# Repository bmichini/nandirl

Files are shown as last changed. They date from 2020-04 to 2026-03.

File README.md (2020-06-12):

# nandirl
Project documentation can be found at [bmichini.github.io/nandirl](https://bmichini.github.io/nandirl/) 

## License
The hardware design files and software tools found in this repository are open source and released under the [Creative Commons Attribution-ShareAlike 4.0 International License](http://creativecommons.org/licenses/by-sa/4.0/) (CC BY-SA 4.0)

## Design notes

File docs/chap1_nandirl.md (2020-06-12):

## Chapter 1: 1-bit Register
One of the most basic things a computer needs to do is remember things, and it does this by storing "bits" i.e. 0's and 1's. One of the core components of a computer processor that performs this remembering function is called a "register". A 1-bit register has the ability to store 1-bit of information, i.e. it remembers whether it is currently a 0 or currently a 1. There are a few key details of a 1-bit register:

* **Input:** The register takes a digital input, which in the case of the nandirl computer is a 3.3V signal that is either low (0V-0.8V, representing a 0) or high (2.0V-3.3V, representing a 1).
* **Load:** The register does not always "listen" to its input. The Load signal (again, a digital 3.3V signal) tells the register whether to accept the input (Load=1) or ignore the input (Load=0) and retain its current value. The reason is that there will always be some signal on the input, but the computer may not always want a register to store that signal at the current instruction cycle.
* **Output:** The output signal (digital 3.3V signal) represents the current stored state of the register. It always outputs either low (0V) or high (3.3V) corresponding to its current stored value.
* **Clock:** Components in the computer that retain their internal state over time (like registers, which retain their "0" or "1" state) are termed "sequential logic" devices because they require a clock signal to synchronize discrete instants when something should happen. In the case of the register, there needs to be a distinct instant in time when the register updates it's new output (based on the Input and Load signals). The Clock input is the thing that signals this instant in time. Specifically, the clock signal is constantly pulsing from high to low to high to low (like a square wave), and the register uses the instant that the clock signal goes from high to low (the "falling edge") as its cue to update it's output signal based on the Input and Load signals. At all other times the output will not change, for reasons that will become clear later.

The nand2tetris course materials say very little about the actual hardware implementation of a register. The concept of a "Data Flip-flop" (or DFF) is given as a primitive building block without really saying how it works. Luckily, a DFF-based circuit that has a data input and updates its output on a clock signal edge can be implemented from NAND gates (with the help of the internet, of course). I based my DFF NAND implementation on [this helpful site](https://www.electronics-tutorials.ws/sequential/seq_4.html). The image below shows the implementation, a Data Flip-Flop followed by a Set-Reset Flip-Flop. The DFF is essentially the input stage, it is listening to the Data input when the clock is high. The instant the clock goes low the DFF stops listening to its input and a few nanoseconds later (the propagation delay from the Not gate on the clock input) the SRFF starts listening to its inputs, setting the overall output of the register. Hence the output updates itself precisely on the falling edge (the transition from high to low) of the clock signal.

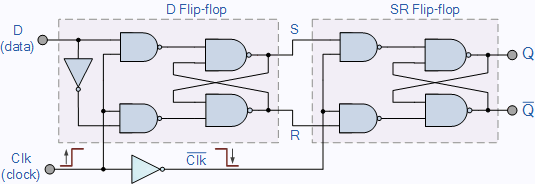
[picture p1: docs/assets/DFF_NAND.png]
DFF SR Latch circuit


Source: [https://www.electronics-tutorials.ws/sequential/seq_4.html](https://www.electronics-tutorials.ws/sequential/seq_4.html)

This doesn't take into account the Load input, which is achieved via the use of another basic circuit, the "Mux". The Mux has three inputs and one output:
A: A digital 3.3V signal that represents 1-bit input A
B: A digital 3.3V signal that represents 1-bit input B
Sel: A digital 3.3V signal that indicates whether the output should be A (Sel=0) or B (Sel=1)
Output: Digital 3.3V signal that is set to either A or B, depending on Sel

The Mux can also be implemented using three NAND gates, as shown in the circuit below. In the circuit, S is short for Sel, and S' means "not S", i.e. if S=0 then S'=1 and vice versa. To generate "not S", a 4th NAND gate is required to act as a "Not" gate, or a gate that simply inverts its own input. A Not gate can be made from a NAND gate by simply connecting the same input signal to both inputs of the NAND gate.

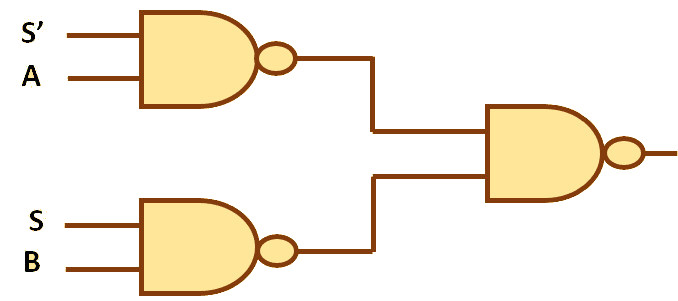
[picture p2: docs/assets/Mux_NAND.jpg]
Mux NAND gate implementation


Putting the DFF-SR and Mux circuits together, we get the fully-functional 1-bit register. Below is the full *schematic* for the circuit. A circuit schematic effectively captures the design of the circuit using boxes and symbols to represent devices, and wires to represent the connections between device pins:

[Schematic]
You'll notice that the NAND gates come in groups of four, and that's because the integrated circuit I've chosen to base the whole computer on incorporates 4 NAND gates into one chip. The [SN74ALVC00](https://www.digikey.com/product-detail/en/texas-instruments/SN74ALVC00DR/296-5101-1-ND/373963) is a 3.3V device made by Texas Instruments. I chose it because it has 4 gates in one package (to keep overall circuit board size down), it can drive up to 50mA of output current, and it has a very low maximum propagation delay of 3 nanoseconds. Propagation delay is the amount of time it takes for the device to generate the correct output after its two inputs are set. Once the full computer is built out signals are going to have to make their way through a lot of these gates in series, so the lower the propagation delay the faster signals will move through the computer and, ultimately, the faster the computer will be.

In summary, a 1-bit register circuit takes 12 total NAND gates to implement (8 for the DFF-SR circuit, and 4 for the Mux), and can be encapsulated into this functional block:
[Heir circuit]

Here's a video showing a breadboard prototype of the circuit using larger DIP versions of the quad NAND chips. The Red LED is connected to the output, Green is Load, Yellow is Input, and Blue is Clock. You'll notice that the output doesn't change until the clock goes from On to Off (the falling edge). When this happens, the Output will either match the current Input (if Load is On), or it will keep its previous value (if Load is Off). FYI The little red switches that I'm using to set Input and Load are called "DIP switches". Having designed and prototyped a 1-bit register, the next chapter will put 16 of these together to form a 16-bit register, and go through the process of designing a printed circuit board (PCB) that can be custom manufactured!

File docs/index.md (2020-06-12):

# nandirl
**nandirl** is a real-life open hardware implementation of the [nand2tetris](https://www.nand2tetris.org/) "Hack" computer architecture using custom printed circuit boards and discrete NAND gates. To my knowledge, this is the first NAND-based hardware implementation of the Hack computer. The hardware design is modular, so that individual boards roughly correspond to the project assignments presented in the nand2tetris course. I used the free and open source [KiCad](https://kicad-pcb.org/) design suite for schematic capture and PCB design. Blog-style chapters explaining the nandirl design are accompanied by tutorials intended to cover the basics of DIY hardware design.

>**Before you dig in, a quick request:**
> I built this project during the global COVID-19 pandemic and the ensuing months-long stay-at-home order. I am very fortunate to be in a position where I can work remotely during the day and also have the means to work on this project at night. I am grateful for that opportunity, but also realize that it is a privilege that many in my community do not have. Underserved communities have been disproportionately affected by the COVID outbreak for many reasons, including the financial necessity to continue working high-exposure jobs throughout the pandemic and the many institutional disadvantages that lead to worse health outcomes. In recognition of this, for every $1 that I spent on hardware and components for this project, I donated $1 spread across the charities in my area (listed below) that have been assisting the underserved through the COVID crisis. If you find this project interesting and you have the financial means to contribute, I'd encourage you to donate to these organizations or similar charities in your area. Thanks for your consideration!

## Table of Contents
For those curious about how the hardware was designed and built, the chapters below are my best attempt at documenting the project. Each chapter has a nandirl design component, followed by a generic hardware design component. The latter may be useful for hobbyists interested in the overall process of going from a circuit idea to a working PCB. For the HW design components, the free/open source KiCad suite is used.

**Disclaimer:** I am definitely not an expert when it comes to hardware design. It is not my day job. My credentials are based solely on informal DIY experience and bumbling trial-and-error. Consider yourself warned!

| Chapter | nandirl | HW design |
| --- | --- | --- |
| 0 | Intro: The nand2tetris "Hack" Architecture | Intro: DIY Hardware Design Overview |
| 1 | 1-bit Register | Schematic Capture and Custom Components |
| 2 | 16-bit Register | Nets and Heirarchical Schematics |
| 3 | Program Counter | Component Selection (Digikey+Datasheets) |
| 4 | Read-only Memory (ROM) | PCB Layout and Routing |
| 5 | Random Access Memory (RAM) | Design Checks and Fabrication Outputs |
| 6 | Arithmetic Logic Unit (ALU) | PCB Fabrication, BOMs, and Stencils |
| 7 | Clock Generator | PCB Assembly, Hotplate, and Solder Bridges |
| 8 | Motherboard | Board Bring-up Checklist |
| 9 | Debugger | Rework (Nothing Works the First Time) |
| 10 | Running Programs | Useful Equipment, Tools, and Toys |

## License
The hardware design files and software tools found in this repository are open source and released under the [Creative Commons Attribution-ShareAlike 4.0 International License](http://creativecommons.org/licenses/by-sa/4.0/) (CC BY-SA 4.0)

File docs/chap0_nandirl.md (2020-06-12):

## Chapter 0: nand2tetris and the "Hack" computer architecture
Recently I've been obsessed with the Apollo spaceflight program, and of particular fascination to me is the Apollo Guidance Computer (AGC). There's a whole lot to say on the topic, but for the purposes of this introduction: I was reading one day that the logic circuits of the AGC are constructed entirely from NOR (Not OR) gates. What's a NOR gate? How could you make a computer out of them? What are logic circuits? That's when it hit me -- even though I've been programming them for over 20 years, *I have no idea how computers actually work in hardware*. I decided that I could no longer continue living in ignorance of a technology that so profoundly shapes our everyday lives. So I have endeavored to learn how computers work by constructing one from primitive logic gates, but instead of the NOR gates used on the AGC my computer will be made from NAND (Not AND) gates.

Starting out I obviously had no idea what goes into the design of such a computer, but luckily there are some wonderful and generous people out there who have gone out of their way to provide a comprehensive and free online course on the topic. The design I'll be using for my computer is based on the [nand2tetris](https://www.nand2tetris.org/) project that guides students through the architecture of a simple computer based on NAND gates, which the authors have named the "Hack" computer. If you're wondering what a NAND gate is, [this is a good place to start](https://logic.ly/lessons/nand-gate/). The lectures subsequently take students through the software implementation of Tetris for the Hack computer design. The course is awesome and I highly recommend it to anyone who wants to learn how computers work from the ground up. Given that the syllabus is focused on computer hardware and software *design*, there is no actual hardware and instead the computer is constructed using software that simulates hardware. The instructors don't focus on how you would build this computer *in real life*, and I haven't been able to find anyone on the internet who has actually done it. Hence I've named my project **nandirl**.

The remainder of this chapter is a high-level overview of the computer architecture that may be helpful in understanding how all of the components will ultimately fit together. Check out the [nand2tetris](https://www.nand2tetris.org/) course for a better explanation (it assumes no previous technical training or computer knowledge). 

If we zoom out all the way, our computer consists of these three main components:
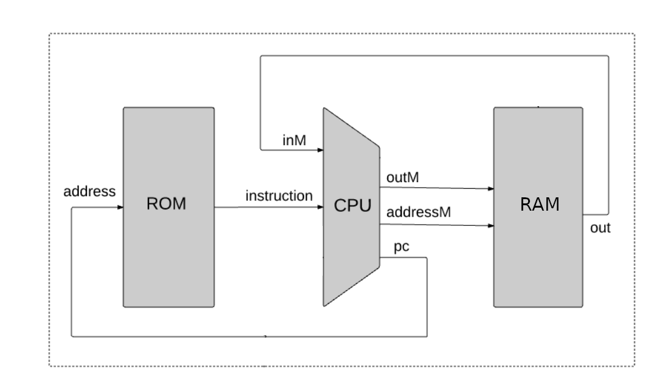
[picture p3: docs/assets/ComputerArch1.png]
Basic Computer Architecture
 
Source: [https://www.nand2tetris.org/course](https://www.nand2tetris.org/course) 
### ROM
ROM stands for "Read Only Memory". The ROM chip has a simple job in life -- given an *address*, the ROM provides an *instruction*. An address is simply a number, as is an instruction. Abstractly, imagine the ROM chip as a filing cabinet with many folders inside of it. The ROM chip gets an address, looks for the folder with the matching label, and hands back the contents of that folder (the instruction).

>More concretely, computers store numbers in *binary*. What's binary? The decimal number 5 in binary is **101**, because:
>
>**1**x2<sup>2</sup> + **0**x2<sup>1</sup> + **1**x2<sup>0</sup> =  **1**x4 + **0**x2 + **1**x1 = 5. 
>
>Since we've used three powers of 2, this is a *3-bit *binary number. The more powers of two we use the more numbers we can represent with our computer. The Hack computer, and thus the nandirl computer, is a *16-bit architecture*. Thus the smallest (unsigned) number we can represent is **0000 0000 0000 0000**:
>
 >**0**x2<sup>15</sup> +**0**x2<sup>14</sup> + **0**x2<sup>13</sup> + **0**x2<sup>12</sup>+ **0**x2<sup>11</sup> +**0**x2<sup>10</sup> + **0**x2<sup>9</sup> + **0**x2<sup>8</sup>+ **0**x2<sup>7</sup> +**0**x2<sup>6</sup> + **0**x2<sup>5</sup> + **0**x2<sup>4</sup>+ **0**x2<sup>3</sup> +**0**x2<sup>2</sup> + **0**x2<sup>1</sup> + **0**x2<sup>0</sup> = 0
>
>and largest (unsigned) number our computer can represent is **1111 1111 1111 1111**:
>
 >**1**x2<sup>15</sup> +**1**x2<sup>14</sup> + **1**x2<sup>13</sup> + **1**x2<sup>12</sup>+ **1**x2<sup>11</sup> +**1**x2<sup>10</sup> + **1**x2<sup>9</sup> + **1**x2<sup>8</sup>+ **1**x2<sup>7</sup> +**1**x2<sup>6</sup> + **1**x2<sup>5</sup> + **1**x2<sup>4</sup>+ **1**x2<sup>3</sup> +**1**x2<sup>2</sup> + **1**x2<sup>1</sup> + **1**x2<sup>0</sup> = 65535
>
>As it turns out, we can also represent every number in between with the right combination of 16 **1**'s and **0**'s, i.e. by adding the right combination of powers of 2 between 2<sup>0</sup> and 2<sup>15</sup>! 

Back to the ROM chip. The *address* passed into the ROM chip takes the form of 16 digital electrical signals, each at either a low voltage (representing a 0) or a high voltage (representing a 1). That corresponds to a 16-bit binary number, thus our ROM chip can store 65536 unique instructions! The *instruction* output, similarly, takes the form of 16 digital electrical signals. Each of those 16 individual instruction signals are going to tell the CPU what to do.

So to recap, ROM gets a 16-bit address. It finds that address in its filing cabinet and outputs the contents, which happens to be another set of 16 bits. Get a new address, look in a new memory location, send out a new instruction. In real life the 16 bits are represented as either high or low voltage (electrical potential) transmitted via 16 tiny metal wires going into the chip and 16 going out. It's called *read-only* memory because the contents of the memory does not change throughout the course of the computer's execution (it can only be *read*, not *written*). The 16-bits of instruction will go on to tell the CPU what to do, hence the ROM chip contains the *program* that the computer will execute. As a final note, ROM chips retain their memory even when the computer is powered off, so that the ROM will reliably provide the same addressed instruction data each and every time the computer is turned on.

### RAM
RAM stands for "Random Access Memory". It is very similar to ROM, in that it stores 16-bit numbers in filing cabinets that are indexed by 16-bit addresses. Get a 16-bit address, output the 16-bit number stored at that address. The thing that makes RAM different from ROM is that you can *write* a value to an address as well as *read* a value from an address. The chip uses to the same set of incoming address bits whether it's reading or writing. In order to know what value to write to memory, the RAM chip has 16-bits of data *input*. Hence there are two lines going into the RAM chip (*address* and *data input*) and one coming out (*data output*). 

In the computer architecture, the input *to* the RAM chip comes from the output of the CPU (hence it's labeled "outM" or "out to Memory" in the diagram). The output *from* the RAM chip goes...back into the CPU! This may seem odd, but the CPU is effectively using the RAM as short-term memory. The RAM doesn't store a program like ROM does -- in fact, all of the data stored in RAM resets to some unpredictable state every time the computer turns off. The RAM does, however, provide 65536 readable and writeable memory locations for the CPU to store and fetch 16-bit numbers during program execution. This comes in handy when the CPU does calculations and needs to store the result for use later on.

### CPU
So far the ROM and RAM chips appear only to store data. The CPU is where that data is manipulated. Here's a diagram showing the internals of the Hack CPU:
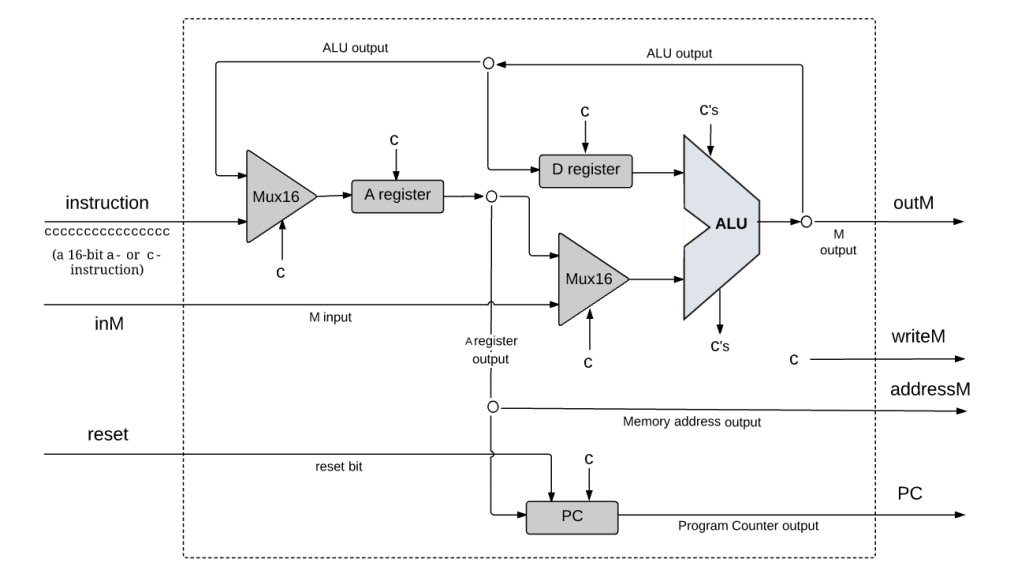
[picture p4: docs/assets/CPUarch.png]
Hack CPU Architecture

Source: [https://www.nand2tetris.org/course](https://www.nand2tetris.org/course) 
#### ALU
A good place to start breaking down the CPU architecture is the ALU, or Arithmetic Logic Unit. The ALU takes two 16-bit inputs, and provides one 16-bit output. As we'll see in more detail in a subsequent chapter, the ALU performs an operation on the two inputs and sends the result to its output. The ALU is designed to perform many different operations, and it knows which one to perform based on the instruction inputs (labeled "c's" going into the top of the ALU). These instructions are a subset of the 16 instruction bits that the ROM passes into the CPU. 

One such operation is simply to add the two inputs together (*x+y*). So if the first input *x* is 2 (**0000 0000 0000 0010**) and the second input *y* is 3 ((**0000 0000 0000 0011**), the output will be 5 (**0000 0000 0000 0101**). These 16 output bits are sent out to the RAM input (labeled "outM" or "out to memory"), but are also fed back into the other components of the CPU.

You may also notice that there are a few "c" bits coming out of the ALU as well as going in. These indicate whether the 16-bit number in the output is zero, or if it is negative. These checks on the output are going to ultimately determine what instuction (i.e. what address being sent to ROM) is picked out for execution in the next cycle.
#### Register
There are two registers (**A** and **D**) in the CPU. You can think of a register like RAM -- it holds a 16-bit number that can be read or written to. Except unlike our RAM which has 65536 addressable read/write values, a register has only *one*. This may seem like a serious limitation, but registers are very useful as a location to quickly store or read a single 16-bit number. Register has a 16-bit input, a 16-bit output, and a 1-bit *load* input. When *load*=1 (high voltage) the input will be saved and the output will take that value. When *load*=0 (low voltage), the input will be ignored and the output will keep its previous value. Just like the ALU, the *load* signal is set at each cycle by the incoming instruction bits.

In the CPU architecture, the **D** register simply holds data that will be used as the first input to the ALU. Notice that the output of the ALU winds back around into the input of the **D** register. If the corresponding instruction bit is set (the "c" bit that controls whether the register will load from the input), the ALU ouput will be saved back into the **D** register.

The **A** register can be used in the same was as **D** i.e. as the *second* input to the ALU, and the output from the ALU can be stored back into **A**. However, the **A** register also has a very specific and special function. Its output value sets the *address* that will be used for RAM. It also serves as the input to the PC register, which will be explained next.

#### PC (Program Counter)
At its core the Program Counter is simply a register just like **A** and **D**, in that it has an input that is optionally saved to its output at each step. The output of the **PC** is fed to the address input of the ROM chip. Hence, the program instruction that is going to be served up to the CPU in the next cycle is determined by the current output of the **PC** (that why it's called the *Program Counter*). If its *load* bit is set, it will save its input to its output (and recall that its input is the output of the **A** register). In that case the **PC** will take on this entirely new value and the next instruction will be from that new address. The program is said to have *jumped* to this new address. Otherwise, the **PC** has a neat feature that will automatically add 1 to its current value, effectively executing the *next* instruction in the ROM program memory.

This ability for the CPU to either *jump* to a new instruction or simply execute the *next* instruction is a fundamental feature of the CPU. This gives our program the ability to execute *conditional* statements i.e. jump to some new line of the program when some condition is true, or otherwise just keep on going to the next line of the program. If you're familiar with programming, this feature is the basis for building blocks such as *if*/*then*/*else*, *for*, *while*, etc. Recall that the **PC** will cause the program to jump if its *load* bit is set. It turns out that the CPU will set the *load* bit based on both the current instruction bits *and* the "zero" and "negative" checks that the ALU performs. Hence we'll have the ability in our program to do an ALU calculation and decide to jump or not based on the ALU result.

You may also notice a *reset* signal feeding into the **PC**. This is a 1-bit instruction that, when set to 1, will reset the current value of the **PC** to zero i.e. back to the beginning of our program.

#### Mux
The final component in the architecture is the **Mux**, which is short for "multiplexor". A Mux takes two inputs (*A* and *B*), and uses its incoming instruction bit (called the *select* input) to decide how to set its output. If *sel*=0, the output is set to *A*. If *sel*=1, the output is set to *B*. This will give our computer the ability to select whether the **A** register is loaded with the ALU output or the entire current instruction value (loading the entire 16-bits of instruction into **A** gives us the ability to store a number from our program straight into **A**). It also gives our computer the ability to select whether the second input to the ALU is the **A** register, or the current RAM value. As you probably guessed, the select bits for the two Muxes are set by the current CPU instruction coming from ROM.

***

Believe it or not, those are the only building blocks needed to create a simple computer from the ground up. We'll write programs for our computer, store them as addressed instructions in ROM, and let the computer execute them one-by-one. In my mind, at least, I think about this process like building a wind-up a toy, winding it up, putting it down, and letting it march its way through the world. In subsequent chapters I'll be building out each one of the major components in this architecture in real hardware.

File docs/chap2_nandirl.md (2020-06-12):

## Chapter 2: 16-bit Register
The nand2tetris computer is a 16-bit architecture. That means that data is passed around, stored, and manipulated in groups of 16-bits. The first full component of the computer I decided to take on is the 16-bit Register. It is, quite simply, a board that contains 16 1-bit registers where each register has its own Input and Output signals, but the Load and Clock signals are shared between all of them.

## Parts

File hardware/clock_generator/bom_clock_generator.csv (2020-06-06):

Reference | Quantity | Value | Footprint | Datasheet | Digikey PN
C1 | 1 | 22pF | Capacitor_THT:C_Disc_D5.0mm_W2.5mm_P5.00mm | ~
C3 C4 | 2 | 100uF | Capacitor_THT:CP_Radial_D8.0mm_P2.50mm | ~ | P15797CT-ND
C5 C6 | 2 | 100nF | Capacitor_THT:C_Disc_D5.0mm_W2.5mm_P5.00mm | ~ | BC5229CT-ND
C7 C2 | 2 | 0.1uF | Capacitor_SMD:C_1206_3216Metric | ~ | 399-C1206C104K5RAC7800CT-ND
J1 | 1 | DB9_Male | Connector_Dsub:DSUB-9_Male_Horizontal_P2.77x2.84mm_EdgePinOffset7.70mm_Housed_MountingHolesOffset9.12mm | ~ | AE10968-ND
R1 | 1 | 2.7K | Resistor_THT:R_Axial_DIN0207_L6.3mm_D2.5mm_P10.16mm_Horizontal | ~
R2 | 1 | 27K | Resistor_THT:R_Axial_DIN0207_L6.3mm_D2.5mm_P10.16mm_Horizontal | ~
R3 R5 | 2 | 33 | Resistor_SMD:R_1206_3216Metric | ~ | P33ECT-ND
R4 | 1 | 5k | Resistor_SMD:R_1206_3216Metric | ~ | P5.1KECT-ND
RV1 | 1 | 1M | Potentiometer_THT:Potentiometer_Bourns_PTV09A-1_Single_Vertical | ~ | PTV09A-4225F-B104-ND
TP1 TP4 TP3 TP2 | 4 | TestPoint | TestPoint:TestPoint_Bridge_Pitch2.54mm_Drill1.0mm | ~
U3 U1 U2 U4 | 4 | SN74HCS00PWR | Package_SO:TSSOP-14_4.4x5mm_P0.65mm |  | 296-SN74HCS00PWRCT-ND
U5 U6 | 2 | PI6C49CB04AQ | Package_SO:SOIC-8_3.9x4.9mm_P1.27mm |  | 31-PI6C49CB04AQ2WEXCT-ND

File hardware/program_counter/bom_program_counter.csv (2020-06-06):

Reference | Quantity | Value | Footprint | Datasheet | Digikey PN
C1 | 1 | 100uF | Capacitor_THT:CP_Radial_D8.0mm_P2.50mm | ~ | P15797CT-ND
C2 | 1 | 100nF | Capacitor_THT:C_Disc_D5.0mm_W2.5mm_P5.00mm | ~ | BC5229CT-ND
D15 D14 D13 D12 D11 D10 D9 D8 D7 D6 D5 D4 D3 D1 D2 D16 | 16 | LED | LED_THT:LED_D5.0mm | ~
J1 | 1 | DB37_Male | Connector_Dsub:DSUB-37_Male_Horizontal_P2.77x2.84mm_EdgePinOffset7.70mm_Housed_MountingHolesOffset9.12mm | ~ | AE10986-ND
R16 R1 R2 R3 R4 R5 R6 R7 R8 R9 R10 R11 R12 R13 R14 R15 | 16 | 1K | Resistor_SMD:R_1206_3216Metric | ~ | P1.0KECT-ND
U76 U10 U9 U8 U7 U6 U15 U14 U13 U12 U11 U20 U19 U18 U17 U16 U25 U24 U23 U22 U21 U30 U29 U28 U27 U26 U35 U34 U33 U32 U31 U40 U39 U38 U37 U36 U45 U44 U43 U42 U41 U50 U49 U48 U47 U46 U55 U54 U53 U52 U51 U60 U59 U58 U57 U56 U65 U64 U63 U62 U61 U70 U69 U68 U67 U66 U5 U4 U3 U2 U1 U75 U74 U73 U72 U71 | 76 | SN74HCS00PWR | Package_SO:TSSOP-14_4.4x5mm_P0.65mm |  | 296-SN74HCS00PWRCT-ND

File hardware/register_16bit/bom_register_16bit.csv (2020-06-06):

Reference | Quantity | Value | Footprint | Datasheet | Digikey PN
C1 | 1 | 100uF | Capacitor_THT:CP_Radial_D8.0mm_P2.50mm | ~ | P15797CT-ND
C2 | 1 | 100nF | Capacitor_THT:C_Disc_D5.0mm_W2.5mm_P5.00mm | ~ | BC5229CT-ND
D1 D2 D3 D4 D5 D6 D7 D8 D9 D10 D11 D12 D13 D14 D15 D16 D17 | 17 | LED | LED_THT:LED_D5.0mm | ~
J1 | 1 | DB37_Male | Connector_Dsub:DSUB-37_Male_Horizontal_P2.77x2.84mm_EdgePinOffset7.70mm_Housed_MountingHolesOffset9.12mm | ~ | AE10986-ND
R1 R17 R2 R3 R4 R5 R6 R7 R8 R9 R10 R11 R12 R13 R14 R15 R16 | 17 | 1K | Resistor_SMD:R_1206_3216Metric | ~ | P1.0KECT-ND
U1 U2 U3 U4 U5 U6 U7 U8 U9 U10 U11 U12 U13 U14 U15 U16 U17 U18 U19 U20 U21 U22 U23 U24 U25 U26 U27 U28 U29 U30 U31 U32 U33 U34 U35 U36 U37 U38 U39 U40 U41 U42 U43 U44 U45 U46 U47 U48 U49 | 49 | SN74HCS00PWR | Package_SO:TSSOP-14_4.4x5mm_P0.65mm |  | 296-SN74HCS00PWRCT-ND

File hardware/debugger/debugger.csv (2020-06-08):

Reference | Quantity | Value | Footprint | Datasheet | Digikey PN
C1 C2 C3 C4 C5 C6 C7 C8 C9 C10 C11 C12 | 12 | 0.1uF | Capacitor_SMD:C_1206_3216Metric | ~ | 399-C1206C104K5RAC7800CT-ND
J2 J1 | 2 | DB37_Male | Connector_Dsub:DSUB-37_Male_Horizontal_P2.77x2.84mm_EdgePinOffset7.70mm_Housed_MountingHolesOffset9.12mm | ~ | AE10986-ND
J3 | 1 | RJ45_Amphenol_RJMG1BD3B8K1ANR | Connector_RJ:RJ45_Amphenol_RJMG1BD3B8K1ANR | https://www.amphenolcanada.com/ProductSearch/Drawings/AC/RJMG1BD3B8K1ANR.PDF | RJMG1BD3B8K1ANR-ND
U1 | 1 | Teensy4.1 | nandirl logo:Teensy41
U10 U11 | 2 | PI6C49CB04AQ | Package_SO:SOIC-8_3.9x4.9mm_P1.27mm |  | 31-PI6C49CB04AQ2WEXCT-ND
U2 U3 U4 U5 U6 U7 U8 U9 | 8 | SN74CBTLV3257PWR | Package_SO:TSSOP-16_4.4x5mm_P0.65mm |  | 296-9138-1-ND

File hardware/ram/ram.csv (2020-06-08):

Reference | Quantity | Value | Footprint | Datasheet | Digikey PN
C2 C1 | 2 | 100uF | Capacitor_THT:CP_Radial_D8.0mm_P2.50mm | ~ | P15797CT-ND
C3 C4 | 2 | 100nF | Capacitor_THT:C_Disc_D5.0mm_W2.5mm_P5.00mm | ~ | BC5229CT-ND
C6 C5 C7 C8 | 4 | 0.1uF | Capacitor_SMD:C_1206_3216Metric | ~ | 399-C1206C104K5RAC7800CT-ND
J1 | 1 | RJ45_Amphenol_RJMG1BD3B8K1ANR | Connector_RJ:RJ45_Amphenol_RJMG1BD3B8K1ANR | https://www.amphenolcanada.com/ProductSearch/Drawings/AC/RJMG1BD3B8K1ANR.PDF | RJMG1BD3B8K1ANR-ND
J3 | 1 | DB25_Male | Connector_Dsub:DSUB-25_Male_Horizontal_P2.77x2.84mm_EdgePinOffset7.70mm_Housed_MountingHolesOffset9.12mm | ~ | AE10980-ND
J4 | 1 | DB37_Male | Connector_Dsub:DSUB-37_Male_Horizontal_P2.77x2.84mm_EdgePinOffset7.70mm_Housed_MountingHolesOffset9.12mm | ~ | AE10986-ND
U1 | 1 | 71V016SA12PHGI | Package_SO:TSOP-II-44_10.16x18.41mm_P0.8mm |  | 800-2609-5-ND
U12 | 1 | Teensy4.1 | nandirl logo:Teensy41
U3 U2 U4 U11 | 4 | SN74HCS00PWR | Package_SO:TSSOP-14_4.4x5mm_P0.65mm |  | 296-SN74HCS00PWRCT-ND
U7 U10 U6 U9 U5 U8 | 6 | 74LCX573FT | Package_SO:TSSOP-20_4.4x6.5mm_P0.65mm |  | 74LCX573FT(AJ)CT-ND

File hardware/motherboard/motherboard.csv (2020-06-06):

Reference | Quantity | Value | Footprint | Datasheet | Digikey PN
C1 | 1 | 220uF | Capacitor_THT:CP_Radial_D10.0mm_P5.00mm | ~ | P5183-ND
C2 C3 | 2 | 100uF | Capacitor_THT:CP_Radial_D8.0mm_P2.50mm | ~ | P15797CT-ND
C4 C5 | 2 | 100nF | Capacitor_THT:C_Disc_D6.0mm_W2.5mm_P5.00mm | ~ | BC5229CT-ND
D1 D2 D3 D4 D5 D6 D7 D8 D9 D10 D11 D12 D13 D14 D15 D16 D17 | 17 | LED | LED_SMD:LED_1206_3216Metric | ~ | 516-1436-1-ND
J12 | 1 | Barrel_Jack | Connector_BarrelJack:BarrelJack_CUI_PJ-063AH_Horizontal | ~ | CP-063AH-ND
J13 | 1 | TSR 1-2433 | Connector_PinHeader_2.54mm:PinHeader_1x03_P2.54mm_Vertical | ~ | 1951-2430-ND
J2 J1 J3 J4 J5 J10 J11 J7 | 8 | DB37_Female | Connector_Dsub:DSUB-37_Female_Horizontal_P2.77x2.84mm_EdgePinOffset7.70mm_Housed_MountingHolesOffset9.12mm | ~ | AE10941-ND
J6 J8 | 2 | DB25_Female | Connector_Dsub:DSUB-25_Female_Horizontal_P2.77x2.84mm_EdgePinOffset7.70mm_Housed_MountingHolesOffset9.12mm | ~ | AE10935-ND
J9 | 1 | DB9_Female | Connector_Dsub:DSUB-9_Female_Horizontal_P2.77x2.84mm_EdgePinOffset7.70mm_Housed_MountingHolesOffset9.12mm | ~ | AE10921-ND
R1 R2 | 2 | 2K | Resistor_SMD:R_1206_3216Metric | ~ | P2.0KECT-ND
R3 R4 R5 R6 R7 R8 R9 R10 R11 R12 R13 R14 R15 R16 R17 R18 R19 | 17 | 1K | Resistor_SMD:R_1206_3216Metric | ~ | P1.0KECT-ND
SW1 | 1 | SW_SPST | Button_Switch_SMD:SW_SPST_B3S-1000 | ~ | SW415-ND
SW2 | 1 | SW_SPST | nandirl logo:SPST Toggle Switch | ~ | EG4914-ND
U7 U6 U5 U4 U3 U2 U1 U10 U9 U8 U13 U12 U11 U20 U19 U18 U17 U16 U15 U14 U23 U22 U21 U26 U25 U24 U32 U31 U27 U28 U29 U30 | 32 | SN74ALVC00 | Package_SO:TSSOP-14_4.4x5mm_P0.65mm |  | 296-5104-1-ND

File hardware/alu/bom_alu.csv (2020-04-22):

Reference | Quantity | Digikey PN
C2 C1 C5 | 3 | P15797CT-ND
C3 C4 C6 | 3 | BC5229CT-ND
D1 D2 D3 D4 D5 D6 D7 D8 D9 D10 D11 D12 D13 D14 D15 D16 D19 D20 D21 D22 D23 D24 D25 D26 D27 D28 D29 D30 D31 D32 D33 D34 D17 D18 D35 D36 D37 D38 D39 D40 D41 D42 D43 D44 D45 D46 D47 D48 D49 D50 D51 D52 D53 D54 D55 D56 D57 | 57
J3 | 1 | AE10980-ND
J4 | 1 | AE10986-ND
Q1 Q2 | 2 | FMMT614CT-ND
R1 R2 R3 R4 R5 R6 R7 R8 R9 R10 R11 R12 R13 R14 R15 R16 R19 R20 R21 R22 R23 R24 R25 R26 R27 R28 R29 R30 R31 R32 R33 R34 R17 R18 R35 R36 R37 R38 R39 R40 R41 R42 R43 R44 R45 R46 R47 R48 R49 R50 R51 R52 R53 R54 R55 R56 R57 | 57 | P1.0KECT-ND
R58 R59 | 2 | P5.1KECT-ND
U1 U2 U3 U4 U5 U6 U7 U8 U9 U10 U11 U12 U13 U14 U15 U16 U17 U18 U19 U20 U21 U22 U23 U24 U25 U26 U27 U28 U29 U30 U31 U32 U33 U34 U35 U36 U37 U38 U39 U40 U41 U42 U43 U44 U45 U46 U47 U48 U49 U50 U51 U52 U53 U54 U55 U56 U57 U58 U59 U60 U61 U62 U63 U64 U65 U66 U67 U68 U69 U70 U71 U72 U73 U74 U75 U76 U77 U78 U79 U80 U81 U82 U83 U84 U85 U86 U87 U88 U89 U96 U93 U94 U95 U90 U91 U92 U97 U98 U99 U100 U105 U106 U102 U101 U107 U104 U103 U110 U109 U108 U111 U112 U113 U114 U115 U116 U117 U122 U123 U119 U118 U124 U121 U120 U127 U126 U125 U128 U129 U130 U131 U132 U133 U134 U139 U140 U136 U135 U141 U138 U137 U144 U143 U142 U145 U146 U147 U148 U149 U150 U151 U156 U157 U153 U152 U158 U155 U154 U161 U160 U159 U162 U163 U164 U165 U166 | 166 | 296-5104-1-ND

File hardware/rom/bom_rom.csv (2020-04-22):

Reference | Quantity | Digikey PN
C1 | 1 | P15797CT-ND
C2 | 1 | BC5229CT-ND
J1 | 1 | AE10986-ND
R2 R1 R4 R3 | 4 | P5.1KECT-ND
U1 | 1 | SST39VF200A-70-4I-EKE-ND

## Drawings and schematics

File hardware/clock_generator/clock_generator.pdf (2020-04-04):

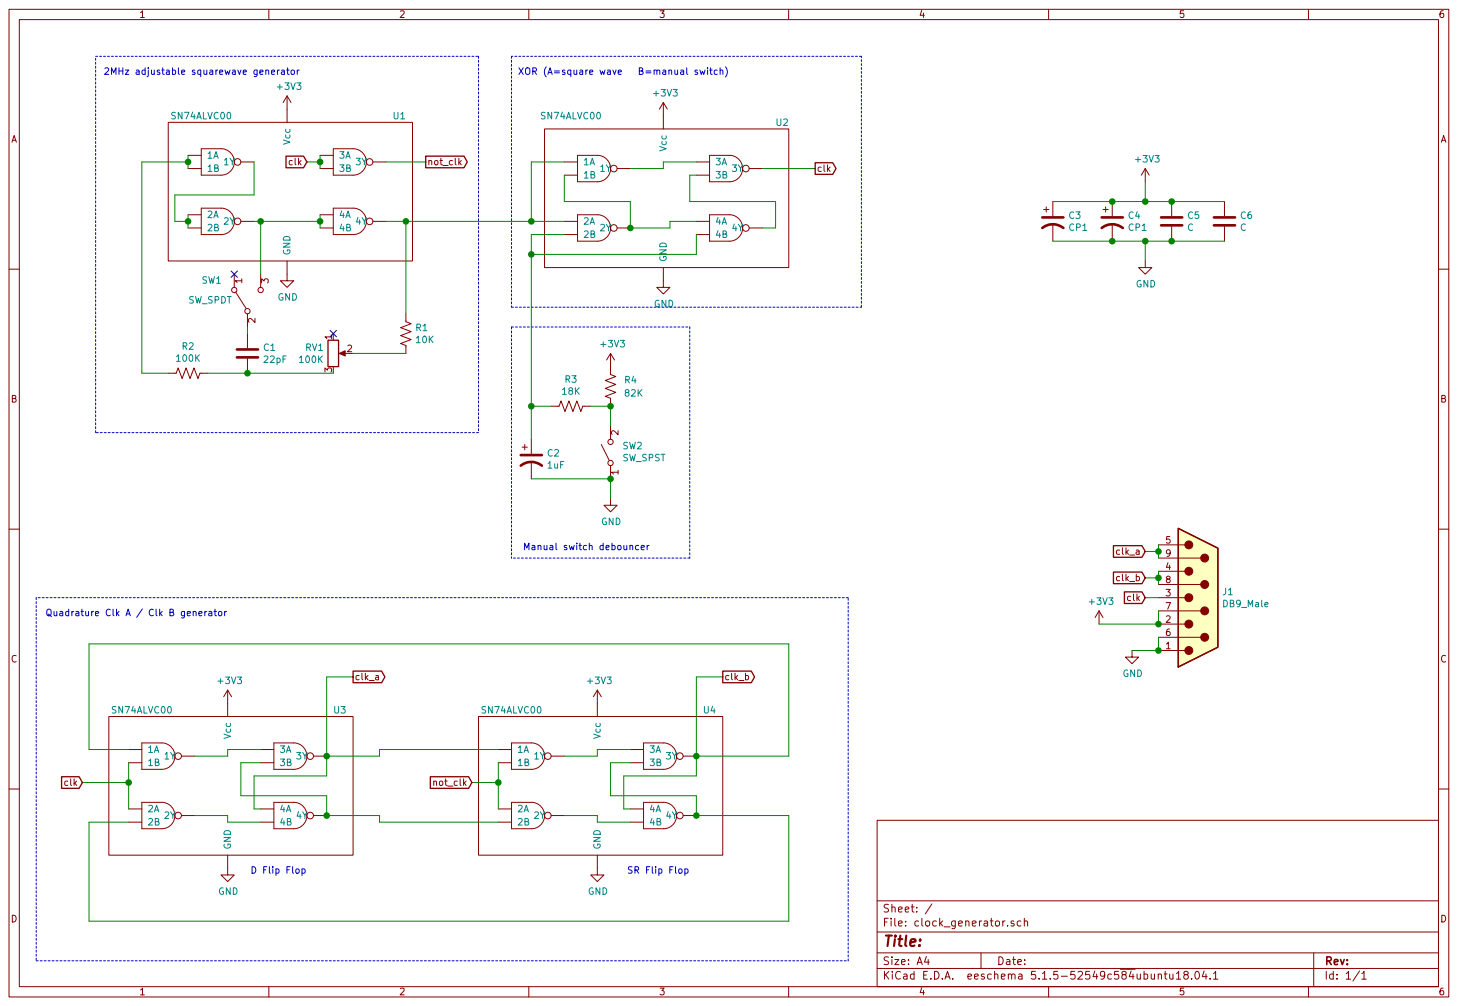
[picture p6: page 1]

XOR (A=square wave B=manual switch) Manual switch debouncer Quadrature Clk A / Clk B generator

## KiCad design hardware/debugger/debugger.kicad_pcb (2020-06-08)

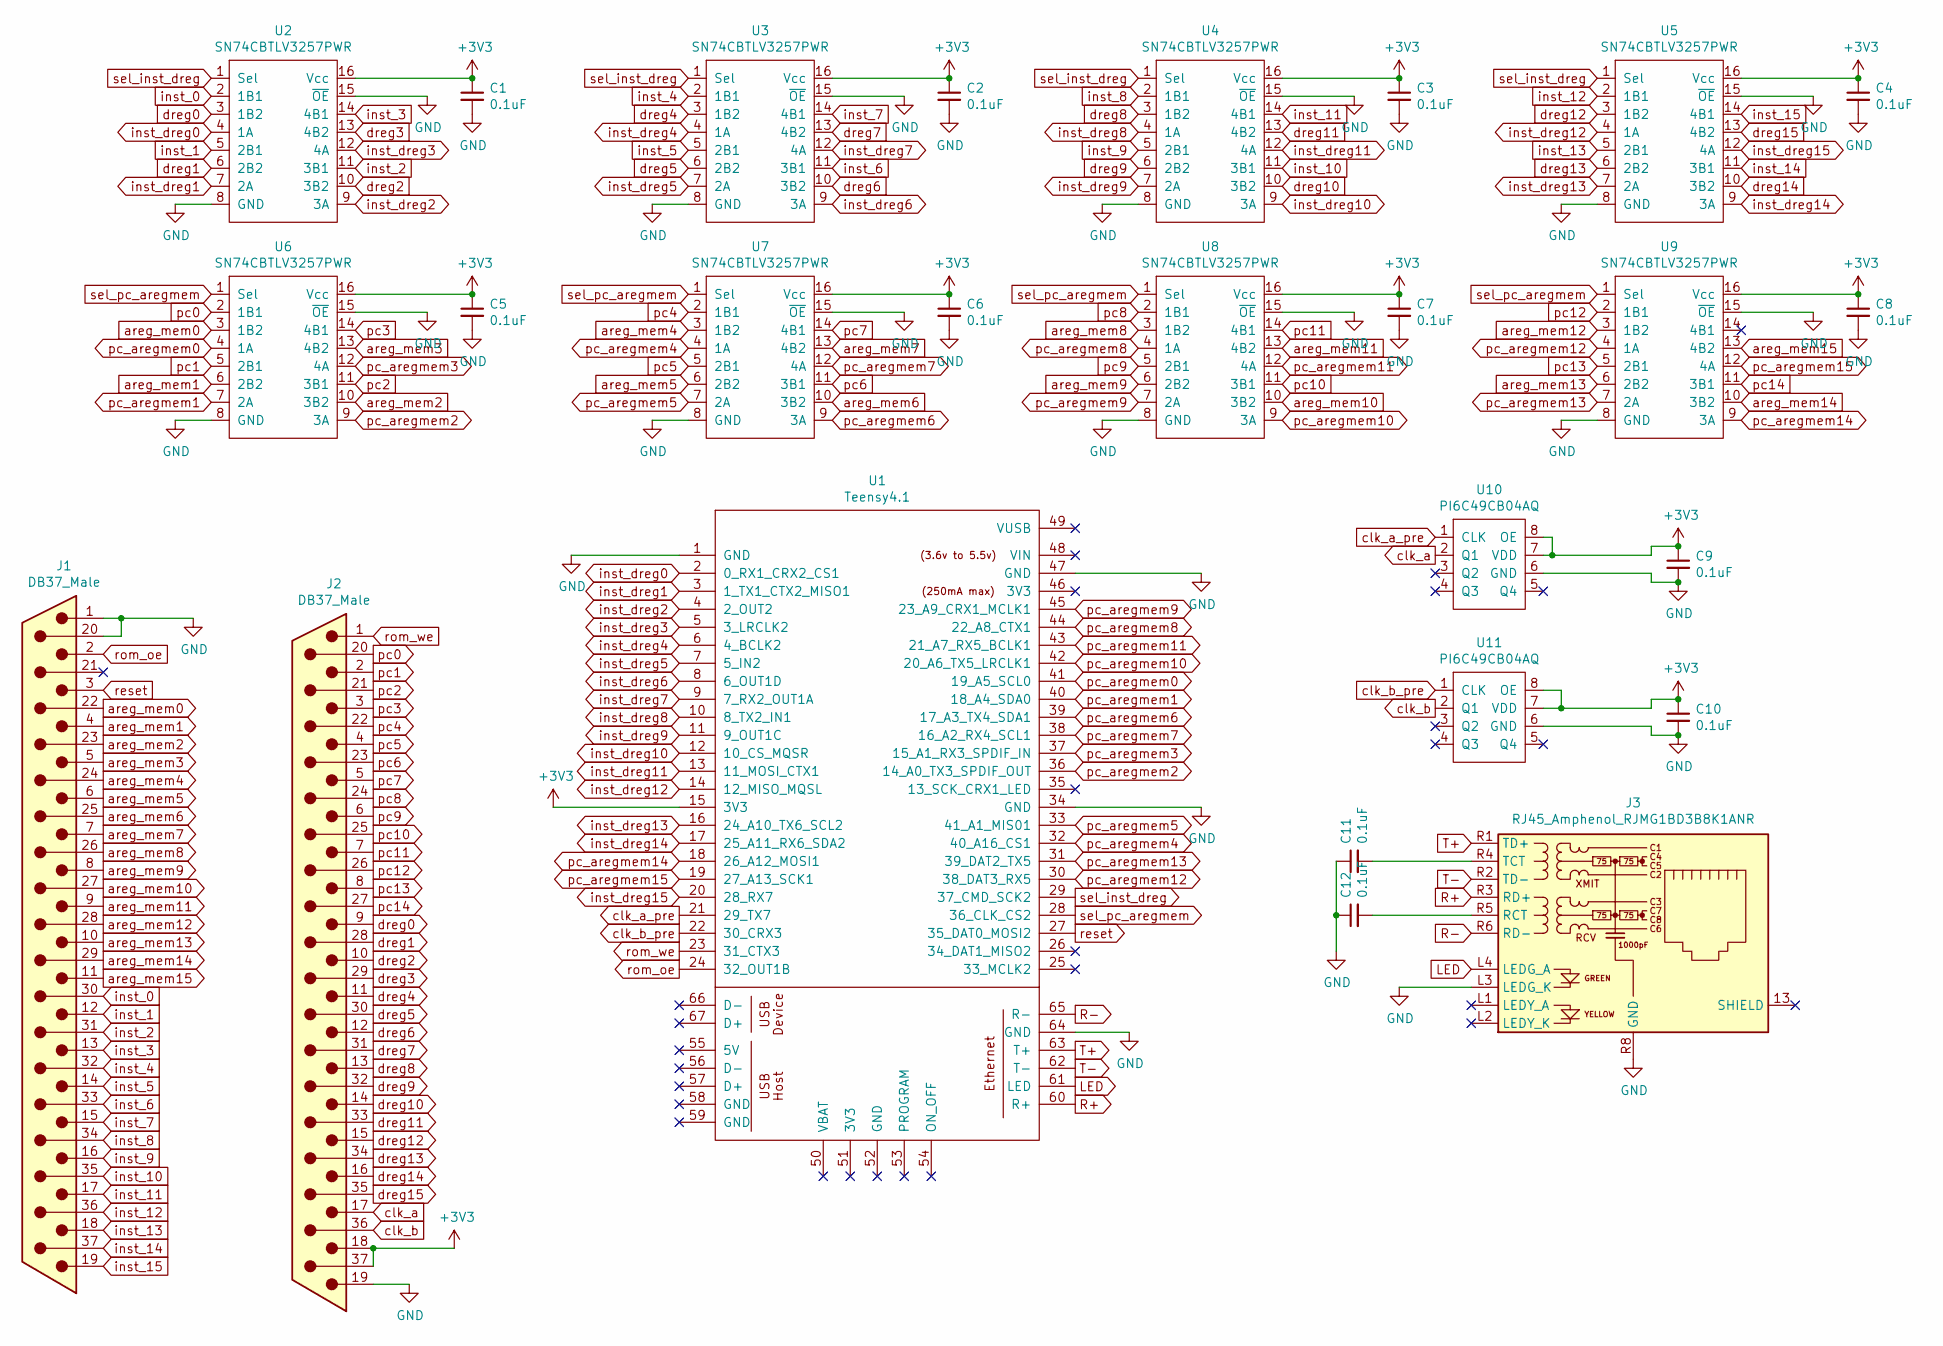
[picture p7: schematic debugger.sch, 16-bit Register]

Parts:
C1, C2, C3, C4, C5, C6, C7, C8, C9, C10, C11, C12: 0.1uF; C_1206_3216Metric; Digikey PN 399-C1206C104K5RAC7800CT-ND
J1, J2: DB37_Male; DSUB-37_Male_Horizontal_P2.77x2.84mm_EdgePinOffset7.70mm_Ho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; Digikey PN AE10986-ND
J3: RJ45_Amphenol_RJMG1BD3B8K1ANR; Digikey PN RJMG1BD3B8K1ANR-ND
U1: Teensy4.1; Teensy41
U2, U3, U4, U5, U6, U7, U8, U9: SN74CBTLV3257PWR; TSSOP-16_4.4x5mm_P0.65mm; Digikey PN 296-9138-1-ND
U10, U11: PI6C49CB04AQ; SOIC-8_3.9x4.9mm_P1.27mm; Digikey PN 31-PI6C49CB04AQ2WEXCT-ND

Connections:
+3V3: C1.1, C2.1, C3.1, C4.1, C5.1, C6.1, C7.1, C8.1, C9.1, C10.1, J2.18, J2.37, U1.15 (3V3), U2.16 (Vcc), U3.16 (Vcc), U4.16 (Vcc), U5.16 (Vcc), U6.16 (Vcc), U7.16 (Vcc), U8.16 (Vcc), U9.16 (Vcc), U10.7 (VDD), U10.8 (OE), U11.7 (VDD), U11.8 (OE)
GND: C1.2, C2.2, C3.2, C4.2, C5.2, C6.2, C7.2, C8.2, C9.2, C10.2, C11.1, C12.1, J1.1, J1.20, J2.19, J3.L3 (LEDG_K), J3.R8 (GND), U1.1 (GND), U1.34 (GND), U1.47 (GND), U1.64 (GND), U2.8 (GND), U2.15 (~OE), U3.8 (GND), U3.15 (~OE), U4.8 (GND), U4.15 (~OE), U5.8 (GND), U5.15 (~OE), U6.8 (GND), U6.15 (~OE), U7.8 (GND), U7.15 (~OE), U8.8 (GND), U8.15 (~OE), U9.8 (GND), U9.15 (~OE), U10.6 (GND), U11.6 (GND)
LED: J3.L4 (LEDG_A), U1.61 (LED)
unnamed: C11.2, J3.R4 (TCT)
unnamed: C12.2, J3.R5 (RCT)
R+: J3.R3 (RD+), U1.60 (R+)
R-: J3.R6 (RD-), U1.65 (R-)
T+: J3.R1 (TD+), U1.63 (T+)
T-: J3.R2 (TD-), U1.62 (T-)
areg_mem0: J1.22, U6.3 (1B2)
areg_mem1: J1.4, U6.6 (2B2)
areg_mem2: J1.23, U6.10 (3B2)
areg_mem3: J1.5, U6.13 (4B2)
areg_mem4: J1.24, U7.3 (1B2)
areg_mem5: J1.6, U7.6 (2B2)
areg_mem6: J1.25, U7.10 (3B2)
areg_mem7: J1.7, U7.13 (4B2)
areg_mem8: J1.26, U8.3 (1B2)
areg_mem9: J1.8, U8.6 (2B2)
areg_mem10: J1.27, U8.10 (3B2)
areg_mem11: J1.9, U8.13 (4B2)
areg_mem12: J1.28, U9.3 (1B2)
areg_mem13: J1.10, U9.6 (2B2)
areg_mem14: J1.29, U9.10 (3B2)
areg_mem15: J1.11, U9.13 (4B2)
clk_a: J2.17, U10.2 (Q1)
clk_a_pre: U1.21 (29_TX7), U10.1 (CLK)
clk_b: J2.36, U11.2 (Q1)
clk_b_pre: U1.22 (30_CRX3), U11.1 (CLK)
dreg0: J2.9, U2.3 (1B2)
dreg1: J2.28, U2.6 (2B2)
dreg2: J2.10, U2.10 (3B2)
dreg3: J2.29, U2.13 (4B2)
dreg4: J2.11, U3.3 (1B2)
dreg5: J2.30, U3.6 (2B2)
dreg6: J2.12, U3.10 (3B2)
dreg7: J2.31, U3.13 (4B2)
dreg8: J2.13, U4.3 (1B2)
dreg9: J2.32, U4.6 (2B2)
dreg10: J2.14, U4.10 (3B2)
dreg11: J2.33, U4.13 (4B2)
dreg12: J2.15, U5.3 (1B2)
dreg13: J2.34, U5.6 (2B2)
dreg14: J2.16, U5.10 (3B2)
dreg15: J2.35, U5.13 (4B2)
inst_0: J1.30, U2.2 (1B1)
inst_1: J1.12, U2.5 (2B1)
inst_2: J1.31, U2.11 (3B1)
inst_3: J1.13, U2.14 (4B1)
inst_4: J1.32, U3.2 (1B1)
inst_5: J1.14, U3.5 (2B1)
inst_6: J1.33, U3.11 (3B1)
inst_7: J1.15, U3.14 (4B1)
inst_8: J1.34, U4.2 (1B1)
inst_9: J1.16, U4.5 (2B1)
inst_10: J1.35, U4.11 (3B1)
inst_11: J1.17, U4.14 (4B1)
inst_12: J1.36, U5.2 (1B1)
inst_13: J1.18, U5.5 (2B1)
inst_14: J1.37, U5.11 (3B1)
inst_15: J1.19, U5.14 (4B1)
inst_dreg0: U1.2 (0_RX1_CRX2_CS1), U2.4 (1A)
inst_dreg1: U1.3 (1_TX1_CTX2_MISO1), U2.7 (2A)
inst_dreg2: U1.4 (2_OUT2), U2.9 (3A)
inst_dreg3: U1.5 (3_LRCLK2), U2.12 (4A)
inst_dreg4: U1.6 (4_BCLK2), U3.4 (1A)
inst_dreg5: U1.7 (5_IN2), U3.7 (2A)
inst_dreg6: U1.8 (6_OUT1D), U3.9 (3A)
inst_dreg7: U1.9 (7_RX2_OUT1A), U3.12 (4A)
inst_dreg8: U1.10 (8_TX2_IN1), U4.4 (1A)
inst_dreg9: U1.11 (9_OUT1C), U4.7 (2A)
inst_dreg10: U1.12 (10_CS_MQSR), U4.9 (3A)
inst_dreg11: U1.13 (11_MOSI_CTX1), U4.12 (4A)
inst_dreg12: U1.14 (12_MISO_MQSL), U5.4 (1A)
inst_dreg13: U1.16 (24_A10_TX6_SCL2), U5.7 (2A)
inst_dreg14: U1.17 (25_A11_RX6_SDA2), U5.9 (3A)
inst_dreg15: U1.20 (28_RX7), U5.12 (4A)
pc0: J2.20, U6.2 (1B1)
pc1: J2.2, U6.5 (2B1)
pc2: J2.21, U6.11 (3B1)
pc3: J2.3, U6.14 (4B1)
pc4: J2.22, U7.2 (1B1)
pc5: J2.4, U7.5 (2B1)
pc6: J2.23, U7.11 (3B1)
pc7: J2.5, U7.14 (4B1)
pc8: J2.24, U8.2 (1B1)
pc9: J2.6, U8.5 (2B1)
pc10: J2.25, U8.11 (3B1)
pc11: J2.7, U8.14 (4B1)
pc12: J2.26, U9.2 (1B1)
pc13: J2.8, U9.5 (2B1)
pc14: J2.27, U9.11 (3B1)
pc_aregmem0: U1.41 (19_A5_SCL0), U6.4 (1A)
pc_aregmem1: U1.40 (18_A4_SDA0), U6.7 (2A)
pc_aregmem2: U1.36 (14_A0_TX3_SPDIF_OUT), U6.9 (3A)
pc_aregmem3: U1.37 (15_A1_RX3_SPDIF_IN), U6.12 (4A)
pc_aregmem4: U1.32 (40_A16_CS1), U7.4 (1A)
pc_aregmem5: U1.33 (41_A1_MIS01), U7.7 (2A)
pc_aregmem6: U1.39 (17_A3_TX4_SDA1), U7.9 (3A)
pc_aregmem7: U1.38 (16_A2_RX4_SCL1), U7.12 (4A)
pc_aregmem8: U1.44 (22_A8_CTX1), U8.4 (1A)
pc_aregmem9: U1.45 (23_A9_CRX1_MCLK1), U8.7 (2A)
pc_aregmem10: U1.42 (20_A6_TX5_LRCLK1), U8.9 (3A)
pc_aregmem11: U1.43 (21_A7_RX5_BCLK1), U8.12 (4A)
pc_aregmem12: U1.30 (38_DAT3_RX5), U9.4 (1A)
pc_aregmem13: U1.31 (39_DAT2_TX5), U9.7 (2A)
pc_aregmem14: U1.18 (26_A12_MOSI1), U9.9 (3A)
pc_aregmem15: U1.19 (27_A13_SCK1), U9.12 (4A)
reset: J1.3, U1.27 (35_DAT0_MOSI2)
rom_oe: J1.2, U1.24 (32_OUT1B)
rom_we: J2.1, U1.23 (31_CTX3)
sel_inst_dreg: U1.29 (37_CMD_SCK2), U2.1 (Sel), U3.1 (Sel), U4.1 (Sel), U5.1 (Sel)
sel_pc_aregmem: U1.28 (36_CLK_CS2), U6.1 (Sel), U7.1 (Sel), U8.1 (Sel), U9.1 (Sel)

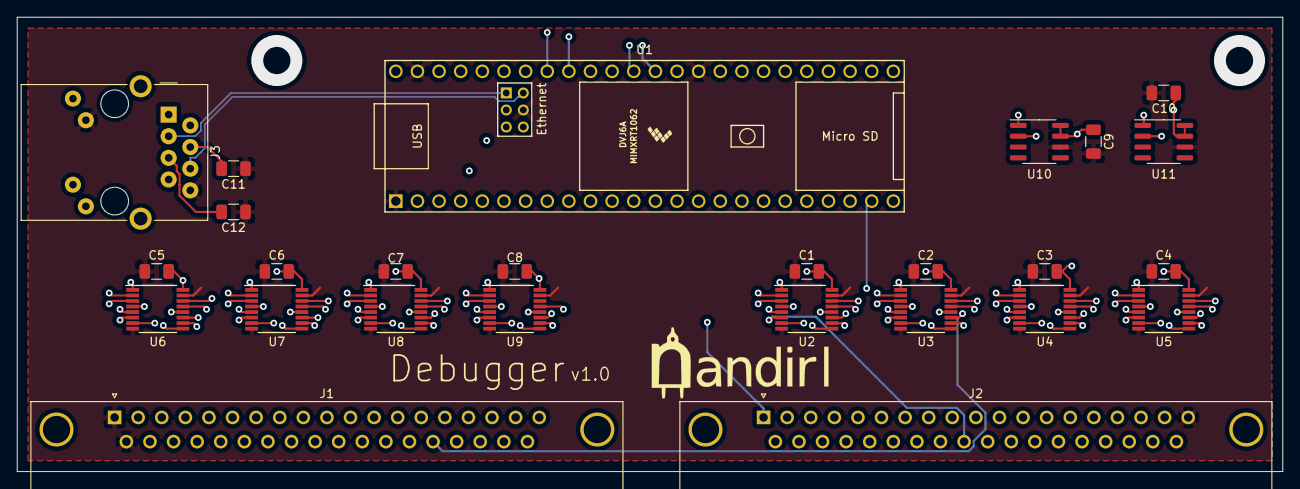
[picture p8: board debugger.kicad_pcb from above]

Board: 4 copper layers, 148.6 x 53.3 mm, 26 parts (0 on the bottom side), 113 nets.

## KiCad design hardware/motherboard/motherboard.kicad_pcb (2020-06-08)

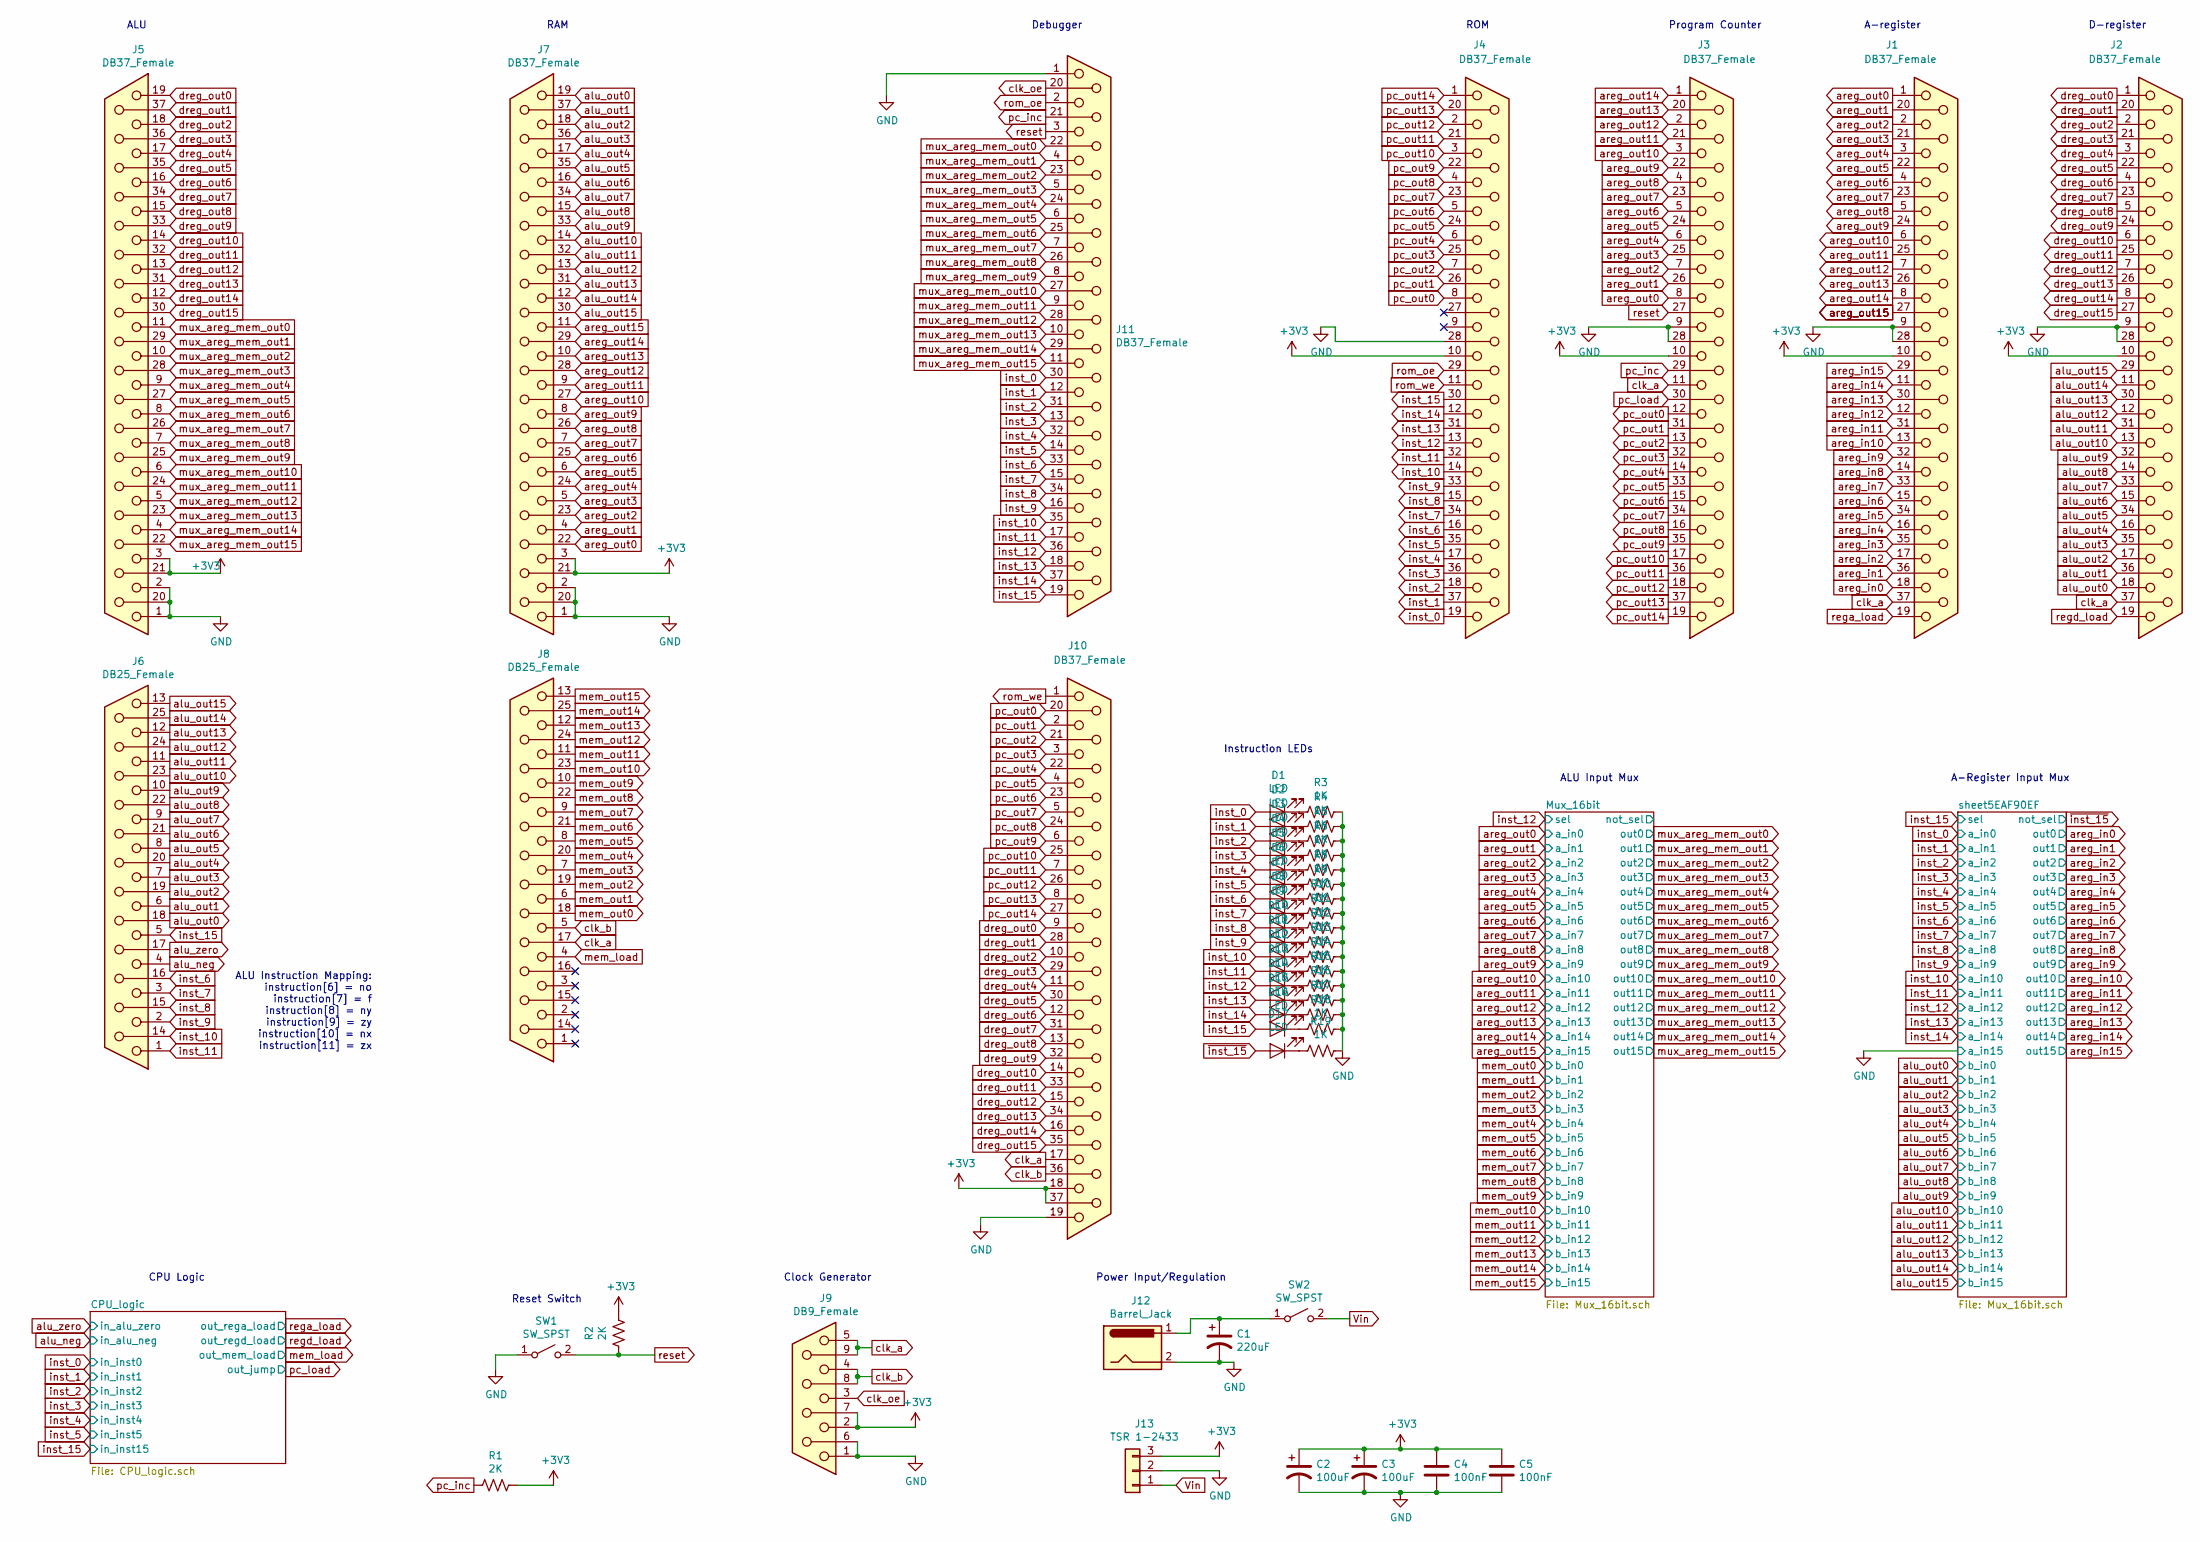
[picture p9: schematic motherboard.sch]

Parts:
C1: 220uF; CP_Radial_D10.0mm_P5.00mm; Digikey PN P5183-ND
C2, C3: 100uF; CP_Radial_D8.0mm_P2.50mm; Digikey PN P15797CT-ND
C4, C5: 100nF; C_Disc_D6.0mm_W2.5mm_P5.00mm; Digikey PN BC5229CT-ND
D1, D2, D3, D4, D5, D6, D7, D8, D9, D10, D11, D12, D13, D14, D15, D16, D17: LED; LED_1206_3216Metric; Digikey PN 516-1436-1-ND
J1, J2, J3, J4, J5, J7, J10, J11: DB37_Female; DSUB-37_Female_Horizontal_P2.77x2.84mm_EdgePinOffset7.70mm_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; Digikey PN AE10941-ND
J6, J8: DB25_Female; DSUB-25_Female_Horizontal_P2.77x2.84mm_EdgePinOffset7.70mm_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; Digikey PN AE10935-ND
J9: DB9_Female; DSUB-9_Female_Horizontal_P2.77x2.84mm_EdgePinOffset7.70mm_H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; Digikey PN AE10921-ND
J12: Barrel_Jack; BarrelJack_CUI_PJ-063AH_Horizontal; Digikey PN CP-063AH-ND
J13: TSR 1-2433; PinHeader_1x03_P2.54mm_Vertical; Digikey PN 1951-2430-ND
R1, R2: 2K; R_1206_3216Metric; Digikey PN P2.0KECT-ND
R3, R4, R5, R6, R7, R8, R9, R10, R11, R12, R13, R14, R15, R16, R17, R18, R19: 1K; R_1206_3216Metric; Digikey PN P1.0KECT-ND
SW1: SW_SPST; SW_SPST_B3S-1000; Digikey PN SW415-ND
SW2: SW_SPST; SPST Toggle Switch; Digikey PN EG4914-ND

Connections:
+3V3: C2.1, C3.1, C4.1, C5.1, J1.10, J2.10, J3.10, J4.10, J5.3, J5.21, J7.3, J7.21, J9.2, J9.7, J10.18, J10.37, J13.3, R1.1, R2.1; also elsewhere on the board
GND: C1.2, C2.2, C3.2, C4.2, C5.2, J1.9, J1.28, J2.9, J2.28, J3.9, J3.28, J4.28, J5.1, J5.2, J5.20, J7.1, J7.2, J7.20, J9.1, J9.6, J10.19, J11.1, J12.2, J13.2, R3.1, R4.1, R5.1, R6.1, R7.1, R8.1, R9.1, R10.1, R11.1, R12.1, R13.1, R14.1, R15.1, R16.1, R17.1, R18.1, R19.1, SW1.1 (A); also elsewhere on the board
unnamed: C1.1, J12.1, SW2.1 (A)
unnamed: D1.1 (K), R3.2
unnamed: D2.1 (K), R4.2
unnamed: D3.1 (K), R5.2
unnamed: D4.1 (K), R6.2
unnamed: D5.1 (K), R7.2
unnamed: D6.1 (K), R8.2
unnamed: D7.1 (K), R9.2
unnamed: D8.1 (K), R10.2
unnamed: D9.1 (K), R11.2
unnamed: D10.1 (K), R12.2
unnamed: D11.1 (K), R13.2
unnamed: D12.1 (K), R14.2
unnamed: D13.1 (K), R15.2
unnamed: D14.1 (K), R16.2
unnamed: D15.1 (K), R17.2
unnamed: D16.1 (K), R18.2
unnamed: D17.1 (K), R19.2
Vin: J13.1, SW2.2 (B)
alu_neg: J6.4; also elsewhere on the board
alu_out0: J2.18, J6.18, J7.19; also elsewhere on the board
alu_out1: J2.36, J6.6, J7.37; also elsewhere on the board
alu_out2: J2.17, J6.19, J7.18; also elsewhere on the board
alu_out3: J2.35, J6.7, J7.36; also elsewhere on the board
alu_out4: J2.16, J6.20, J7.17; also elsewhere on the board
alu_out5: J2.34, J6.8, J7.35; also elsewhere on the board
alu_out6: J2.15, J6.21, J7.16; also elsewhere on the board
alu_out7: J2.33, J6.9, J7.34; also elsewhere on the board
alu_out8: J2.14, J6.22, J7.15; also elsewhere on the board
alu_out9: J2.32, J6.10, J7.33; also elsewhere on the board
alu_out10: J2.13, J6.23, J7.14; also elsewhere on the board
alu_out11: J2.31, J6.11, J7.32; also elsewhere on the board
alu_out12: J2.12, J6.24, J7.13; also elsewhere on the board
alu_out13: J2.30, J6.12, J7.31; also elsewhere on the board
alu_out14: J2.11, J6.25, J7.12; also elsewhere on the board
alu_out15: J2.29, J6.13, J7.30; also elsewhere on the board
alu_zero: J6.17; also elsewhere on the board
areg_in0: J1.18; also elsewhere on the board
areg_in1: J1.36; also elsewhere on the board
areg_in2: J1.17; also elsewhere on the board
areg_in3: J1.35; also elsewhere on the board
areg_in4: J1.16; also elsewhere on the board
areg_in5: J1.34; also elsewhere on the board
areg_in6: J1.15; also elsewhere on the board
areg_in7: J1.33; also elsewhere on the board
areg_in8: J1.14; also elsewhere on the board
areg_in9: J1.32; also elsewhere on the board
areg_in10: J1.13; also elsewhere on the board
areg_in11: J1.31; also elsewhere on the board
areg_in12: J1.12; also elsewhere on the board
areg_in13: J1.30; also elsewhere on the board
areg_in14: J1.11; also elsewhere on the board
areg_in15: J1.29; also elsewhere on the board
areg_out0: J1.1, J3.8, J7.22; also elsewhere on the board
areg_out1: J1.20, J3.26, J7.4; also elsewhere on the board
areg_out2: J1.2, J3.7, J7.23; also elsewhere on the board
areg_out3: J1.21, J3.25, J7.5; also elsewhere on the board
areg_out4: J1.3, J3.6, J7.24; also elsewhere on the board
areg_out5: J1.22, J3.24, J7.6; also elsewhere on the board
areg_out6: J1.4, J3.5, J7.25; also elsewhere on the board
areg_out7: J1.23, J3.23, J7.7; also elsewhere on the board
areg_out8: J1.5, J3.4, J7.26; also elsewhere on the board
areg_out9: J1.24, J3.22, J7.8; also elsewhere on the board
areg_out10: J1.6, J3.3, J7.27; also elsewhere on the board
areg_out11: J1.25, J3.21, J7.9; also elsewhere on the board
areg_out12: J1.7, J3.2, J7.28; also elsewhere on the board
areg_out13: J1.26, J3.20, J7.10; also elsewhere on the board
areg_out14: J1.8, J3.1, J7.29; also elsewhere on the board
areg_out15: J1.27, J7.11; also elsewhere on the board
clk_a: J1.37, J2.37, J3.11, J8.17, J9.5, J9.9, J10.17
clk_b: J8.5, J9.4, J9.8, J10.36
clk_oe: J9.3, J11.20
dreg_out0: J2.1, J5.19, J10.9
dreg_out1: J2.20, J5.37, J10.28
dreg_out2: J2.2, J5.18, J10.10
dreg_out3: J2.21, J5.36, J10.29
dreg_out4: J2.3, J5.17, J10.11
dreg_out5: J2.22, J5.35, J10.30
dreg_out6: J2.4, J5.16, J10.12
dreg_out7: J2.23, J5.34, J10.31
dreg_out8: J2.5, J5.15, J10.13
dreg_out9: J2.24, J5.33, J10.32
dreg_out10: J2.6, J5.14, J10.14
dreg_out11: J2.25, J5.32, J10.33
dreg_out12: J2.7, J5.13, J10.15
dreg_out13: J2.26, J5.31, J10.34
dreg_out14: J2.8, J5.12, J10.16
dreg_out15: J2.27, J5.30, J10.35
inst_0: D1.2 (A), J4.19, J11.30; also elsewhere on the board
inst_1: D2.2 (A), J4.37, J11.12; also elsewhere on the board
inst_2: D3.2 (A), J4.18, J11.31; also elsewhere on the board
inst_3: D4.2 (A), J4.36, J11.13; also elsewhere on the board
inst_4: D5.2 (A), J4.17, J11.32; also elsewhere on the board
inst_5: D6.2 (A), J4.35, J11.14; also elsewhere on the board
inst_6: D7.2 (A), J4.16, J6.16, J11.33; also elsewhere on the board
inst_7: D8.2 (A), J4.34, J6.3, J11.15; also elsewhere on the board
inst_8: D9.2 (A), J4.15, J6.15, J11.34; also elsewhere on the board
inst_9: D10.2 (A), J4.33, J6.2, J11.16; also elsewhere on the board
inst_10: D11.2 (A), J4.14, J6.14, J11.35; also elsewhere on the board
inst_11: D12.2 (A), J4.32, J6.1, J11.17; also elsewhere on the board
inst_12: D13.2 (A), J4.13, J11.36; also elsewhere on the board
inst_13: D14.2 (A), J4.31, J11.18; also elsewhere on the board
inst_14: D15.2 (A), J4.12, J11.37; also elsewhere on the board
inst_15: D16.2 (A), J4.30, J6.5, J11.19; also elsewhere on the board
mem_load: J8.4; also elsewhere on the board
mem_out0: J8.18; also elsewhere on the board
mem_out1: J8.6; also elsewhere on the board
mem_out2: J8.19; also elsewhere on the board
mem_out3: J8.7; also elsewhere on the board
mem_out4: J8.20; also elsewhere on the board
mem_out5: J8.8; also elsewhere on the board
mem_out6: J8.21; also elsewhere on the board
mem_out7: J8.9; also elsewhere on the board
mem_out8: J8.22; also elsewhere on the board
mem_out9: J8.10; also elsewhere on the board
mem_out10: J8.23; also elsewhere on the board
mem_out11: J8.11; also elsewhere on the board
mem_out12: J8.24; also elsewhere on the board
mem_out13: J8.12; also elsewhere on the board
mem_out14: J8.25; also elsewhere on the board
mem_out15: J8.13; also elsewhere on the board
mux_areg_mem_out0: J5.11, J11.22; also elsewhere on the board
mux_areg_mem_out1: J5.29, J11.4; also elsewhere on the board
mux_areg_mem_out2: J5.10, J11.23; also elsewhere on the board
mux_areg_mem_out3: J5.28, J11.5; also elsewhere on the board
mux_areg_mem_out4: J5.9, J11.24; also elsewhere on the board
mux_areg_mem_out5: J5.27, J11.6; also elsewhere on the board
mux_areg_mem_out6: J5.8, J11.25; also elsewhere on the board
mux_areg_mem_out7: J5.26, J11.7; also elsewhere on the board
mux_areg_mem_out8: J5.7, J11.26; also elsewhere on the board
mux_areg_mem_out9: J5.25, J11.8; also elsewhere on the board
mux_areg_mem_out10: J5.6, J11.27; also elsewhere on the board
mux_areg_mem_out11: J5.24, J11.9; also elsewhere on the board
mux_areg_mem_out12: J5.5, J11.28; also elsewhere on the board
mux_areg_mem_out13: J5.23, J11.10; also elsewhere on the board
mux_areg_mem_out14: J5.4, J11.29; also elsewhere on the board
mux_areg_mem_out15: J5.22, J11.11; also elsewhere on the board
pc_inc: J3.29, J11.21, R1.2
pc_load: J3.30; also elsewhere on the board
pc_out0: J3.12, J4.8, J10.20
pc_out1: J3.31, J4.26, J10.2
pc_out2: J3.13, J4.7, J10.21
pc_out3: J3.32, J4.25, J10.3
pc_out4: J3.14, J4.6, J10.22
pc_out5: J3.33, J4.24, J10.4
pc_out6: J3.15, J4.5, J10.23
pc_out7: J3.34, J4.23, J10.5
pc_out8: J3.16, J4.4, J10.24
pc_out9: J3.35, J4.22, J10.6
pc_out10: J3.17, J4.3, J10.25
pc_out11: J3.36, J4.21, J10.7
pc_out12: J3.18, J4.2, J10.26
pc_out13: J3.37, J4.20, J10.8
pc_out14: J3.19, J4.1, J10.27
rega_load: J1.19; also elsewhere on the board
regd_load: J2.19; also elsewhere on the board
reset: J3.27, J11.3, R2.2, SW1.2 (B)
rom_addr15: J4.27
rom_addr16: J4.9
rom_oe: J4.29, J11.2
rom_we: J4.11, J10.1
~inst_15: D17.2 (A); also elsewhere on the board

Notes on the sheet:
D-register
A-register
Program Counter
ROM
ALU
ALU Instruction Mapping: instruction[6] = no instruction[7] = f instruction[8] = ny instruction[9] = zy instruction[10] = nx instruction[11] = zx
RAM
ALU Input Mux
A-Register Input Mux
Clock Generator
CPU Logic
Debugger
Power Input/Regulation
Reset Switch
Instruction LEDs

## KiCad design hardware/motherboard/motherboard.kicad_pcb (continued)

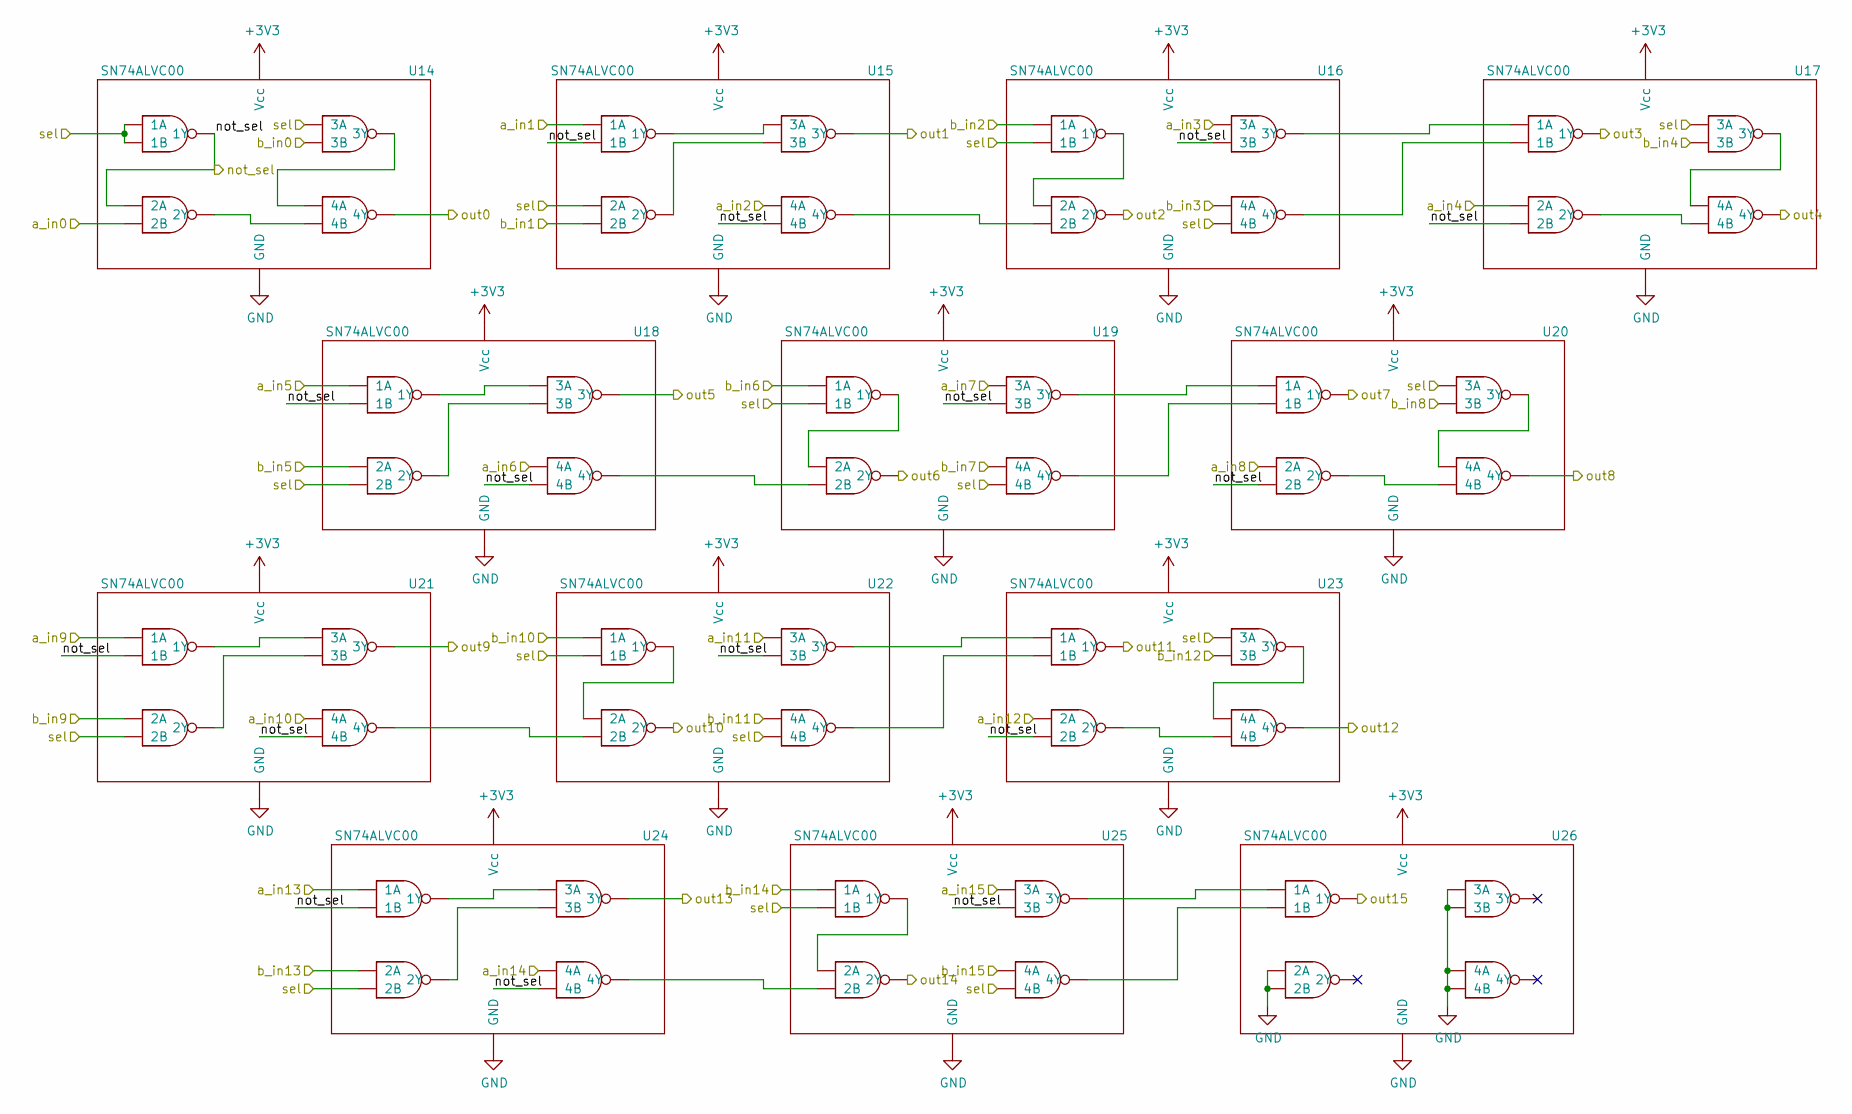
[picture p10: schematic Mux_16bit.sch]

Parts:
U1, U2, U3, U4, U5, U6, U7, U8, U9, U10, U11, U12, U13: SN74ALVC00; TSSOP-14_4.4x5mm_P0.65mm; Digikey PN 296-5104-1-ND

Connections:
+3V3: U1.14 (Vcc), U2.14 (Vcc), U3.14 (Vcc), U4.14 (Vcc), U5.14 (Vcc), U6.14 (Vcc), U7.14 (Vcc), U8.14 (Vcc), U9.14 (Vcc), U10.14 (Vcc), U11.14 (Vcc), U12.14 (Vcc), U13.14 (Vcc); also elsewhere on the board
/Mux_16bit/not_sel: U1.3 (1Y), U1.4 (2A), U2.2 (1B), U2.13 (4B), U3.10 (3B), U4.5 (2B), U5.2 (1B), U5.13 (4B), U6.10 (3B), U7.5 (2B), U8.2 (1B), U8.13 (4B), U9.10 (3B), U10.5 (2B), U11.2 (1B), U11.13 (4B), U12.10 (3B)
GND: U1.7 (GND), U2.7 (GND), U3.7 (GND), U4.7 (GND), U5.7 (GND), U6.7 (GND), U7.7 (GND), U8.7 (GND), U9.7 (GND), U10.7 (GND), U11.7 (GND), U12.7 (GND), U13.4 (2A), U13.5 (2B), U13.7 (GND), U13.9 (3A), U13.10 (3B), U13.12 (4A), U13.13 (4B); also elsewhere on the board
unnamed: U1.8 (3Y), U1.12 (4A)
unnamed: U1.6 (2Y), U1.13 (4B)
unnamed: U2.3 (1Y), U2.9 (3A)
unnamed: U2.6 (2Y), U2.10 (3B)
unnamed: U2.11 (4Y), U3.5 (2B)
unnamed: U3.3 (1Y), U3.4 (2A)
unnamed: U3.8 (3Y), U4.1 (1A)
unnamed: U3.11 (4Y), U4.2 (1B)
unnamed: U4.8 (3Y), U4.12 (4A)
unnamed: U4.6 (2Y), U4.13 (4B)
unnamed: U5.3 (1Y), U5.9 (3A)
unnamed: U5.6 (2Y), U5.10 (3B)
unnamed: U5.11 (4Y), U6.5 (2B)
unnamed: U6.3 (1Y), U6.4 (2A)
unnamed: U6.8 (3Y), U7.1 (1A)
unnamed: U6.11 (4Y), U7.2 (1B)
unnamed: U7.8 (3Y), U7.12 (4A)
unnamed: U7.6 (2Y), U7.13 (4B)
unnamed: U8.3 (1Y), U8.9 (3A)
unnamed: U8.6 (2Y), U8.10 (3B)
unnamed: U8.11 (4Y), U9.5 (2B)
unnamed: U9.3 (1Y), U9.4 (2A)
unnamed: U9.8 (3Y), U10.1 (1A)
unnamed: U9.11 (4Y), U10.2 (1B)
unnamed: U10.8 (3Y), U10.12 (4A)
unnamed: U10.6 (2Y), U10.13 (4B)
unnamed: U11.3 (1Y), U11.9 (3A)
unnamed: U11.6 (2Y), U11.10 (3B)
unnamed: U11.11 (4Y), U12.5 (2B)
unnamed: U12.3 (1Y), U12.4 (2A)
unnamed: U12.8 (3Y), U13.1 (1A)
unnamed: U12.11 (4Y), U13.2 (1B)
areg_out0: U1.5 (2B); also elsewhere on the board
areg_out1: U2.1 (1A); also elsewhere on the board
areg_out2: U2.12 (4A); also elsewhere on the board
areg_out3: U3.9 (3A); also elsewhere on the board
areg_out4: U4.4 (2A); also elsewhere on the board
areg_out5: U5.1 (1A); also elsewhere on the board
areg_out6: U5.12 (4A); also elsewhere on the board
areg_out7: U6.9 (3A); also elsewhere on the board
areg_out8: U7.4 (2A); also elsewhere on the board
areg_out9: U8.1 (1A); also elsewhere on the board
areg_out10: U8.12 (4A); also elsewhere on the board
areg_out11: U9.9 (3A); also elsewhere on the board
areg_out12: U10.4 (2A); also elsewhere on the board
areg_out13: U11.1 (1A); also elsewhere on the board
areg_out14: U11.12 (4A); also elsewhere on the board
areg_out15: U12.9 (3A); also elsewhere on the board
inst_12: U1.1 (1A), U1.2 (1B), U1.9 (3A), U2.4 (2A), U3.2 (1B), U3.13 (4B), U4.9 (3A), U5.5 (2B), U6.2 (1B), U6.13 (4B), U7.9 (3A), U8.5 (2B), U9.2 (1B), U9.13 (4B), U10.9 (3A), U11.5 (2B), U12.2 (1B), U12.13 (4B); also elsewhere on the board
mem_out0: U1.10 (3B); also elsewhere on the board
mem_out1: U2.5 (2B); also elsewhere on the board
mem_out2: U3.1 (1A); also elsewhere on the board
mem_out3: U3.12 (4A); also elsewhere on the board
mem_out4: U4.10 (3B); also elsewhere on the board
mem_out5: U5.4 (2A); also elsewhere on the board
mem_out6: U6.1 (1A); also elsewhere on the board
mem_out7: U6.12 (4A); also elsewhere on the board
mem_out8: U7.10 (3B); also elsewhere on the board
mem_out9: U8.4 (2A); also elsewhere on the board
mem_out10: U9.1 (1A); also elsewhere on the board
mem_out11: U9.12 (4A); also elsewhere on the board
mem_out12: U10.10 (3B); also elsewhere on the board
mem_out13: U11.4 (2A); also elsewhere on the board
mem_out14: U12.1 (1A); also elsewhere on the board
mem_out15: U12.12 (4A); also elsewhere on the board
mux_areg_mem_out0: U1.11 (4Y); also elsewhere on the board
mux_areg_mem_out1: U2.8 (3Y); also elsewhere on the board
mux_areg_mem_out2: U3.6 (2Y); also elsewhere on the board
mux_areg_mem_out3: U4.3 (1Y); also elsewhere on the board
mux_areg_mem_out4: U4.11 (4Y); also elsewhere on the board
mux_areg_mem_out5: U5.8 (3Y); also elsewhere on the board
mux_areg_mem_out6: U6.6 (2Y); also elsewhere on the board
mux_areg_mem_out7: U7.3 (1Y); also elsewhere on the board
mux_areg_mem_out8: U7.11 (4Y); also elsewhere on the board
mux_areg_mem_out9: U8.8 (3Y); also elsewhere on the board
mux_areg_mem_out10: U9.6 (2Y); also elsewhere on the board
mux_areg_mem_out11: U10.3 (1Y); also elsewhere on the board
mux_areg_mem_out12: U10.11 (4Y); also elsewhere on the board
mux_areg_mem_out13: U11.8 (3Y); also elsewhere on the board
mux_areg_mem_out14: U12.6 (2Y); also elsewhere on the board
mux_areg_mem_out15: U13.3 (1Y); also elsewhere on the board

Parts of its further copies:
U14, U15, U16, U17, U18, U19, U20, U21, U22, U23, U24, U25, U26: SN74ALVC00; TSSOP-14_4.4x5mm_P0.65mm; Digikey PN 296-5104-1-ND

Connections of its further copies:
+3V3: U14.14 (Vcc), U15.14 (Vcc), U16.14 (Vcc), U17.14 (Vcc), U18.14 (Vcc), U19.14 (Vcc), U20.14 (Vcc), U21.14 (Vcc), U22.14 (Vcc), U23.14 (Vcc), U24.14 (Vcc), U25.14 (Vcc), U26.14 (Vcc); also elsewhere on the board
GND: U14.7 (GND), U15.7 (GND), U16.7 (GND), U17.7 (GND), U18.7 (GND), U19.7 (GND), U20.7 (GND), U21.7 (GND), U22.7 (GND), U23.7 (GND), U24.7 (GND), U25.7 (GND), U25.9 (3A), U26.4 (2A), U26.5 (2B), U26.7 (GND), U26.9 (3A), U26.10 (3B), U26.12 (4A), U26.13 (4B); also elsewhere on the board
unnamed: U14.8 (3Y), U14.12 (4A)
unnamed: U14.6 (2Y), U14.13 (4B)
unnamed: U15.3 (1Y), U15.9 (3A)
unnamed: U15.6 (2Y), U15.10 (3B)
unnamed: U15.11 (4Y), U16.5 (2B)
unnamed: U16.3 (1Y), U16.4 (2A)
unnamed: U16.8 (3Y), U17.1 (1A)
unnamed: U16.11 (4Y), U17.2 (1B)
unnamed: U17.8 (3Y), U17.12 (4A)
unnamed: U17.6 (2Y), U17.13 (4B)
unnamed: U18.3 (1Y), U18.9 (3A)
unnamed: U18.6 (2Y), U18.10 (3B)
unnamed: U18.11 (4Y), U19.5 (2B)
unnamed: U19.3 (1Y), U19.4 (2A)
unnamed: U19.8 (3Y), U20.1 (1A)
unnamed: U19.11 (4Y), U20.2 (1B)
unnamed: U20.8 (3Y), U20.12 (4A)
unnamed: U20.6 (2Y), U20.13 (4B)
unnamed: U21.3 (1Y), U21.9 (3A)
unnamed: U21.6 (2Y), U21.10 (3B)
unnamed: U21.11 (4Y), U22.5 (2B)
unnamed: U22.3 (1Y), U22.4 (2A)
unnamed: U22.8 (3Y), U23.1 (1A)
unnamed: U22.11 (4Y), U23.2 (1B)
unnamed: U23.8 (3Y), U23.12 (4A)
unnamed: U23.6 (2Y), U23.13 (4B)
unnamed: U24.3 (1Y), U24.9 (3A)
unnamed: U24.6 (2Y), U24.10 (3B)
unnamed: U24.11 (4Y), U25.5 (2B)
unnamed: U25.3 (1Y), U25.4 (2A)
unnamed: U25.8 (3Y), U26.1 (1A)
unnamed: U25.11 (4Y), U26.2 (1B)
alu_out0: U14.10 (3B); also elsewhere on the board
alu_out1: U15.5 (2B); also elsewhere on the board
alu_out2: U16.1 (1A); also elsewhere on the board
alu_out3: U16.12 (4A); also elsewhere on the board
alu_out4: U17.10 (3B); also elsewhere on the board
alu_out5: U18.4 (2A); also elsewhere on the board
alu_out6: U19.1 (1A); also elsewhere on the board
alu_out7: U19.12 (4A); also elsewhere on the board
alu_out8: U20.10 (3B); also elsewhere on the board
alu_out9: U21.4 (2A); also elsewhere on the board
alu_out10: U22.1 (1A); also elsewhere on the board
alu_out11: U22.12 (4A); also elsewhere on the board
alu_out12: U23.10 (3B); also elsewhere on the board
alu_out13: U24.4 (2A); also elsewhere on the board
alu_out14: U25.1 (1A); also elsewhere on the board
alu_out15: U25.12 (4A); also elsewhere on the board
areg_in0: U14.11 (4Y); also elsewhere on the board
areg_in1: U15.8 (3Y); also elsewhere on the board
areg_in2: U16.6 (2Y); also elsewhere on the board
areg_in3: U17.3 (1Y); also elsewhere on the board
areg_in4: U17.11 (4Y); also elsewhere on the board
areg_in5: U18.8 (3Y); also elsewhere on the board
areg_in6: U19.6 (2Y); also elsewhere on the board
areg_in7: U20.3 (1Y); also elsewhere on the board
areg_in8: U20.11 (4Y); also elsewhere on the board
areg_in9: U21.8 (3Y); also elsewhere on the board
areg_in10: U22.6 (2Y); also elsewhere on the board
areg_in11: U23.3 (1Y); also elsewhere on the board
areg_in12: U23.11 (4Y); also elsewhere on the board
areg_in13: U24.8 (3Y); also elsewhere on the board
areg_in14: U25.6 (2Y); also elsewhere on the board
areg_in15: U26.3 (1Y); also elsewhere on the board
inst_0: U14.5 (2B); also elsewhere on the board
inst_1: U15.1 (1A); also elsewhere on the board
inst_2: U15.12 (4A); also elsewhere on the board
inst_3: U16.9 (3A); also elsewhere on the board
inst_4: U17.4 (2A); also elsewhere on the board
inst_5: U18.1 (1A); also elsewhere on the board
inst_6: U18.12 (4A); also elsewhere on the board
inst_7: U19.9 (3A); also elsewhere on the board
inst_8: U20.4 (2A); also elsewhere on the board
inst_9: U21.1 (1A); also elsewhere on the board
inst_10: U21.12 (4A); also elsewhere on the board
inst_11: U22.9 (3A); also elsewhere on the board
inst_12: U23.4 (2A); also elsewhere on the board
inst_13: U24.1 (1A); also elsewhere on the board
inst_14: U24.12 (4A); also elsewhere on the board
inst_15: U14.1 (1A), U14.2 (1B), U14.9 (3A), U15.4 (2A), U16.2 (1B), U16.13 (4B), U17.9 (3A), U18.5 (2B), U19.2 (1B), U19.13 (4B), U20.9 (3A), U21.5 (2B), U22.2 (1B), U22.13 (4B), U23.9 (3A), U24.5 (2B), U25.2 (1B), U25.13 (4B); also elsewhere on the board
~inst_15: U14.3 (1Y), U14.4 (2A), U15.2 (1B), U15.13 (4B), U16.10 (3B), U17.5 (2B), U18.2 (1B), U18.13 (4B), U19.10 (3B), U20.5 (2B), U21.2 (1B), U21.13 (4B), U22.10 (3B), U23.5 (2B), U24.2 (1B), U24.13 (4B), U25.10 (3B); also elsewhere on the board

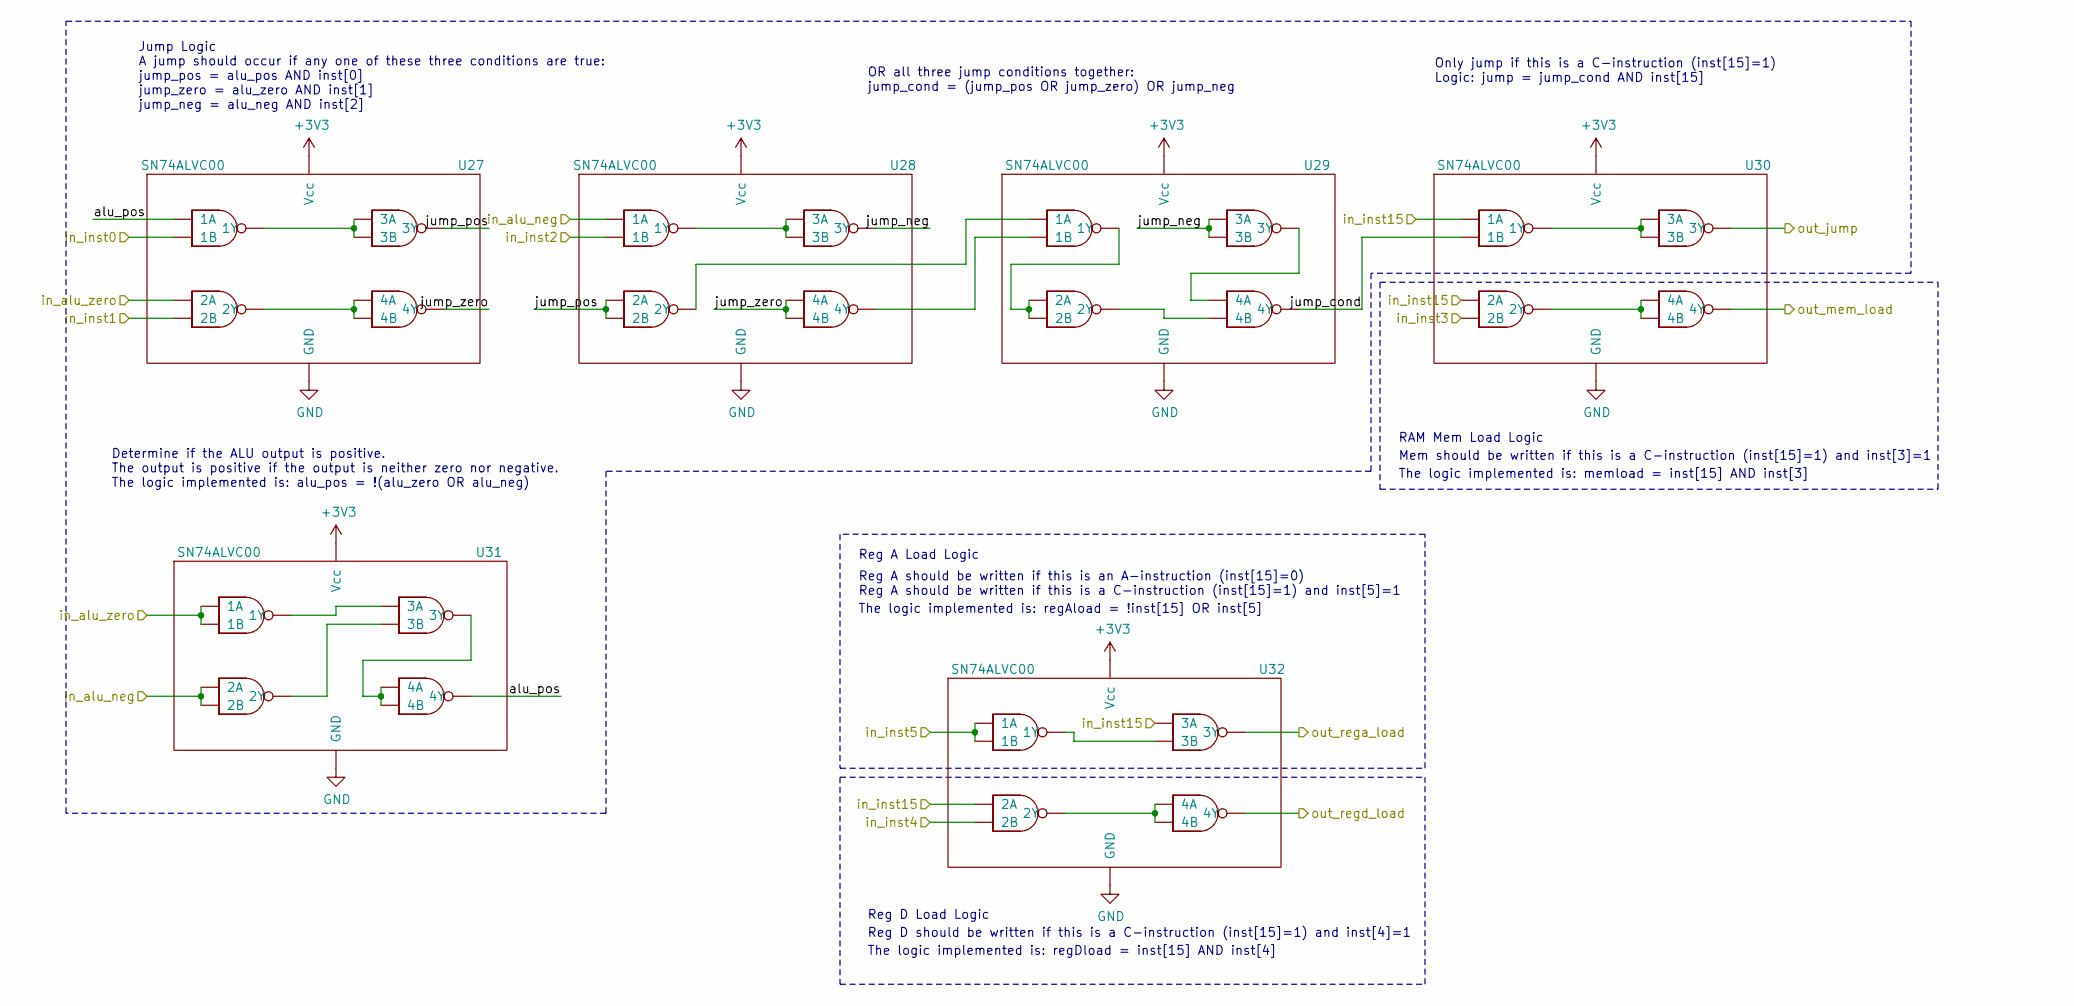
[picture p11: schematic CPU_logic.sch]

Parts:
U27, U28, U29, U30, U31, U32: SN74ALVC00; TSSOP-14_4.4x5mm_P0.65mm; Digikey PN 296-5104-1-ND

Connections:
+3V3: U27.14 (Vcc), U28.14 (Vcc), U29.14 (Vcc), U30.14 (Vcc), U31.14 (Vcc), U32.14 (Vcc); also elsewhere on the board
/CPU_logic/alu_pos: U27.1 (1A), U31.11 (4Y)
/CPU_logic/jump_cond: U29.11 (4Y), U30.2 (1B)
/CPU_logic/jump_neg: U28.8 (3Y), U29.9 (3A), U29.10 (3B)
/CPU_logic/jump_pos: U27.8 (3Y), U28.4 (2A), U28.5 (2B)
/CPU_logic/jump_zero: U27.11 (4Y), U28.12 (4A), U28.13 (4B)
GND: U27.7 (GND), U28.7 (GND), U29.7 (GND), U30.7 (GND), U31.7 (GND), U32.7 (GND); also elsewhere on the board
unnamed: U27.3 (1Y), U27.9 (3A), U27.10 (3B)
unnamed: U27.6 (2Y), U27.12 (4A), U27.13 (4B)
unnamed: U28.6 (2Y), U29.1 (1A)
unnamed: U28.3 (1Y), U28.9 (3A), U28.10 (3B)
unnamed: U28.11 (4Y), U29.2 (1B)
unnamed: U29.3 (1Y), U29.4 (2A), U29.5 (2B)
unnamed: U29.8 (3Y), U29.12 (4A)
unnamed: U29.6 (2Y), U29.13 (4B)
unnamed: U30.3 (1Y), U30.9 (3A), U30.10 (3B)
unnamed: U30.6 (2Y), U30.12 (4A), U30.13 (4B)
unnamed: U31.3 (1Y), U31.9 (3A)
unnamed: U31.6 (2Y), U31.10 (3B)
unnamed: U31.8 (3Y), U31.12 (4A), U31.13 (4B)
unnamed: U32.3 (1Y), U32.10 (3B)
unnamed: U32.6 (2Y), U32.12 (4A), U32.13 (4B)
alu_neg: U28.1 (1A), U31.4 (2A), U31.5 (2B); also elsewhere on the board
alu_zero: U27.4 (2A), U31.1 (1A), U31.2 (1B); also elsewhere on the board
inst_0: U27.2 (1B); also elsewhere on the board
inst_1: U27.5 (2B); also elsewhere on the board
inst_2: U28.2 (1B); also elsewhere on the board
inst_3: U30.5 (2B); also elsewhere on the board
inst_4: U32.5 (2B); also elsewhere on the board
inst_5: U32.1 (1A), U32.2 (1B); also elsewhere on the board
inst_15: U30.1 (1A), U30.4 (2A), U32.4 (2A), U32.9 (3A); also elsewhere on the board
mem_load: U30.11 (4Y); also elsewhere on the board
pc_load: U30.8 (3Y); also elsewhere on the board
rega_load: U32.8 (3Y); also elsewhere on the board
regd_load: U32.11 (4Y); also elsewhere on the board

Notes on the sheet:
Reg A Load Logic
Reg A should be written if this is an A-instruction (inst[15]=0) Reg A should be written if this is a C-instruction (inst[15]=1) and inst[5]=1
The logic implemented is: regAload = !inst[15] OR inst[5]
Reg D Load Logic
The logic implemented is: regDload = inst[15] AND inst[4]
Reg D should be written if this is a C-instruction (inst[15]=1) and inst[4]=1
Determine if the ALU output is positive. The output is positive if the output is neither zero nor negative. The logic implemented is: alu_pos = !(alu_zero OR alu_neg)
Jump Logic A jump should occur if any one of these three conditions are true: jump_pos = alu_pos AND inst[0] jump_zero = alu_zero AND inst[1] jump_neg = alu_neg AND inst[2]
OR all three jump conditions together: jump_cond = (jump_pos OR jump_zero) OR jump_neg
Only jump if this is a C-instruction (inst[15]=1) Logic: jump = jump_cond AND inst[15]
RAM Mem Load Logic
The logic implemented is: memload = inst[15] AND inst[3]
Mem should be written if this is a C-instruction (inst[15]=1) and inst[3]=1

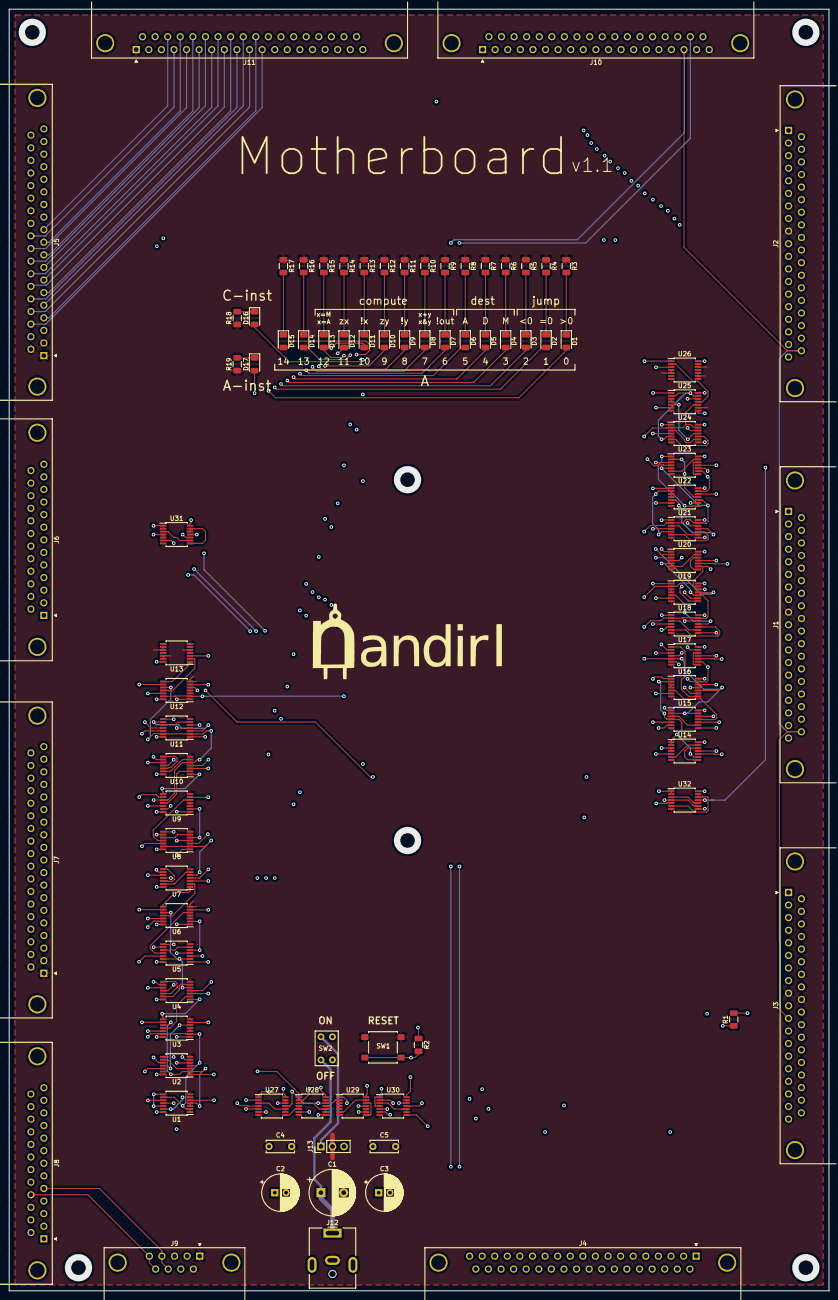
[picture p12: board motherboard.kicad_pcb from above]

Board: 4 copper layers, 180.3 x 281.9 mm, 88 parts (0 on the bottom side), 247 nets.

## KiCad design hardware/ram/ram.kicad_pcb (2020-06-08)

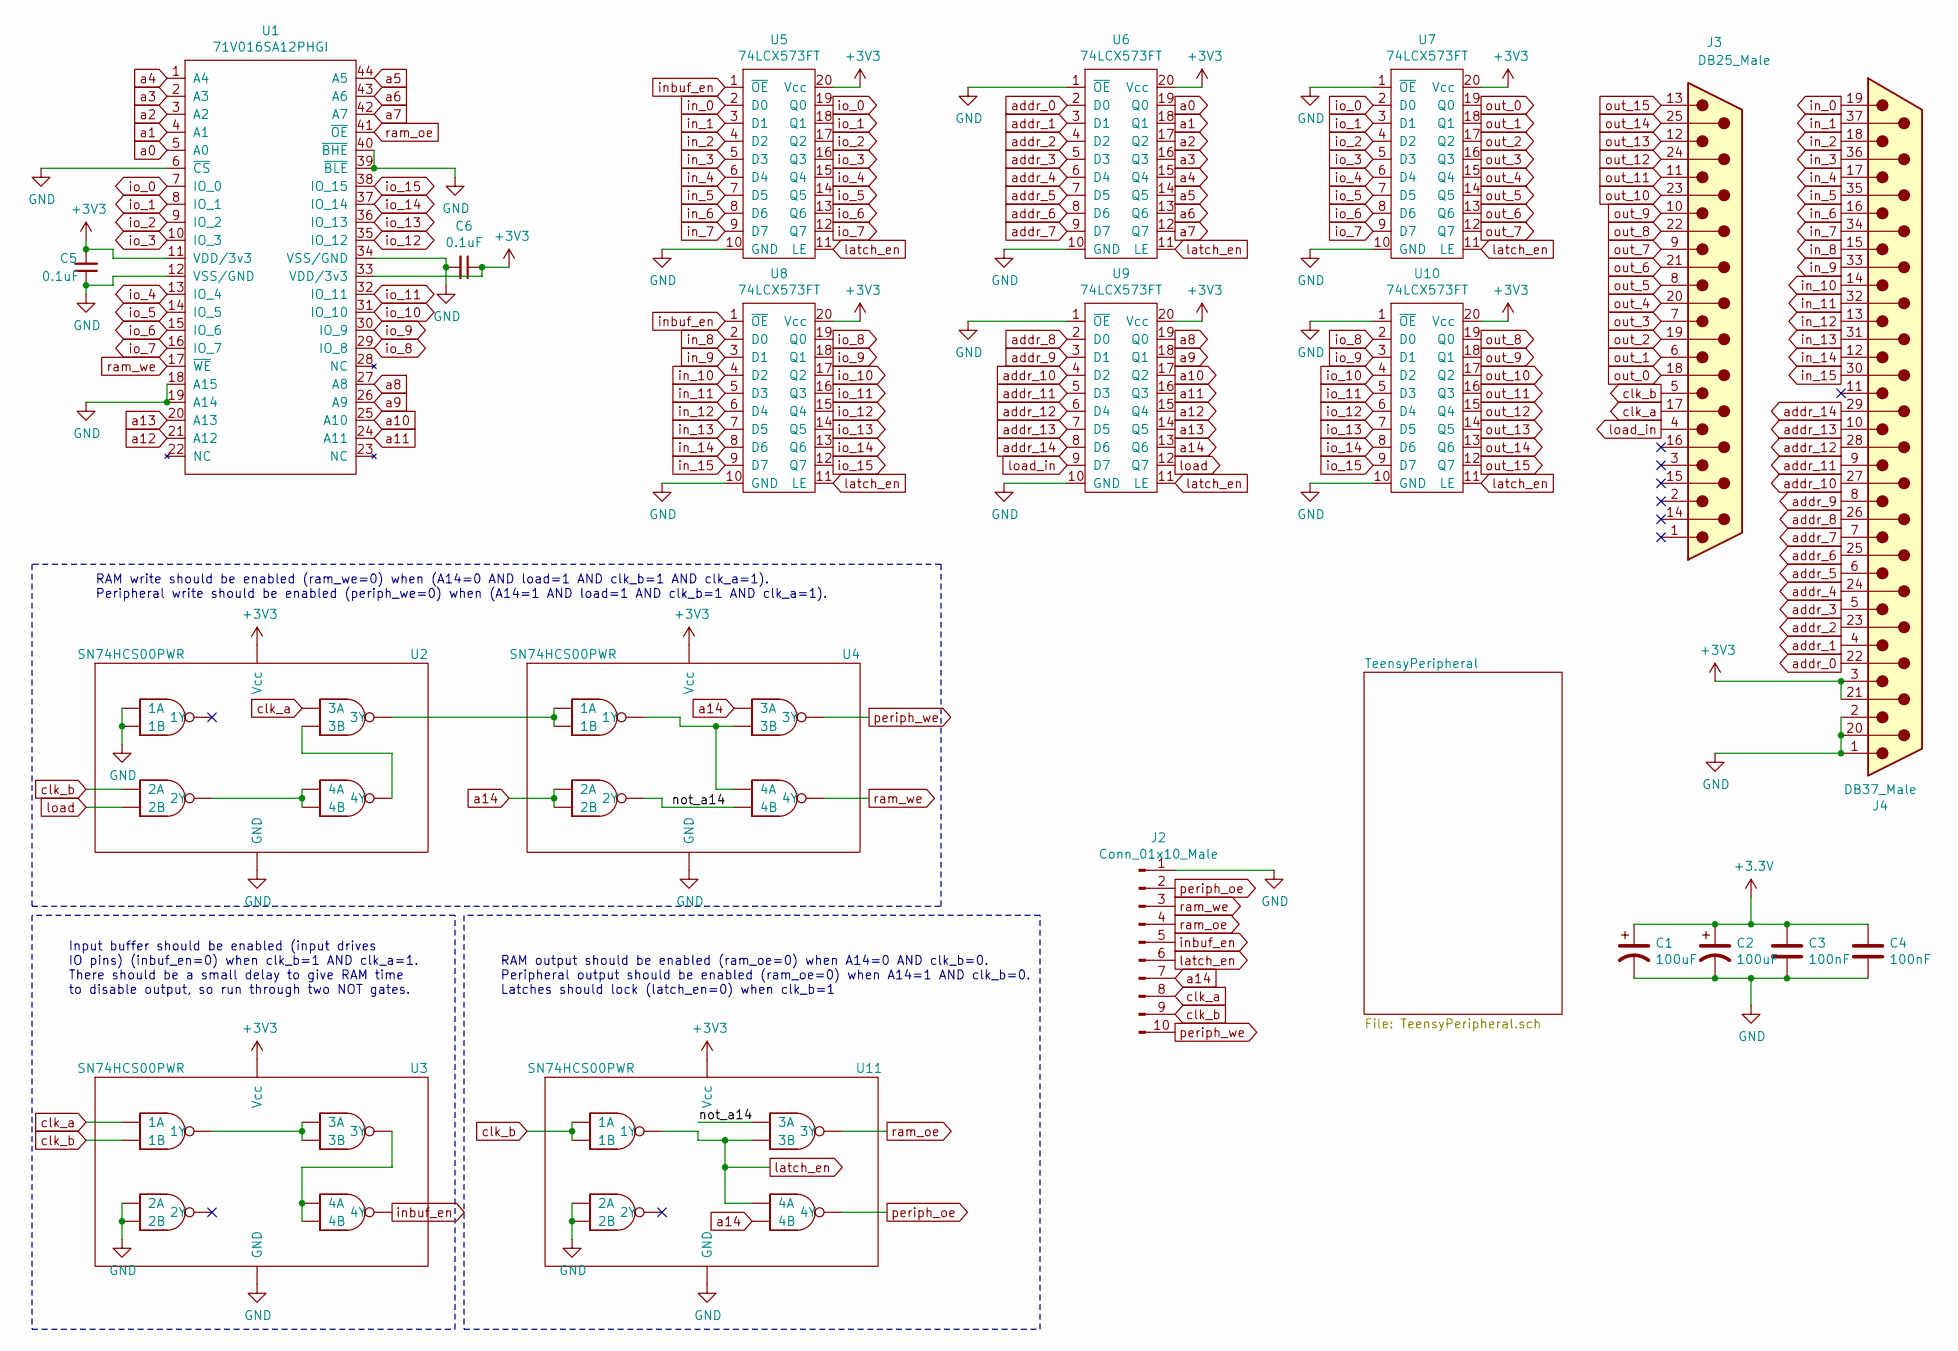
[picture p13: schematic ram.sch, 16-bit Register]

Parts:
C1, C2: 100uF; CP_Radial_D8.0mm_P2.50mm; Digikey PN P15797CT-ND
C3, C4: 100nF; C_Disc_D5.0mm_W2.5mm_P5.00mm; Digikey PN BC5229CT-ND
C5, C6: 0.1uF; C_1206_3216Metric; Digikey PN 399-C1206C104K5RAC7800CT-ND
J2: Conn_01x10_Male; PinHeader_1x10_P2.54mm_Vertical
J3: DB25_Male; DSUB-25_Male_Horizontal_P2.77x2.84mm_EdgePinOffset7.70mm_Ho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; Digikey PN AE10980-ND
J4: DB37_Male; DSUB-37_Male_Horizontal_P2.77x2.84mm_EdgePinOffset7.70mm_Ho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; Digikey PN AE10986-ND
U1: 71V016SA12PHGI; TSOP-II-44_10.16x18.41mm_P0.8mm; Digikey PN 800-2609-5-ND
U2, U3, U4, U11: SN74HCS00PWR; TSSOP-14_4.4x5mm_P0.65mm; Digikey PN 296-SN74HCS00PWRCT-ND
U5, U6, U7, U8, U9, U10: 74LCX573FT; TSSOP-20_4.4x6.5mm_P0.65mm; Digikey PN 74LCX573FT(AJ)CT-ND

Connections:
/not_a14: U4.6 (2Y), U4.13 (4B), U11.9 (3A)
GND: C1.2, C2.2, C3.2, C4.2, C5.1, C6.2, J2.1, J4.1, J4.2, J4.20, U1.6 (~CS), U1.12 (VSS/GND), U1.18 (A15), U1.19 (A14), U1.34 (VSS/GND), U1.39 (~BLE), U1.40 (~BHE), U2.1 (1A), U2.2 (1B), U2.7 (GND), U3.4 (2A), U3.5 (2B), U3.7 (GND), U4.7 (GND), U5.10 (GND), U6.1 (~OE), U6.10 (GND), U7.1 (~OE), U7.10 (GND), U8.10 (GND), U9.1 (~OE), U9.10 (GND), U10.1 (~OE), U10.10 (GND), U11.4 (2A), U11.5 (2B), U11.7 (GND); also elsewhere on the board
unnamed: U2.8 (3Y), U4.1 (1A), U4.2 (1B)
unnamed: U2.10 (3B), U2.11 (4Y)
unnamed: U2.6 (2Y), U2.12 (4A), U2.13 (4B)
unnamed: U3.3 (1Y), U3.9 (3A), U3.10 (3B)
unnamed: U3.8 (3Y), U3.12 (4A), U3.13 (4B)
unnamed: U4.3 (1Y), U4.10 (3B), U4.12 (4A)
a0: U1.5 (A0), U6.19 (Q0); also elsewhere on the board
a1: U1.4 (A1), U6.18 (Q1); also elsewhere on the board
a2: U1.3 (A2), U6.17 (Q2); also elsewhere on the board
a3: U1.2 (A3), U6.16 (Q3); also elsewhere on the board
a4: U1.1 (A4), U6.15 (Q4); also elsewhere on the board
a5: U1.44 (A5), U6.14 (Q5); also elsewhere on the board
a6: U1.43 (A6), U6.13 (Q6); also elsewhere on the board
a7: U1.42 (A7), U6.12 (Q7); also elsewhere on the board
a8: U1.27 (A8), U9.19 (Q0); also elsewhere on the board
a9: U1.26 (A9), U9.18 (Q1); also elsewhere on the board
a10: U1.25 (A10), U9.17 (Q2); also elsewhere on the board
a11: U1.24 (A11), U9.16 (Q3); also elsewhere on the board
a12: U1.21 (A12), U9.15 (Q4); also elsewhere on the board
a13: U1.20 (A13), U9.14 (Q5); also elsewhere on the board
a14: J2.7, U4.4 (2A), U4.5 (2B), U4.9 (3A), U9.13 (Q6), U11.13 (4B); also elsewhere on the board
addr_0: J4.22, U6.2 (D0)
addr_1: J4.4, U6.3 (D1)
addr_2: J4.23, U6.4 (D2)
addr_3: J4.5, U6.5 (D3)
addr_4: J4.24, U6.6 (D4)
addr_5: J4.6, U6.7 (D5)
addr_6: J4.25, U6.8 (D6)
addr_7: J4.7, U6.9 (D7)
addr_8: J4.26, U9.2 (D0)
addr_9: J4.8, U9.3 (D1)
addr_10: J4.27, U9.4 (D2)
addr_11: J4.9, U9.5 (D3)
addr_12: J4.28, U9.6 (D4)
addr_13: J4.10, U9.7 (D5)
addr_14: J4.29, U9.8 (D6)
clk_a: J2.8, J3.17, U2.9 (3A), U3.1 (1A); also elsewhere on the board
clk_b: J2.9, J3.5, U2.4 (2A), U3.2 (1B), U11.1 (1A), U11.2 (1B); also elsewhere on the board
in_0: J4.19, U5.2 (D0)
in_1: J4.37, U5.3 (D1)
in_2: J4.18, U5.4 (D2)
in_3: J4.36, U5.5 (D3)
in_4: J4.17, U5.6 (D4)
in_5: J4.35, U5.7 (D5)
in_6: J4.16, U5.8 (D6)
in_7: J4.34, U5.9 (D7)
in_8: J4.15, U8.2 (D0)
in_9: J4.33, U8.3 (D1)
in_10: J4.14, U8.4 (D2)
in_11: J4.32, U8.5 (D3)
in_12: J4.13, U8.6 (D4)
in_13: J4.31, U8.7 (D5)
in_14: J4.12, U8.8 (D6)
in_15: J4.30, U8.9 (D7)
inbuf_en: J2.5, U3.11 (4Y), U5.1 (~OE), U8.1 (~OE)
io_0: U1.7 (IO_0), U5.19 (Q0), U7.2 (D0); also elsewhere on the board
io_1: U1.8 (IO_1), U5.18 (Q1), U7.3 (D1); also elsewhere on the board
io_2: U1.9 (IO_2), U5.17 (Q2), U7.4 (D2); also elsewhere on the board
io_3: U1.10 (IO_3), U5.16 (Q3), U7.5 (D3); also elsewhere on the board
io_4: U1.13 (IO_4), U5.15 (Q4), U7.6 (D4); also elsewhere on the board
io_5: U1.14 (IO_5), U5.14 (Q5), U7.7 (D5); also elsewhere on the board
io_6: U1.15 (IO_6), U5.13 (Q6), U7.8 (D6); also elsewhere on the board
io_7: U1.16 (IO_7), U5.12 (Q7), U7.9 (D7); also elsewhere on the board
io_8: U1.29 (IO_8), U8.19 (Q0), U10.2 (D0); also elsewhere on the board
io_9: U1.30 (IO_9), U8.18 (Q1), U10.3 (D1); also elsewhere on the board
io_10: U1.31 (IO_10), U8.17 (Q2), U10.4 (D2); also elsewhere on the board
io_11: U1.32 (IO_11), U8.16 (Q3), U10.5 (D3); also elsewhere on the board
io_12: U1.35 (IO_12), U8.15 (Q4), U10.6 (D4); also elsewhere on the board
io_13: U1.36 (IO_13), U8.14 (Q5), U10.7 (D5); also elsewhere on the board
io_14: U1.37 (IO_14), U8.13 (Q6), U10.8 (D6); also elsewhere on the board
io_15: U1.38 (IO_15), U8.12 (Q7), U10.9 (D7); also elsewhere on the board
latch_en: J2.6, U5.11 (LE), U6.11 (LE), U7.11 (LE), U8.11 (LE), U9.11 (LE), U10.11 (LE), U11.3 (1Y), U11.10 (3B), U11.12 (4A)
load: U2.5 (2B), U9.12 (Q7); also elsewhere on the board
load_in: J3.4, U9.9 (D7)
out_0: J3.18, U7.19 (Q0)
out_1: J3.6, U7.18 (Q1)
out_2: J3.19, U7.17 (Q2)
out_3: J3.7, U7.16 (Q3)
out_4: J3.20, U7.15 (Q4)
out_5: J3.8, U7.14 (Q5)
out_6: J3.21, U7.13 (Q6)
out_7: J3.9, U7.12 (Q7)
out_8: J3.22, U10.19 (Q0)
out_9: J3.10, U10.18 (Q1)
out_10: J3.23, U10.17 (Q2)
out_11: J3.11, U10.16 (Q3)
out_12: J3.24, U10.15 (Q4)
out_13: J3.12, U10.14 (Q5)
out_14: J3.25, U10.13 (Q6)
out_15: J3.13, U10.12 (Q7)
periph_oe: J2.2, U11.11 (4Y); also elsewhere on the board
periph_we: J2.10, U4.8 (3Y); also elsewhere on the board
ram_oe: J2.4, U1.41 (~OE), U11.8 (3Y)
ram_we: J2.3, U1.17 (~WE), U4.11 (4Y)

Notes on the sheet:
Input buffer should be enabled (input drives IO pins) (inbuf_en=0) when clk_b=1 AND clk_a=1. There should be a small delay to give RAM time to disable output, so run through two NOT gates.
RAM write should be enabled (ram_we=0) when (A14=0 AND load=1 AND clk_b=1 AND clk_a=1). Peripheral write should be enabled (periph_we=0) when (A14=1 AND load=1 AND clk_b=1 AND clk_a=1).
RAM output should be enabled (ram_oe=0) when A14=0 AND clk_b=0. Peripheral output should be enabled (ram_oe=0) when A14=1 AND clk_b=0. Latches should lock (latch_en=0) when clk_b=1

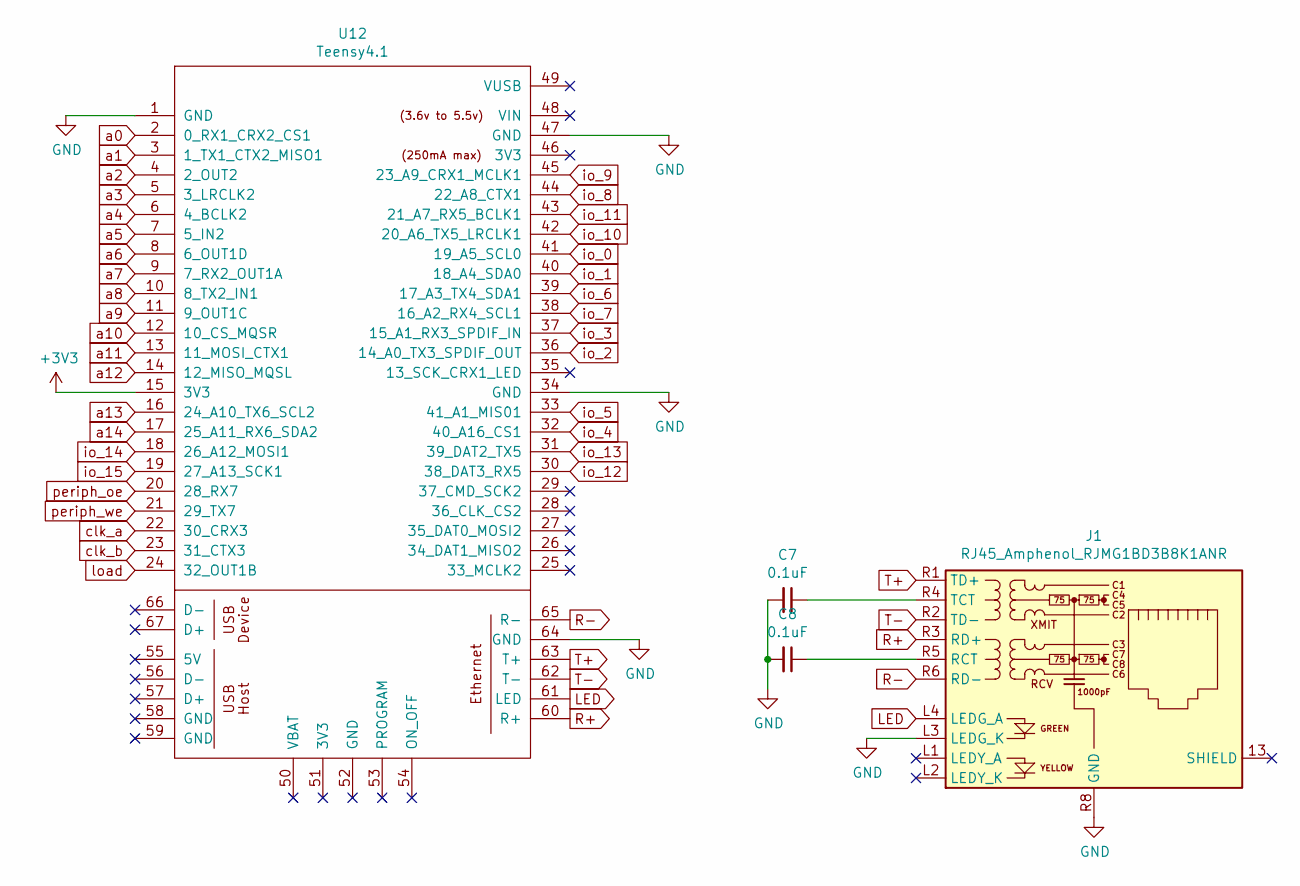
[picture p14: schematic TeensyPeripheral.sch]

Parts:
C7, C8: 0.1uF; C_1206_3216Metric; Digikey PN 399-C1206C104K5RAC7800CT-ND
J1: RJ45_Amphenol_RJMG1BD3B8K1ANR; Digikey PN RJMG1BD3B8K1ANR-ND
U12: Teensy4.1; Teensy41

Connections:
GND: C7.2, C8.2, J1.L3 (LEDG_K), J1.R8 (GND), U12.1 (GND), U12.34 (GND), U12.47 (GND), U12.64 (GND); also elsewhere on the board
LED: J1.L4 (LEDG_A), U12.61 (LED)
unnamed: C7.1, J1.R4 (TCT)
unnamed: C8.1, J1.R5 (RCT)
R+: J1.R3 (RD+), U12.60 (R+)
R-: J1.R6 (RD-), U12.65 (R-)
T+: J1.R1 (TD+), U12.63 (T+)
T-: J1.R2 (TD-), U12.62 (T-)
a0: U12.2 (0_RX1_CRX2_CS1); also elsewhere on the board
a1: U12.3 (1_TX1_CTX2_MISO1); also elsewhere on the board
a2: U12.4 (2_OUT2); also elsewhere on the board
a3: U12.5 (3_LRCLK2); also elsewhere on the board
a4: U12.6 (4_BCLK2); also elsewhere on the board
a5: U12.7 (5_IN2); also elsewhere on the board
a6: U12.8 (6_OUT1D); also elsewhere on the board
a7: U12.9 (7_RX2_OUT1A); also elsewhere on the board
a8: U12.10 (8_TX2_IN1); also elsewhere on the board
a9: U12.11 (9_OUT1C); also elsewhere on the board
a10: U12.12 (10_CS_MQSR); also elsewhere on the board
a11: U12.13 (11_MOSI_CTX1); also elsewhere on the board
a12: U12.14 (12_MISO_MQSL); also elsewhere on the board
a13: U12.16 (24_A10_TX6_SCL2); also elsewhere on the board
a14: U12.17 (25_A11_RX6_SDA2); also elsewhere on the board
clk_a: U12.22 (30_CRX3); also elsewhere on the board
clk_b: U12.23 (31_CTX3); also elsewhere on the board
io_0: U12.41 (19_A5_SCL0); also elsewhere on the board
io_1: U12.40 (18_A4_SDA0); also elsewhere on the board
io_2: U12.36 (14_A0_TX3_SPDIF_OUT); also elsewhere on the board
io_3: U12.37 (15_A1_RX3_SPDIF_IN); also elsewhere on the board
io_4: U12.32 (40_A16_CS1); also elsewhere on the board
io_5: U12.33 (41_A1_MIS01); also elsewhere on the board
io_6: U12.39 (17_A3_TX4_SDA1); also elsewhere on the board
io_7: U12.38 (16_A2_RX4_SCL1); also elsewhere on the board
io_8: U12.44 (22_A8_CTX1); also elsewhere on the board
io_9: U12.45 (23_A9_CRX1_MCLK1); also elsewhere on the board
io_10: U12.42 (20_A6_TX5_LRCLK1); also elsewhere on the board
io_11: U12.43 (21_A7_RX5_BCLK1); also elsewhere on the board
io_12: U12.30 (38_DAT3_RX5); also elsewhere on the board
io_13: U12.31 (39_DAT2_TX5); also elsewhere on the board
io_14: U12.18 (26_A12_MOSI1); also elsewhere on the board
io_15: U12.19 (27_A13_SCK1); also elsewhere on the board
load: U12.24 (32_OUT1B); also elsewhere on the board
periph_oe: U12.20 (28_RX7); also elsewhere on the board
periph_we: U12.21 (29_TX7); also elsewhere on the board

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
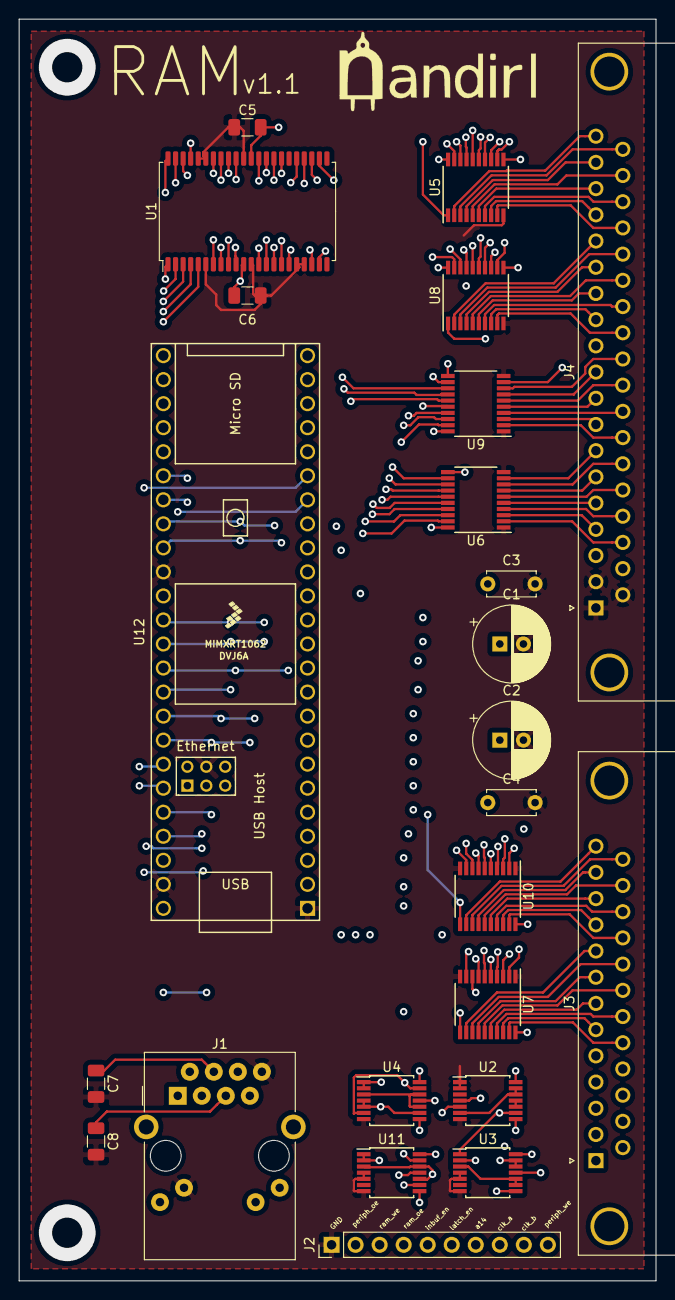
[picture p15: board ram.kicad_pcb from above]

Board: 4 copper layers, 67.3 x 133.3 mm, 24 parts (0 on the bottom side), 104 nets.

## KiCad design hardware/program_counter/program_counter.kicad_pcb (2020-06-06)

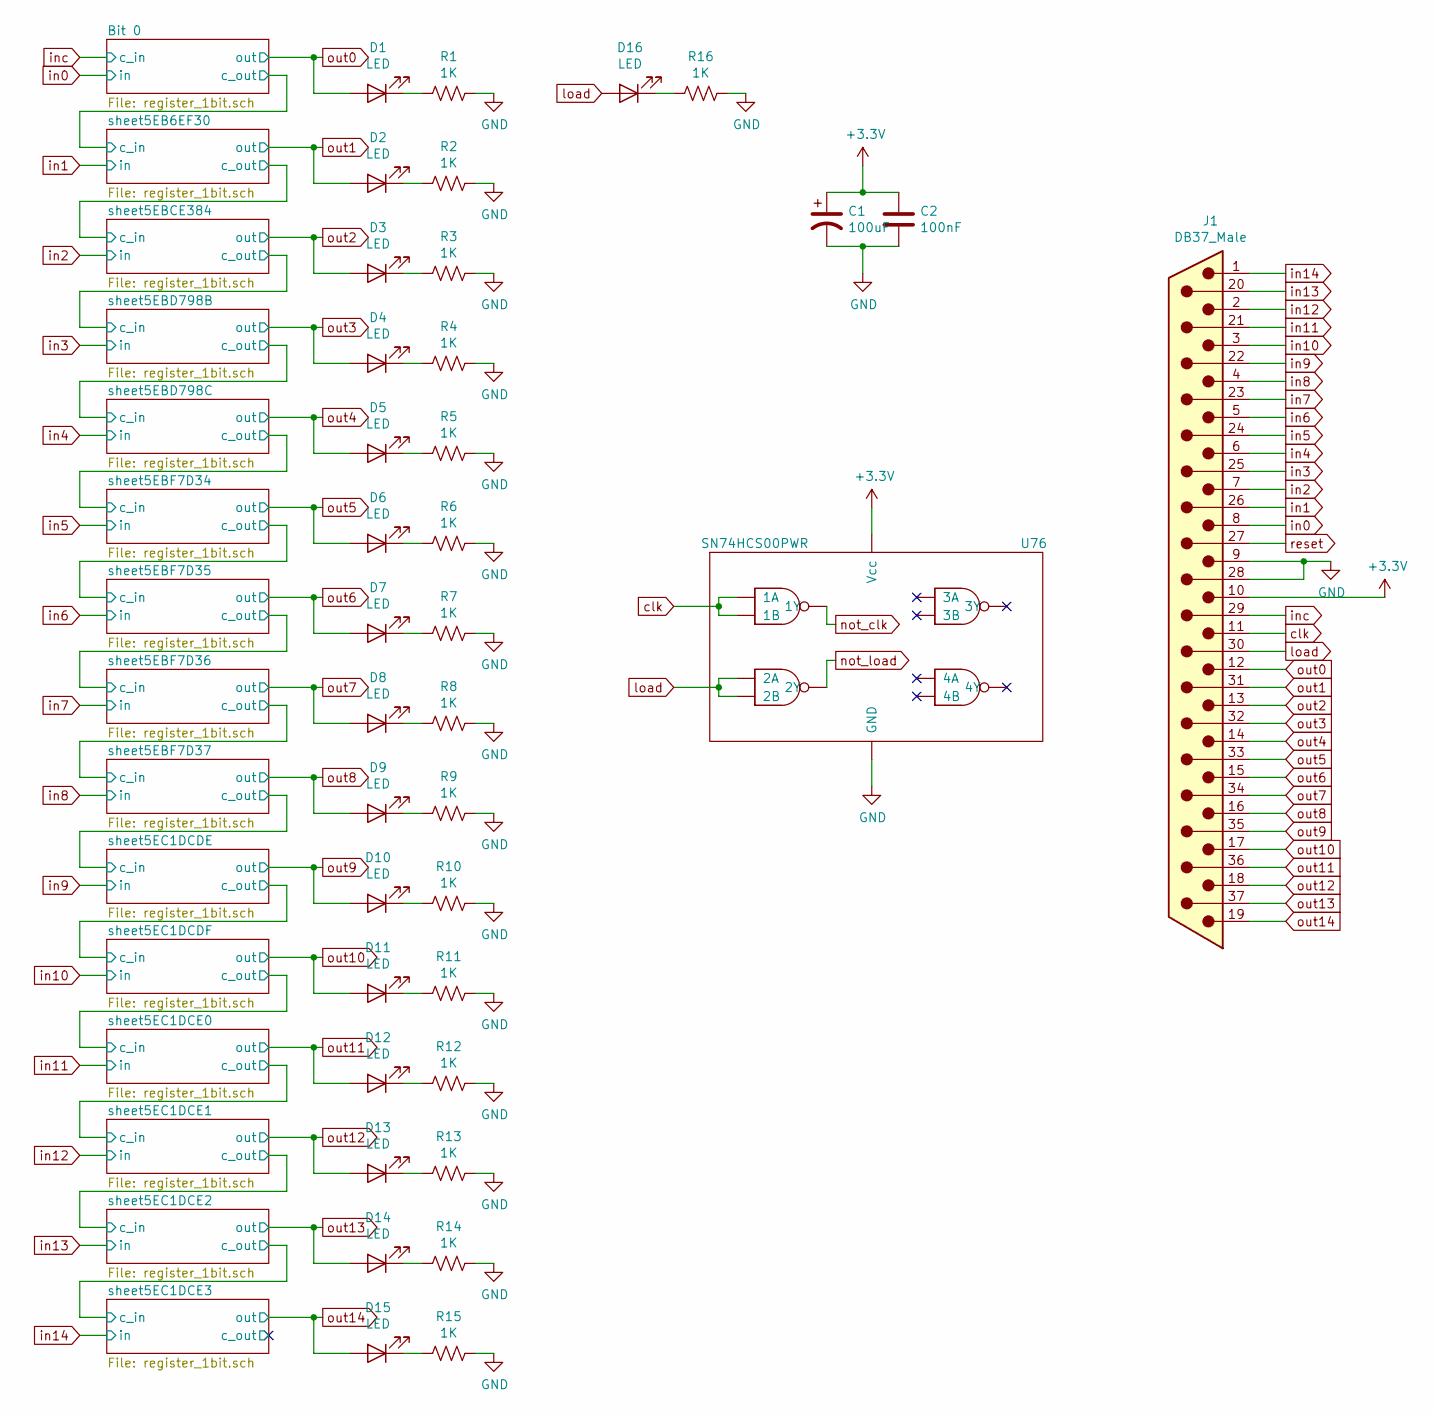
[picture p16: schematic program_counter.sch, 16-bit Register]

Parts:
C1: 100uF; CP_Radial_D8.0mm_P2.50mm; Digikey PN P15797CT-ND
C2: 100nF; C_Disc_D5.0mm_W2.5mm_P5.00mm; Digikey PN BC5229CT-ND
D1, D2, D3, D4, D5, D6, D7, D8, D9, D10, D11, D12, D13, D14, D15, D16: LED; LED_D5.0mm
J1: DB37_Male; DSUB-37_Male_Horizontal_P2.77x2.84mm_EdgePinOffset7.70mm_Ho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; Digikey PN AE10986-ND
R1, R2, R3, R4, R5, R6, R7, R8, R9, R10, R11, R12, R13, R14, R15, R16: 1K; R_1206_3216Metric; Digikey PN P1.0KECT-ND
U76: SN74HCS00PWR; TSSOP-14_4.4x5mm_P0.65mm; Digikey PN 296-SN74HCS00PWRCT-ND

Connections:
GND: C1.2, C2.2, J1.9, J1.28, R1.1, R2.1, R3.1, R4.1, R5.1, R6.1, R7.1, R8.1, R9.1, R10.1, R11.1, R12.1, R13.1, R14.1, R15.1, R16.1, U76.7 (GND); also elsewhere on the board
unnamed: D1.1 (K), R1.2
unnamed: D2.1 (K), R2.2
unnamed: D3.1 (K), R3.2
unnamed: D4.1 (K), R4.2
unnamed: D5.1 (K), R5.2
unnamed: D6.1 (K), R6.2
unnamed: D7.1 (K), R7.2
unnamed: D8.1 (K), R8.2
unnamed: D9.1 (K), R9.2
unnamed: D10.1 (K), R10.2
unnamed: D11.1 (K), R11.2
unnamed: D12.1 (K), R12.2
unnamed: D13.1 (K), R13.2
unnamed: D14.1 (K), R14.2
unnamed: D15.1 (K), R15.2
unnamed: D16.1 (K), R16.2
clk: J1.11, U76.1 (1A), U76.2 (1B); also elsewhere on the board
in0: J1.8; also elsewhere on the board
in1: J1.26; also elsewhere on the board
in2: J1.7; also elsewhere on the board
in3: J1.25; also elsewhere on the board
in4: J1.6; also elsewhere on the board
in5: J1.24; also elsewhere on the board
in6: J1.5; also elsewhere on the board
in7: J1.23; also elsewhere on the board
in8: J1.4; also elsewhere on the board
in9: J1.22; also elsewhere on the board
in10: J1.3; also elsewhere on the board
in11: J1.21; also elsewhere on the board
in12: J1.2; also elsewhere on the board
in13: J1.20; also elsewhere on the board
in14: J1.1; also elsewhere on the board
inc: J1.29; also elsewhere on the board
load: D16.2 (A), J1.30, U76.4 (2A), U76.5 (2B); also elsewhere on the board
not_clk: U76.3 (1Y); also elsewhere on the board
not_load: U76.6 (2Y); also elsewhere on the board
out0: D1.2 (A), J1.12; also elsewhere on the board
out1: D2.2 (A), J1.31; also elsewhere on the board
out2: D3.2 (A), J1.13; also elsewhere on the board
out3: D4.2 (A), J1.32; also elsewhere on the board
out4: D5.2 (A), J1.14; also elsewhere on the board
out5: D6.2 (A), J1.33; also elsewhere on the board
out6: D7.2 (A), J1.15; also elsewhere on the board
out7: D8.2 (A), J1.34; also elsewhere on the board
out8: D9.2 (A), J1.16; also elsewhere on the board
out9: D10.2 (A), J1.35; also elsewhere on the board
out10: D11.2 (A), J1.17; also elsewhere on the board
out11: D12.2 (A), J1.36; also elsewhere on the board
out12: D13.2 (A), J1.18; also elsewhere on the board
out13: D14.2 (A), J1.37; also elsewhere on the board
out14: D15.2 (A), J1.19; also elsewhere on the board
reset: J1.27; also elsewhere on the board

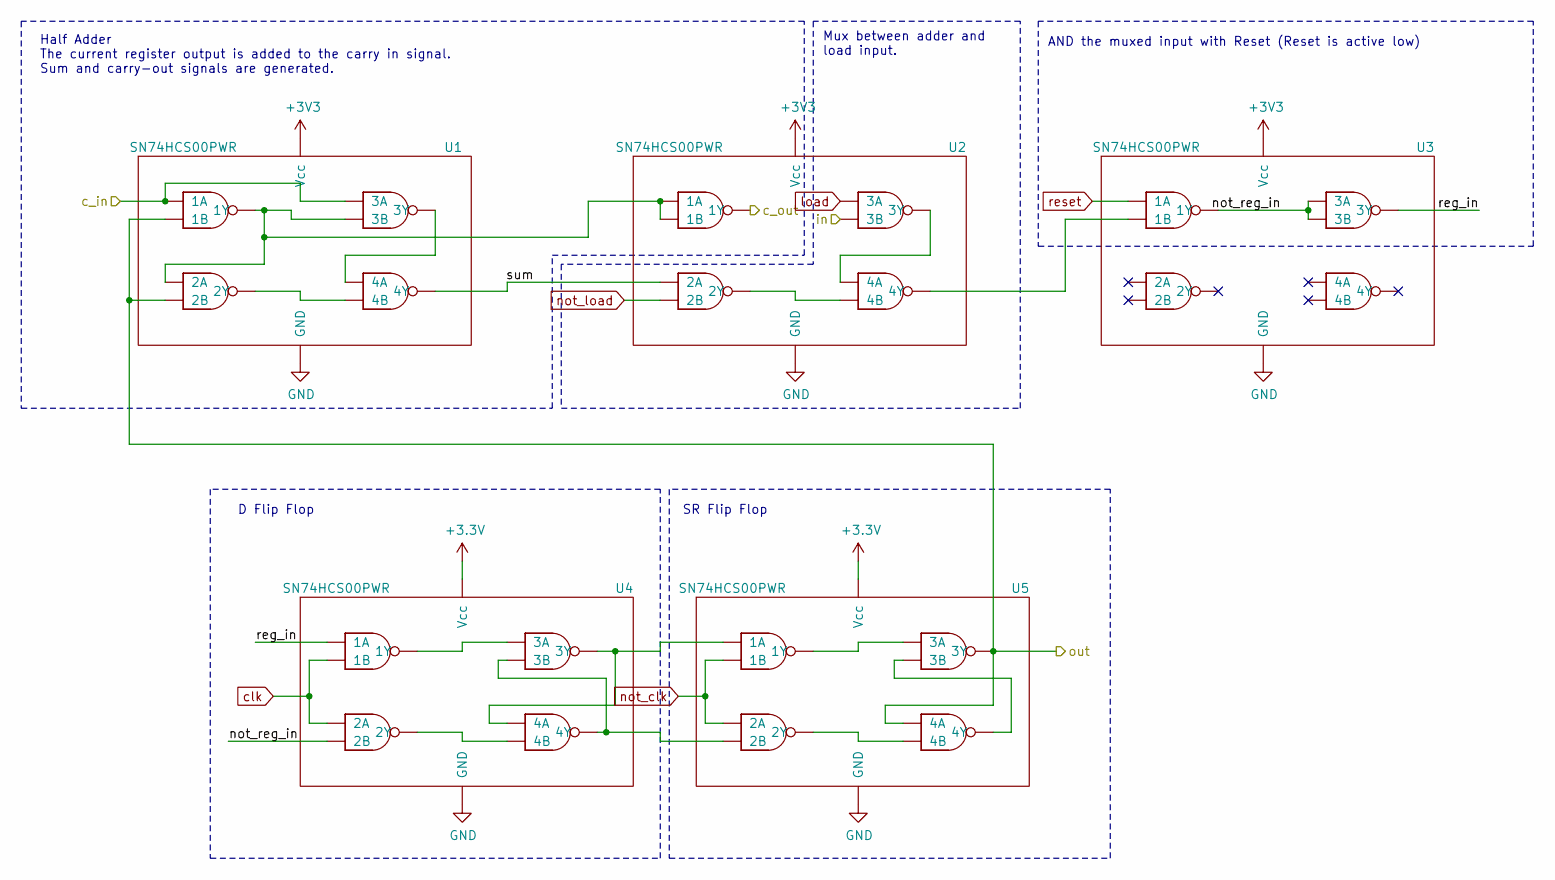
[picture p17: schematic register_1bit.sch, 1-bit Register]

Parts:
U1, U2, U3, U4, U5: SN74HCS00PWR; TSSOP-14_4.4x5mm_P0.65mm; Digikey PN 296-SN74HCS00PWRCT-ND

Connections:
/Bit 0/not_reg_in: U3.3 (1Y), U3.9 (3A), U3.10 (3B), U4.5 (2B)
/Bit 0/reg_in: U3.8 (3Y), U4.1 (1A)
/Bit 0/sum: U1.11 (4Y), U2.4 (2A)
/sheet5EB6EF30/c_in: U2.3 (1Y); also elsewhere on the board
GND: U1.7 (GND), U2.7 (GND), U3.7 (GND), U4.7 (GND), U5.7 (GND); also elsewhere on the board
unnamed: U1.3 (1Y), U1.4 (2A), U1.10 (3B), U2.1 (1A), U2.2 (1B)
unnamed: U1.8 (3Y), U1.12 (4A)
unnamed: U1.6 (2Y), U1.13 (4B)
unnamed: U2.11 (4Y), U3.2 (1B)
unnamed: U2.8 (3Y), U2.12 (4A)
unnamed: U2.6 (2Y), U2.13 (4B)
unnamed: U4.3 (1Y), U4.9 (3A)
unnamed: U4.10 (3B), U4.11 (4Y), U5.5 (2B)
unnamed: U4.8 (3Y), U4.12 (4A), U5.1 (1A)
unnamed: U4.6 (2Y), U4.13 (4B)
unnamed: U5.3 (1Y), U5.9 (3A)
unnamed: U5.10 (3B), U5.11 (4Y)
unnamed: U5.6 (2Y), U5.13 (4B)
clk: U4.2 (1B), U4.4 (2A); also elsewhere on the board
in0: U2.10 (3B); also elsewhere on the board
inc: U1.1 (1A), U1.9 (3A); also elsewhere on the board
load: U2.9 (3A); also elsewhere on the board
not_clk: U5.2 (1B), U5.4 (2A); also elsewhere on the board
not_load: U2.5 (2B); also elsewhere on the board
out0: U1.2 (1B), U1.5 (2B), U5.8 (3Y), U5.12 (4A); also elsewhere on the board
reset: U3.1 (1A); also elsewhere on the board

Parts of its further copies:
U6, U7, U8, U9, U10, U11, U12, U13, U14, U15, U16, U17, U18, U19, U20, U21, U22, U23, U24, U25, U26, U27, U28, U29, U30, U31, U32, U33, U34, U35, U36, U37, U38, U39, U40, U41, U42, U43, U44, U45, U46, U47, U48, U49, U50, U51, U52, U53, U54, U55, U56, U57, U58, U59, U60, U61, U62, U63, U64, U65, U66, U67, U68, U69, U70, U71, U72, U73, U74, U75: SN74HCS00PWR; TSSOP-14_4.4x5mm_P0.65mm; Digikey PN 296-SN74HCS00PWRCT-ND

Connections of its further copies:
/sheet5EB6EF30/c_in: U71.1 (1A), U71.9 (3A); also elsewhere on the board
/sheet5EB6EF30/not_reg_in: U73.3 (1Y), U73.9 (3A), U73.10 (3B), U74.5 (2B)
/sheet5EB6EF30/reg_in: U73.8 (3Y), U74.1 (1A)
/sheet5EB6EF30/sum: U71.11 (4Y), U72.4 (2A)
/sheet5EBCE384/c_in: U66.1 (1A), U66.9 (3A), U72.3 (1Y)
/sheet5EBCE384/not_reg_in: U68.3 (1Y), U68.9 (3A), U68.10 (3B), U69.5 (2B)
/sheet5EBCE384/reg_in: U68.8 (3Y), U69.1 (1A)
/sheet5EBCE384/sum: U66.11 (4Y), U67.4 (2A)
/sheet5EBD798B/c_in: U61.1 (1A), U61.9 (3A), U67.3 (1Y)
/sheet5EBD798B/not_reg_in: U63.3 (1Y), U63.9 (3A), U63.10 (3B), U64.5 (2B)
/sheet5EBD798B/reg_in: U63.8 (3Y), U64.1 (1A)
/sheet5EBD798B/sum: U61.11 (4Y), U62.4 (2A)
/sheet5EBD798C/c_in: U56.1 (1A), U56.9 (3A), U62.3 (1Y)
/sheet5EBD798C/not_reg_in: U58.3 (1Y), U58.9 (3A), U58.10 (3B), U59.5 (2B)
/sheet5EBD798C/reg_in: U58.8 (3Y), U59.1 (1A)
/sheet5EBD798C/sum: U56.11 (4Y), U57.4 (2A)
/sheet5EBF7D34/c_in: U51.1 (1A), U51.9 (3A), U57.3 (1Y)
/sheet5EBF7D34/not_reg_in: U53.3 (1Y), U53.9 (3A), U53.10 (3B), U54.5 (2B)
/sheet5EBF7D34/reg_in: U53.8 (3Y), U54.1 (1A)
/sheet5EBF7D34/sum: U51.11 (4Y), U52.4 (2A)
/sheet5EBF7D35/c_in: U46.1 (1A), U46.9 (3A), U52.3 (1Y)
/sheet5EBF7D35/not_reg_in: U48.3 (1Y), U48.9 (3A), U48.10 (3B), U49.5 (2B)
/sheet5EBF7D35/reg_in: U48.8 (3Y), U49.1 (1A)
/sheet5EBF7D35/sum: U46.11 (4Y), U47.4 (2A)
/sheet5EBF7D36/c_in: U41.1 (1A), U41.9 (3A), U47.3 (1Y)
/sheet5EBF7D36/not_reg_in: U43.3 (1Y), U43.9 (3A), U43.10 (3B), U44.5 (2B)
/sheet5EBF7D36/reg_in: U43.8 (3Y), U44.1 (1A)
/sheet5EBF7D36/sum: U41.11 (4Y), U42.4 (2A)
/sheet5EBF7D37/c_in: U36.1 (1A), U36.9 (3A), U42.3 (1Y)
/sheet5EBF7D37/not_reg_in: U38.3 (1Y), U38.9 (3A), U38.10 (3B), U39.5 (2B)
/sheet5EBF7D37/reg_in: U38.8 (3Y), U39.1 (1A)
/sheet5EBF7D37/sum: U36.11 (4Y), U37.4 (2A)
/sheet5EC1DCDE/c_in: U31.1 (1A), U31.9 (3A), U37.3 (1Y)
/sheet5EC1DCDE/not_reg_in: U33.3 (1Y), U33.9 (3A), U33.10 (3B), U34.5 (2B)
/sheet5EC1DCDE/reg_in: U33.8 (3Y), U34.1 (1A)
/sheet5EC1DCDE/sum: U31.11 (4Y), U32.4 (2A)
/sheet5EC1DCDF/c_in: U26.1 (1A), U26.9 (3A), U32.3 (1Y)
/sheet5EC1DCDF/not_reg_in: U28.3 (1Y), U28.9 (3A), U28.10 (3B), U29.5 (2B)
/sheet5EC1DCDF/reg_in: U28.8 (3Y), U29.1 (1A)
/sheet5EC1DCDF/sum: U26.11 (4Y), U27.4 (2A)
/sheet5EC1DCE0/c_in: U21.1 (1A), U21.9 (3A), U27.3 (1Y)
/sheet5EC1DCE0/not_reg_in: U23.3 (1Y), U23.9 (3A), U23.10 (3B), U24.5 (2B)
/sheet5EC1DCE0/reg_in: U23.8 (3Y), U24.1 (1A)
/sheet5EC1DCE0/sum: U21.11 (4Y), U22.4 (2A)
/sheet5EC1DCE1/c_in: U16.1 (1A), U16.9 (3A), U22.3 (1Y)
/sheet5EC1DCE1/not_reg_in: U18.3 (1Y), U18.9 (3A), U18.10 (3B), U19.5 (2B)
/sheet5EC1DCE1/reg_in: U18.8 (3Y), U19.1 (1A)
/sheet5EC1DCE1/sum: U16.11 (4Y), U17.4 (2A)
/sheet5EC1DCE2/c_in: U11.1 (1A), U11.9 (3A), U17.3 (1Y)
/sheet5EC1DCE2/not_reg_in: U13.3 (1Y), U13.9 (3A), U13.10 (3B), U14.5 (2B)
/sheet5EC1DCE2/reg_in: U13.8 (3Y), U14.1 (1A)
/sheet5EC1DCE2/sum: U11.11 (4Y), U12.4 (2A)
/sheet5EC1DCE3/c_in: U6.1 (1A), U6.9 (3A), U12.3 (1Y)
/sheet5EC1DCE3/c_out: U7.3 (1Y)
/sheet5EC1DCE3/not_reg_in: U8.3 (1Y), U8.9 (3A), U8.10 (3B), U9.5 (2B)
/sheet5EC1DCE3/reg_in: U8.8 (3Y), U9.1 (1A)
/sheet5EC1DCE3/sum: U6.11 (4Y), U7.4 (2A)
GND: U6.7 (GND), U7.7 (GND), U8.7 (GND), U9.7 (GND), U10.7 (GND), U11.7 (GND), U12.7 (GND), U13.7 (GND), U14.7 (GND), U15.7 (GND), U16.7 (GND), U17.7 (GND), U18.7 (GND), U19.7 (GND), U20.7 (GND), U21.7 (GND), U22.7 (GND), U23.7 (GND), U24.7 (GND), U25.7 (GND), U26.7 (GND), U27.7 (GND), U28.7 (GND), U29.7 (GND), U30.7 (GND), U31.7 (GND), U32.7 (GND), U33.7 (GND), U34.7 (GND), U35.7 (GND), U36.7 (GND), U37.7 (GND), U38.7 (GND), U39.7 (GND), U40.7 (GND), U41.7 (GND), U42.7 (GND), U43.7 (GND), U44.7 (GND), U45.7 (GND), U46.7 (GND), U47.7 (GND), U48.7 (GND), U49.7 (GND), U50.7 (GND), U51.7 (GND), U52.7 (GND), U53.7 (GND), U54.7 (GND), U55.7 (GND), U56.7 (GND), U57.7 (GND), U58.7 (GND), U59.7 (GND), U60.7 (GND), U61.7 (GND), U62.7 (GND), U63.7 (GND), U64.7 (GND), U65.7 (GND), U66.7 (GND), U67.7 (GND), U68.7 (GND), U69.7 (GND), U70.7 (GND), U71.7 (GND), U72.7 (GND), U73.7 (GND), U74.7 (GND), U75.7 (GND); also elsewhere on the board
unnamed: U6.3 (1Y), U6.4 (2A), U6.10 (3B), U7.1 (1A), U7.2 (1B)
unnamed: U6.8 (3Y), U6.12 (4A)
unnamed: U6.6 (2Y), U6.13 (4B)
unnamed: U7.11 (4Y), U8.2 (1B)
unnamed: U7.8 (3Y), U7.12 (4A)
unnamed: U7.6 (2Y), U7.13 (4B)
unnamed: U9.3 (1Y), U9.9 (3A)
unnamed: U9.6 (2Y), U9.13 (4B)
unnamed: U9.8 (3Y), U9.12 (4A), U10.1 (1A)
unnamed: U10.3 (1Y), U10.9 (3A)
unnamed: U9.10 (3B), U9.11 (4Y), U10.5 (2B)
unnamed: U10.10 (3B), U10.11 (4Y)
unnamed: U10.6 (2Y), U10.13 (4B)
unnamed: U11.3 (1Y), U11.4 (2A), U11.10 (3B), U12.1 (1A), U12.2 (1B)
unnamed: U11.8 (3Y), U11.12 (4A)
unnamed: U11.6 (2Y), U11.13 (4B)
unnamed: U12.11 (4Y), U13.2 (1B)
unnamed: U12.8 (3Y), U12.12 (4A)
unnamed: U12.6 (2Y), U12.13 (4B)
unnamed: U14.3 (1Y), U14.9 (3A)
unnamed: U14.10 (3B), U14.11 (4Y), U15.5 (2B)
unnamed: U14.8 (3Y), U14.12 (4A), U15.1 (1A)
unnamed: U14.6 (2Y), U14.13 (4B)
unnamed: U15.3 (1Y), U15.9 (3A)
unnamed: U15.10 (3B), U15.11 (4Y)
unnamed: U15.6 (2Y), U15.13 (4B)
unnamed: U16.3 (1Y), U16.4 (2A), U16.10 (3B), U17.1 (1A), U17.2 (1B)
unnamed: U16.8 (3Y), U16.12 (4A)
unnamed: U16.6 (2Y), U16.13 (4B)
unnamed: U17.11 (4Y), U18.2 (1B)
unnamed: U17.8 (3Y), U17.12 (4A)
unnamed: U17.6 (2Y), U17.13 (4B)
unnamed: U19.3 (1Y), U19.9 (3A)
unnamed: U19.10 (3B), U19.11 (4Y), U20.5 (2B)
unnamed: U19.8 (3Y), U19.12 (4A), U20.1 (1A)
unnamed: U19.6 (2Y), U19.13 (4B)
unnamed: U20.3 (1Y), U20.9 (3A)
unnamed: U20.10 (3B), U20.11 (4Y)
unnamed: U20.6 (2Y), U20.13 (4B)
unnamed: U21.3 (1Y), U21.4 (2A), U21.10 (3B), U22.1 (1A), U22.2 (1B)
unnamed: U21.8 (3Y), U21.12 (4A)
unnamed: U21.6 (2Y), U21.13 (4B)
unnamed: U22.11 (4Y), U23.2 (1B)
unnamed: U22.8 (3Y), U22.12 (4A)
unnamed: U22.6 (2Y), U22.13 (4B)
unnamed: U24.3 (1Y), U24.9 (3A)
unnamed: U24.10 (3B), U24.11 (4Y), U25.5 (2B)
unnamed: U24.8 (3Y), U24.12 (4A), U25.1 (1A)
unnamed: U24.6 (2Y), U24.13 (4B)
unnamed: U25.3 (1Y), U25.9 (3A)
unnamed: U25.10 (3B), U25.11 (4Y)
unnamed: U25.6 (2Y), U25.13 (4B)
unnamed: U26.3 (1Y), U26.4 (2A), U26.10 (3B), U27.1 (1A), U27.2 (1B)
unnamed: U26.8 (3Y), U26.12 (4A)
unnamed: U26.6 (2Y), U26.13 (4B)
unnamed: U27.11 (4Y), U28.2 (1B)
unnamed: U27.8 (3Y), U27.12 (4A)
unnamed: U27.6 (2Y), U27.13 (4B)
unnamed: U29.3 (1Y), U29.9 (3A)
unnamed: U29.10 (3B), U29.11 (4Y), U30.5 (2B)
unnamed: U29.8 (3Y), U29.12 (4A), U30.1 (1A)
unnamed: U29.6 (2Y), U29.13 (4B)
unnamed: U30.3 (1Y), U30.9 (3A)
unnamed: U30.10 (3B), U30.11 (4Y)
unnamed: U30.6 (2Y), U30.13 (4B)
unnamed: U31.3 (1Y), U31.4 (2A), U31.10 (3B), U32.1 (1A), U32.2 (1B)
unnamed: U31.8 (3Y), U31.12 (4A)
unnamed: U31.6 (2Y), U31.13 (4B)
unnamed: U32.11 (4Y), U33.2 (1B)
unnamed: U32.8 (3Y), U32.12 (4A)
unnamed: U32.6 (2Y), U32.13 (4B)
unnamed: U34.3 (1Y), U34.9 (3A)
unnamed: U34.10 (3B), U34.11 (4Y), U35.5 (2B)
unnamed: U34.8 (3Y), U34.12 (4A), U35.1 (1A)
unnamed: U34.6 (2Y), U34.13 (4B)
unnamed: U35.3 (1Y), U35.9 (3A)
unnamed: U35.10 (3B), U35.11 (4Y)
unnamed: U35.6 (2Y), U35.13 (4B)
unnamed: U36.3 (1Y), U36.4 (2A), U36.10 (3B), U37.1 (1A), U37.2 (1B)
unnamed: U36.8 (3Y), U36.12 (4A)
unnamed: U36.6 (2Y), U36.13 (4B)
unnamed: U37.11 (4Y), U38.2 (1B)
unnamed: U37.8 (3Y), U37.12 (4A)
unnamed: U37.6 (2Y), U37.13 (4B)
unnamed: U39.3 (1Y), U39.9 (3A)
unnamed: U39.10 (3B), U39.11 (4Y), U40.5 (2B)
unnamed: U39.8 (3Y), U39.12 (4A), U40.1 (1A)
unnamed: U39.6 (2Y), U39.13 (4B)
unnamed: U40.3 (1Y), U40.9 (3A)
unnamed: U40.10 (3B), U40.11 (4Y)
unnamed: U40.6 (2Y), U40.13 (4B)
unnamed: U41.3 (1Y), U41.4 (2A), U41.10 (3B), U42.1 (1A), U42.2 (1B)
unnamed: U41.8 (3Y), U41.12 (4A)
unnamed: U41.6 (2Y), U41.13 (4B)
unnamed: U42.11 (4Y), U43.2 (1B)
unnamed: U42.8 (3Y), U42.12 (4A)
unnamed: U42.6 (2Y), U42.13 (4B)
unnamed: U44.3 (1Y), U44.9 (3A)
unnamed: U44.10 (3B), U44.11 (4Y), U45.5 (2B)
unnamed: U44.8 (3Y), U44.12 (4A), U45.1 (1A)
unnamed: U44.6 (2Y), U44.13 (4B)
unnamed: U45.3 (1Y), U45.9 (3A)
unnamed: U45.10 (3B), U45.11 (4Y)
unnamed: U45.6 (2Y), U45.13 (4B)
unnamed: U46.3 (1Y), U46.4 (2A), U46.10 (3B), U47.1 (1A), U47.2 (1B)
unnamed: U46.8 (3Y), U46.12 (4A)
unnamed: U46.6 (2Y), U46.13 (4B)
unnamed: U47.11 (4Y), U48.2 (1B)
unnamed: U47.8 (3Y), U47.12 (4A)
unnamed: U47.6 (2Y), U47.13 (4B)
unnamed: U49.3 (1Y), U49.9 (3A)
unnamed: U49.10 (3B), U49.11 (4Y), U50.5 (2B)
unnamed: U49.8 (3Y), U49.12 (4A), U50.1 (1A)
unnamed: U49.6 (2Y), U49.13 (4B)
unnamed: U50.3 (1Y), U50.9 (3A)
unnamed: U50.10 (3B), U50.11 (4Y)
unnamed: U50.6 (2Y), U50.13 (4B)
unnamed: U51.3 (1Y), U51.4 (2A), U51.10 (3B), U52.1 (1A), U52.2 (1B)
unnamed: U51.8 (3Y), U51.12 (4A)
unnamed: U51.6 (2Y), U51.13 (4B)
unnamed: U52.11 (4Y), U53.2 (1B)
unnamed: U52.8 (3Y), U52.12 (4A)
unnamed: U52.6 (2Y), U52.13 (4B)
unnamed: U54.3 (1Y), U54.9 (3A)
unnamed: U54.10 (3B), U54.11 (4Y), U55.5 (2B)
unnamed: U54.8 (3Y), U54.12 (4A), U55.1 (1A)
unnamed: U54.6 (2Y), U54.13 (4B)
unnamed: U55.3 (1Y), U55.9 (3A)
unnamed: U55.10 (3B), U55.11 (4Y)
unnamed: U55.6 (2Y), U55.13 (4B)
unnamed: U56.3 (1Y), U56.4 (2A), U56.10 (3B), U57.1 (1A), U57.2 (1B)
unnamed: U56.8 (3Y), U56.12 (4A)
unnamed: U56.6 (2Y), U56.13 (4B)
unnamed: U57.11 (4Y), U58.2 (1B)
unnamed: U57.8 (3Y), U57.12 (4A)
unnamed: U57.6 (2Y), U57.13 (4B)
unnamed: U59.3 (1Y), U59.9 (3A)
unnamed: U59.10 (3B), U59.11 (4Y), U60.5 (2B)
unnamed: U59.8 (3Y), U59.12 (4A), U60.1 (1A)
unnamed: U59.6 (2Y), U59.13 (4B)
unnamed: U60.3 (1Y), U60.9 (3A)
unnamed: U60.10 (3B), U60.11 (4Y)
unnamed: U60.6 (2Y), U60.13 (4B)
unnamed: U61.3 (1Y), U61.4 (2A), U61.10 (3B), U62.1 (1A), U62.2 (1B)
unnamed: U61.8 (3Y), U61.12 (4A)
unnamed: U61.6 (2Y), U61.13 (4B)
unnamed: U62.11 (4Y), U63.2 (1B)
unnamed: U62.8 (3Y), U62.12 (4A)
unnamed: U62.6 (2Y), U62.13 (4B)
unnamed: U64.3 (1Y), U64.9 (3A)
unnamed: U64.10 (3B), U64.11 (4Y), U65.5 (2B)
unnamed: U64.8 (3Y), U64.12 (4A), U65.1 (1A)
unnamed: U64.6 (2Y), U64.13 (4B)
unnamed: U65.3 (1Y), U65.9 (3A)
unnamed: U65.10 (3B), U65.11 (4Y)
unnamed: U65.6 (2Y), U65.13 (4B)
unnamed: U66.3 (1Y), U66.4 (2A), U66.10 (3B), U67.1 (1A), U67.2 (1B)
unnamed: U66.8 (3Y), U66.12 (4A)
unnamed: U66.6 (2Y), U66.13 (4B)
unnamed: U67.11 (4Y), U68.2 (1B)
unnamed: U67.8 (3Y), U67.12 (4A)
unnamed: U67.6 (2Y), U67.13 (4B)
unnamed: U69.3 (1Y), U69.9 (3A)
unnamed: U69.10 (3B), U69.11 (4Y), U70.5 (2B)
unnamed: U69.8 (3Y), U69.12 (4A), U70.1 (1A)
unnamed: U69.6 (2Y), U69.13 (4B)
unnamed: U70.3 (1Y), U70.9 (3A)
unnamed: U70.10 (3B), U70.11 (4Y)
unnamed: U70.6 (2Y), U70.13 (4B)
unnamed: U71.3 (1Y), U71.4 (2A), U71.10 (3B), U72.1 (1A), U72.2 (1B)
unnamed: U71.8 (3Y), U71.12 (4A)
unnamed: U71.6 (2Y), U71.13 (4B)
unnamed: U72.11 (4Y), U73.2 (1B)
unnamed: U72.8 (3Y), U72.12 (4A)
unnamed: U72.6 (2Y), U72.13 (4B)
unnamed: U74.3 (1Y), U74.9 (3A)
unnamed: U74.10 (3B), U74.11 (4Y), U75.5 (2B)
unnamed: U74.8 (3Y), U74.12 (4A), U75.1 (1A)
unnamed: U74.6 (2Y), U74.13 (4B)
unnamed: U75.3 (1Y), U75.9 (3A)
unnamed: U75.10 (3B), U75.11 (4Y)
unnamed: U75.6 (2Y), U75.13 (4B)
clk: U9.2 (1B), U9.4 (2A), U14.2 (1B), U14.4 (2A), U19.2 (1B), U19.4 (2A), U24.2 (1B), U24.4 (2A), U29.2 (1B), U29.4 (2A), U34.2 (1B), U34.4 (2A), U39.2 (1B), U39.4 (2A), U44.2 (1B), U44.4 (2A), U49.2 (1B), U49.4 (2A), U54.2 (1B), U54.4 (2A), U59.2 (1B), U59.4 (2A), U64.2 (1B), U64.4 (2A), U69.2 (1B), U69.4 (2A), U74.2 (1B), U74.4 (2A); also elsewhere on the board
in1: U72.10 (3B); also elsewhere on the board
in2: U67.10 (3B); also elsewhere on the board
in3: U62.10 (3B); also elsewhere on the board
in4: U57.10 (3B); also elsewhere on the board
in5: U52.10 (3B); also elsewhere on the board
in6: U47.10 (3B); also elsewhere on the board
in7: U42.10 (3B); also elsewhere on the board
in8: U37.10 (3B); also elsewhere on the board
in9: U32.10 (3B); also elsewhere on the board
in10: U27.10 (3B); also elsewhere on the board
in11: U22.10 (3B); also elsewhere on the board
in12: U17.10 (3B); also elsewhere on the board
in13: U12.10 (3B); also elsewhere on the board
in14: U7.10 (3B); also elsewhere on the board
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

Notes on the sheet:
D Flip Flop
SR Flip Flop
Half Adder The current register output is added to the carry in signal. Sum and carry-out signals are generated.
Mux between adder and load input.
AND the muxed input with Reset (Reset is active low)

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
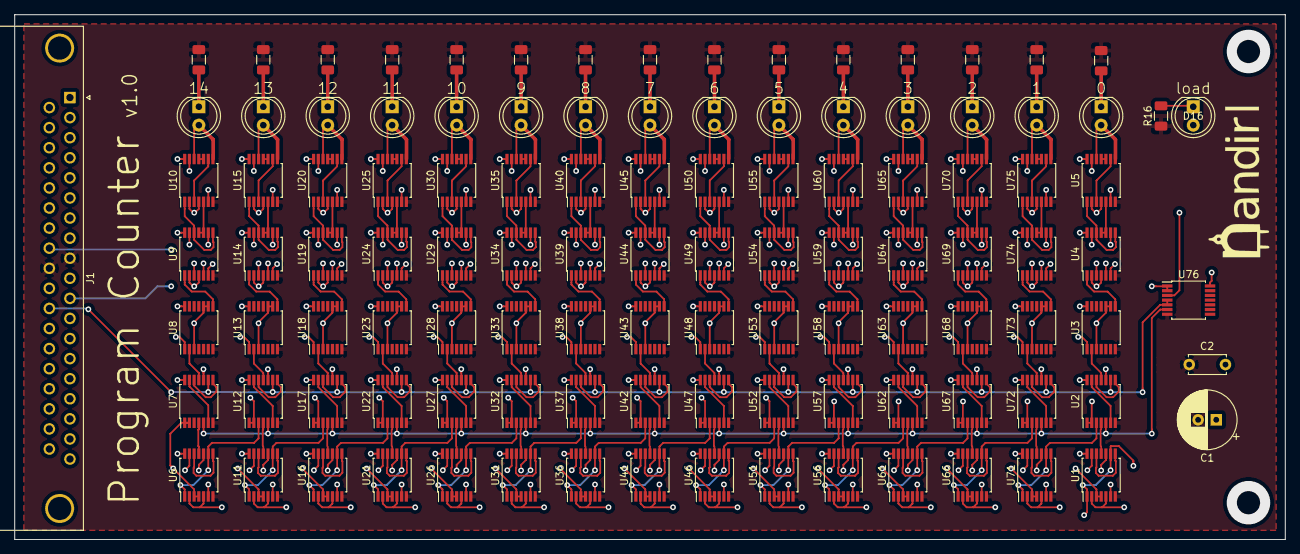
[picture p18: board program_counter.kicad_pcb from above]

Board: 4 copper layers, 175.3 x 72.4 mm, 111 parts (0 on the bottom side), 308 nets.

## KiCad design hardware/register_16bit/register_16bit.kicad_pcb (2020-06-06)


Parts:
C1: 100uF; CP_Radial_D8.0mm_P2.50mm; Digikey PN P15797CT-ND
C2: 100nF; C_Disc_D5.0mm_W2.5mm_P5.00mm; Digikey PN BC5229CT-ND
D1, D2, D3, D4, D5, D6, D7, D8, D9, D10, D11, D12, D13, D14, D15, D16, D17: LED; LED_D5.0mm
J1: DB37_Male; DSUB-37_Male_Horizontal_P2.77x2.84mm_EdgePinOffset7.70mm_Ho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; Digikey PN AE10986-ND
R1, R2, R3, R4, R5, R6, R7, R8, R9, R10, R11, R12, R13, R14, R15, R16, R17: 1K; R_1206_3216Metric; Digikey PN P1.0KECT-ND
U1: SN74HCS00PWR; TSSOP-14_4.4x5mm_P0.65mm; Digikey PN 296-SN74HCS00PWRCT-ND

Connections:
+3V3: C1.1, C2.1, J1.10, U1.14 (Vcc); also elsewhere on the board
GND: C1.2, C2.2, J1.9, J1.28, R1.1, R2.1, R3.1, R4.1, R5.1, R6.1, R7.1, R8.1, R9.1, R10.1, R11.1, R12.1, R13.1, R14.1, R15.1, R16.1, R17.1, U1.7 (GND); also elsewhere on the board
unnamed: D1.1 (K), R1.2
unnamed: D2.1 (K), R2.2
unnamed: D3.1 (K), R3.2
unnamed: D4.1 (K), R4.2
unnamed: D5.1 (K), R5.2
unnamed: D6.1 (K), R6.2
unnamed: D7.1 (K), R7.2
unnamed: D8.1 (K), R8.2
unnamed: D9.1 (K), R9.2
unnamed: D10.1 (K), R10.2
unnamed: D11.1 (K), R11.2
unnamed: D12.1 (K), R12.2
unnamed: D13.1 (K), R13.2
unnamed: D14.1 (K), R14.2
unnamed: D15.1 (K), R15.2
unnamed: D16.1 (K), R16.2
unnamed: D17.1 (K), R17.2
clk: J1.37, U1.1 (1A), U1.2 (1B); also elsewhere on the board
in0: J1.18; also elsewhere on the board
in1: J1.36; also elsewhere on the board
in2: J1.17; also elsewhere on the board
in3: J1.35; also elsewhere on the board
in4: J1.16; also elsewhere on the board
in5: J1.34; also elsewhere on the board
in6: J1.15; also elsewhere on the board
in7: J1.33; also elsewhere on the board
in8: J1.14; also elsewhere on the board
in9: J1.32; also elsewhere on the board
in10: J1.13; also elsewhere on the board
in11: J1.31; also elsewhere on the board
in12: J1.12; also elsewhere on the board
in13: J1.30; also elsewhere on the board
in14: J1.11; also elsewhere on the board
in15: J1.29; also elsewhere on the board
load: D17.2 (A), J1.19, U1.4 (2A), U1.5 (2B); also elsewhere on the board
not_clk: U1.3 (1Y); also elsewhere on the board
not_load: U1.6 (2Y); also elsewhere on the board
out0: D1.2 (A), J1.1; also elsewhere on the board
out1: D2.2 (A), J1.20; also elsewhere on the board
out2: D3.2 (A), J1.2; also elsewhere on the board
out3: D4.2 (A), J1.21; also elsewhere on the board
out4: D5.2 (A), J1.3; also elsewhere on the board
out5: D6.2 (A), J1.22; also elsewhere on the board
out6: D7.2 (A), J1.4; also elsewhere on the board
out7: D8.2 (A), J1.23; also elsewhere on the board
out8: D9.2 (A), J1.5; also elsewhere on the board
out9: D10.2 (A), J1.24; also elsewhere on the board
out10: D11.2 (A), J1.6; also elsewhere on the board
out11: D12.2 (A), J1.25; also elsewhere on the board
out12: D13.2 (A), J1.7; also elsewhere on the board
out13: D14.2 (A), J1.26; also elsewhere on the board
out14: D15.2 (A), J1.8; also elsewhere on the board
out15: D16.2 (A), J1.27; also elsewhere on the board

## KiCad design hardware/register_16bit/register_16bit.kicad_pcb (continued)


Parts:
U47, U48, U49: SN74HCS00PWR; TSSOP-14_4.4x5mm_P0.65mm; Digikey PN 296-SN74HCS00PWRCT-ND

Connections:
+3V3: U47.14 (Vcc), U48.14 (Vcc), U49.14 (Vcc); also elsewhere on the board
GND: U47.7 (GND), U48.7 (GND), U49.7 (GND); also elsewhere on the board
unnamed: U47.3 (1Y), U47.9 (3A)
unnamed: U47.6 (2Y), U47.10 (3B)
unnamed: U47.11 (4Y), U48.5 (2B)
unnamed: U47.8 (3Y), U47.12 (4A), U47.13 (4B), U48.1 (1A)
unnamed: U48.3 (1Y), U48.9 (3A)
unnamed: U48.10 (3B), U48.11 (4Y), U49.5 (2B)
unnamed: U48.8 (3Y), U48.12 (4A), U49.1 (1A)
unnamed: U48.6 (2Y), U48.13 (4B)
unnamed: U49.3 (1Y), U49.9 (3A)
unnamed: U49.10 (3B), U49.11 (4Y)
unnamed: U49.6 (2Y), U49.13 (4B)
clk: U48.2 (1B), U48.4 (2A); also elsewhere on the board
in0: U47.5 (2B); also elsewhere on the board
load: U47.4 (2A); also elsewhere on the board
not_clk: U49.2 (1B), U49.4 (2A); also elsewhere on the board
not_load: U47.2 (1B); also elsewhere on the board
out0: U47.1 (1A), U49.8 (3Y), U49.12 (4A); also elsewhere on the board

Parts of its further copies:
U2, U3, U4, U5, U6, U7, U8, U9, U10, U11, U12, U13, U14, U15, U16, U17, U18, U19, U20, U21, U22, U23, U24, U25, U26, U27, U28, U29, U30, U31, U32, U33, U34, U35, U36, U37, U38, U39, U40, U41, U42, U43, U44, U45, U46: SN74HCS00PWR; TSSOP-14_4.4x5mm_P0.65mm; Digikey PN 296-SN74HCS00PWRCT-ND

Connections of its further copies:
+3V3: U2.14 (Vcc), U3.14 (Vcc), U4.14 (Vcc), U5.14 (Vcc), U6.14 (Vcc), U7.14 (Vcc), U8.14 (Vcc), U9.14 (Vcc), U10.14 (Vcc), U11.14 (Vcc), U12.14 (Vcc), U13.14 (Vcc), U14.14 (Vcc), U15.14 (Vcc), U16.14 (Vcc), U17.14 (Vcc), U18.14 (Vcc), U19.14 (Vcc), U20.14 (Vcc), U21.14 (Vcc), U22.14 (Vcc), U23.14 (Vcc), U24.14 (Vcc), U25.14 (Vcc), U26.14 (Vcc), U27.14 (Vcc), U28.14 (Vcc), U29.14 (Vcc), U30.14 (Vcc), U31.14 (Vcc), U32.14 (Vcc), U33.14 (Vcc), U34.14 (Vcc), U35.14 (Vcc), U36.14 (Vcc), U37.14 (Vcc), U38.14 (Vcc), U39.14 (Vcc), U40.14 (Vcc), U41.14 (Vcc), U42.14 (Vcc), U43.14 (Vcc), U44.14 (Vcc), U45.14 (Vcc), U46.14 (Vcc); also elsewhere on the board
GND: U2.7 (GND), U3.7 (GND), U4.7 (GND), U5.7 (GND), U6.7 (GND), U7.7 (GND), U8.7 (GND), U9.7 (GND), U10.7 (GND), U11.7 (GND), U12.7 (GND), U13.7 (GND), U14.7 (GND), U15.7 (GND), U16.7 (GND), U17.7 (GND), U18.7 (GND), U19.7 (GND), U20.7 (GND), U21.7 (GND), U22.7 (GND), U23.7 (GND), U24.7 (GND), U25.7 (GND), U26.7 (GND), U27.7 (GND), U28.7 (GND), U29.7 (GND), U30.7 (GND), U31.7 (GND), U32.7 (GND), U33.7 (GND), U34.7 (GND), U35.7 (GND), U36.7 (GND), U37.7 (GND), U38.7 (GND), U39.7 (GND), U40.7 (GND), U41.7 (GND), U42.7 (GND), U43.7 (GND), U44.7 (GND), U45.7 (GND), U46.7 (GND); also elsewhere on the board
unnamed: U2.3 (1Y), U2.9 (3A)
unnamed: U2.6 (2Y), U2.10 (3B)
unnamed: U2.11 (4Y), U3.5 (2B)
unnamed: U2.8 (3Y), U2.12 (4A), U2.13 (4B), U3.1 (1A)
unnamed: U3.3 (1Y), U3.9 (3A)
unnamed: U3.10 (3B), U3.11 (4Y), U4.5 (2B)
unnamed: U3.8 (3Y), U3.12 (4A), U4.1 (1A)
unnamed: U3.6 (2Y), U3.13 (4B)
unnamed: U4.3 (1Y), U4.9 (3A)
unnamed: U4.10 (3B), U4.11 (4Y)
unnamed: U4.6 (2Y), U4.13 (4B)
unnamed: U5.3 (1Y), U5.9 (3A)
unnamed: U5.6 (2Y), U5.10 (3B)
unnamed: U5.11 (4Y), U6.5 (2B)
unnamed: U5.8 (3Y), U5.12 (4A), U5.13 (4B), U6.1 (1A)
unnamed: U6.3 (1Y), U6.9 (3A)
unnamed: U6.10 (3B), U6.11 (4Y), U7.5 (2B)
unnamed: U6.8 (3Y), U6.12 (4A), U7.1 (1A)
unnamed: U6.6 (2Y), U6.13 (4B)
unnamed: U7.3 (1Y), U7.9 (3A)
unnamed: U7.10 (3B), U7.11 (4Y)
unnamed: U7.6 (2Y), U7.13 (4B)
unnamed: U8.3 (1Y), U8.9 (3A)
unnamed: U8.6 (2Y), U8.10 (3B)
unnamed: U8.11 (4Y), U9.5 (2B)
unnamed: U8.8 (3Y), U8.12 (4A), U8.13 (4B), U9.1 (1A)
unnamed: U9.3 (1Y), U9.9 (3A)
unnamed: U9.6 (2Y), U9.13 (4B)
unnamed: U9.8 (3Y), U9.12 (4A), U10.1 (1A)
unnamed: U10.3 (1Y), U10.9 (3A)
unnamed: U9.10 (3B), U9.11 (4Y), U10.5 (2B)
unnamed: U10.10 (3B), U10.11 (4Y)
unnamed: U10.6 (2Y), U10.13 (4B)
unnamed: U11.3 (1Y), U11.9 (3A)
unnamed: U11.6 (2Y), U11.10 (3B)
unnamed: U11.11 (4Y), U12.5 (2B)
unnamed: U11.8 (3Y), U11.12 (4A), U11.13 (4B), U12.1 (1A)
unnamed: U12.3 (1Y), U12.9 (3A)
unnamed: U12.10 (3B), U12.11 (4Y), U13.5 (2B)
unnamed: U12.8 (3Y), U12.12 (4A), U13.1 (1A)
unnamed: U12.6 (2Y), U12.13 (4B)
unnamed: U13.3 (1Y), U13.9 (3A)
unnamed: U13.10 (3B), U13.11 (4Y)
unnamed: U13.6 (2Y), U13.13 (4B)
unnamed: U14.3 (1Y), U14.9 (3A)
unnamed: U14.6 (2Y), U14.10 (3B)
unnamed: U14.11 (4Y), U15.5 (2B)
unnamed: U14.8 (3Y), U14.12 (4A), U14.13 (4B), U15.1 (1A)
unnamed: U15.3 (1Y), U15.9 (3A)
unnamed: U15.10 (3B), U15.11 (4Y), U16.5 (2B)
unnamed: U15.8 (3Y), U15.12 (4A), U16.1 (1A)
unnamed: U15.6 (2Y), U15.13 (4B)
unnamed: U16.3 (1Y), U16.9 (3A)
unnamed: U16.10 (3B), U16.11 (4Y)
unnamed: U16.6 (2Y), U16.13 (4B)
unnamed: U17.3 (1Y), U17.9 (3A)
unnamed: U17.6 (2Y), U17.10 (3B)
unnamed: U17.11 (4Y), U18.5 (2B)
unnamed: U17.8 (3Y), U17.12 (4A), U17.13 (4B), U18.1 (1A)
unnamed: U18.3 (1Y), U18.9 (3A)
unnamed: U18.10 (3B), U18.11 (4Y), U19.5 (2B)
unnamed: U18.8 (3Y), U18.12 (4A), U19.1 (1A)
unnamed: U18.6 (2Y), U18.13 (4B)
unnamed: U19.3 (1Y), U19.9 (3A)
unnamed: U19.10 (3B), U19.11 (4Y)
unnamed: U19.6 (2Y), U19.13 (4B)
unnamed: U20.3 (1Y), U20.9 (3A)
unnamed: U20.6 (2Y), U20.10 (3B)
unnamed: U20.11 (4Y), U21.5 (2B)
unnamed: U20.8 (3Y), U20.12 (4A), U20.13 (4B), U21.1 (1A)
unnamed: U21.3 (1Y), U21.9 (3A)
unnamed: U21.10 (3B), U21.11 (4Y), U22.5 (2B)
unnamed: U21.8 (3Y), U21.12 (4A), U22.1 (1A)
unnamed: U21.6 (2Y), U21.13 (4B)
unnamed: U22.3 (1Y), U22.9 (3A)
unnamed: U22.10 (3B), U22.11 (4Y)
unnamed: U22.6 (2Y), U22.13 (4B)
unnamed: U23.3 (1Y), U23.9 (3A)
unnamed: U23.6 (2Y), U23.10 (3B)
unnamed: U23.11 (4Y), U24.5 (2B)
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

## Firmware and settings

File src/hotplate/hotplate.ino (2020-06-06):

#include "max6675.h"

// Pin definitions
#define PIN_MISO 12
#define PIN_SCK 13
#define PIN_CS 10
#define PIN_COOL 6
#define PIN_HEAT 4

// Temperature hold temp
#define TEMP_HOLD_F 505.0f

// Time interval in ms
#define DT_MSEC 1000

// Temperature low-pass filter gain
#define TEMP_FILT_K 0.3f

// PD gains for heating and cooling
#define KP_HEAT 0.0f
#define KD_HEAT 0.0f
#define KP_COOL 0.0f
#define KD_COOL 0.0f

// Measured temperature rates for full heat or full cool
// These are used in the temp rate feed-forward component of the controller
#define HEAT_FPS_T0 3.0f  // Measured temp rate for full heat at temp T0
#define HEAT_FPS_T1 0.5f  // Measured temp rate for full heat at temp T1
#define COOL_FPS_T0 0.5f  // Measured temp rate for full cool at temp T0
#define COOL_FPS_T1 3.0f  // Measured temp rate for full cool at temp T1
#define T0_F 100.f        // Temperature point T0
#define T1_F 500.f        // Temperature point T1

// Profile 0: Chip Quik TS391SNL50 paste
// http://www.chipquik.com/datasheets/TS391SNL50.pdf
float profile0_time[]={0.f,90.f,180.f,210.f,240.f,270.f,450.f};
float profile0_temp[]={77.f,302.f,347.f,423.f,480.f,423.f,80.f};
unsigned profile0_n = 7;

float profile1_time[]={0.f,1200.f};
float profile1_temp[]={TEMP_HOLD_F,TEMP_HOLD_F};
unsigned profile1_n = 2;

// Time globals
const float DT_SEC = (float)DT_MSEC/1000.0f;  // time interval (sec)
unsigned long next_wakeup_ms = 0;             // Next millis() time to wakeup
float t_sec = 0.0f;                           // Current time into profile (sec)

// Profile globals
float * profile_time;   // Pointer to the selected profile time
float * profile_temp;   // Pointer to the selected profile temp (F)
unsigned profile_n;     // Length of the selected profile
unsigned profile_step = 0; // Current profile step

// MAX6675 K-type thermocouple sensor
MAX6675 ktc(PIN_SCK, PIN_CS, PIN_MISO);

// Thermocouple temperature globals
float temp_filt_F = 0.0f;      // Filtered temperature reading (F)
float last_temp_filt_F = 0.0f; // Saved last filter temp reading (F)
float temp_inst_F = 0.0f;      // Instantaneous temperature reading (F)
float dtemp_Fps = 0.0f;        // Temperature rate of change (F/sec)s

// Temp setpoint globals
float temp_setpoint_F = 80.f;    // Current commanded temperature (F)
float dtemp_setpoint_Fps = 0.f;  // Current commanded temp rate of change (F/sec)

// Heating/cooling commands
float heat_dutycycle = 0.f;
float cool_dutycycle = 0.f;
unsigned long next_turnoff_ms = 0;

// Function to turn heater on/off
// Turn heater on:  set_heater(1)
// Turn heater off: set_heater(0)
void set_heater( uint8_t on ){
    digitalWrite( PIN_HEAT, on);
}
// Same for cooler
void set_cooler( uint8_t on ){
    digitalWrite( PIN_COOL, on);
}

// Function that reads the current thermocouple temperature
// Updates instantaneous temp, filtered temp, and temp rate of change
void read_temp(){
  temp_inst_F = ktc.readFahrenheit();
  temp_filt_F += (temp_inst_F - temp_filt_F)*TEMP_FILT_K*DT_SEC;
  dtemp_Fps = (temp_filt_F - last_temp_filt_F)/DT_SEC;
  last_temp_filt_F = temp_filt_F;
}

// Function that uses the current time to interpolate profile temp command
// Also calculates the temperate rate of change for the current profile segment
// Sets globals for temp command and temp rate of change command
void update_profile_setpoint(){
  
  // Check if it's time to update the profile step
  if (profile_step < profile_n - 2)
  {
    if( t_sec >= profile_time[profile_step+1]){
      profile_step++;
    }
  }

  // Check if profile is complete
  if( t_sec >= profile_time[profile_n-1] ){
    dtemp_setpoint_Fps = 0.f;
    temp_setpoint_F = profile_temp[profile_n-1];
    return;
  }

  // Calculate temperature rate for this step
  dtemp_setpoint_Fps = (profile_temp[profile_step+1] - profile_temp[profile_step])/(profile_time[profile_step+1] - profile_time[profile_step]);

  // Interpolate temperature command
  temp_setpoint_F = profile_temp[profile_step] + dtemp_setpoint_Fps*(t_sec-profile_time[profile_step]);
}

// Function that sets heating or cooling control outputs
// Calculates temperature and temperature rate errors, runs PID controller
// Sets duty cycles for heating or cooling control outputs by turning the
// device output on and setting the turn-off time.
void do_control(){
  // Check if profile complete
  if( profile_step == profile_n - 1 ){
    set_heater(0);
    set_cooler(0);
    return;
  }

  float duty_cycle;

  bool mode_heating;
  if( dtemp_setpoint_Fps >= 0.f ){
    // Heating mode
    mode_heating = true;
    // Calculate the feed-forward command based on empirically-measure temp rates.
    // This interpolates between HEAT_FPS_T0 and HEAT_FPS_T1 based on where the current
    // temp falls between T0 and T1. The result is the expected temp rate
    // if you applied full heat at the current temperature. This is used as the
    // feed-forward command applied to the current temp rate error.
    float fullheat_Fps;
    if( temp_filt_F < T0_F ){
      fullheat_Fps = HEAT_FPS_T0;
    }else if ( temp_filt_F >= T1_F ){
      fullheat_Fps = HEAT_FPS_T1;
    }else{
      // Interpolate between HEAT_FPS_T0 and HEAT_FPS_T1
      fullheat_Fps = HEAT_FPS_T0 + (temp_filt_F-T0_F)*(HEAT_FPS_T1-HEAT_FPS_T0)/(T1_F-T0_F);
    }
    // Controller: Feed-forward + proportional + derivative
    duty_cycle = fullheat_Fps * dtemp_setpoint_Fps + KD_HEAT * (dtemp_setpoint_Fps - dtemp_Fps) + KP_HEAT * (temp_setpoint_F - temp_filt_F);

  }else{
    // Cooling mode
    mode_heating = false;

    // Same as above, but with parameters and gains for cooling
    float fullcool_Fps;
    if( temp_filt_F < T0_F ){
      fullcool_Fps = COOL_FPS_T0;
    }else if ( temp_filt_F >= T1_F ){
      fullcool_Fps = COOL_FPS_T1;
    }else{
      // Interpolate between COOL_FPS_T0 and COOL_FPS_T1
      fullcool_Fps = COOL_FPS_T0 + (temp_filt_F-T0_F)*(COOL_FPS_T1-COOL_FPS_T0)/(T1_F-T0_F);
    }
    // Controller: Feed-forward + proportional + derivative
    // Sign is flipped because cooling actuates in the opposite direction
    duty_cycle = -1.0f * (fullcool_Fps * dtemp_setpoint_Fps + KD_COOL * (dtemp_setpoint_Fps - dtemp_Fps) + KP_COOL * (temp_setpoint_F - temp_filt_F));
  }

  // If duty cycle less than threshold, turn off heating/cooling
  if( duty_cycle < 0.05f ){
    set_heater(0);
    set_cooler(0);
    
    return;
  }

  // Set turn-off time based on dutycycle
  next_turnoff_ms = duty_cycle * DT_SEC * 1000.f;
  next_turnoff_ms += millis();

  // Turn on heating or cooling
  heat_dutycycle = 0.f;
  cool_dutycycle = 0.f;
  if( mode_heating ){
    heat_dutycycle = duty_cycle;
    set_heater(1);
  }else{
    cool_dutycycle = duty_cycle;
    set_cooler(1);
  }  
}

// Function that performs system ID actuator profile
// Full heat until filtered temp = 500F
// Full cool until filtered temp = 120F
bool mode_heat = true;
bool done = false;
void do_sysID(){
  if(done){
    set_heater(0);
    set_cooler(0);
    heat_dutycycle=0.0f;
    cool_dutycycle=0.0f;
    return;
  }
  // Setpoint 450F gets board to 425F
  if(mode_heat){
    if(temp_filt_F >= 120.f){
      mode_heat = false;
    }
    set_heater(1);
    set_cooler(0);
    heat_dutycycle=1.0f;
    cool_dutycycle=0.0f;
  }else{
    if(temp_filt_F <= 120.f){
      done = true;
    }
    set_heater(0);
    set_cooler(1);
    heat_dutycycle=0.0f;
    cool_dutycycle=1.0f;
  }

  // Set turn-off time based on dutycycle
  float duty_cycle = 1.f;
  next_turnoff_ms = duty_cycle * DT_SEC * 1000.f;
  next_turnoff_ms += millis();
  
}

void temp_hold(){
  set_cooler(0);
  if( temp_filt_F > TEMP_HOLD_F ){
    set_heater(0);
    heat_dutycycle=0.0f;
    cool_dutycycle=0.0f;
  }else{
    set_heater(1);
    heat_dutycycle=1.0f;
    cool_dutycycle=0.0f;
  }
  // Set turn-off time based on dutycycle
  float duty_cycle = 1.f;
  next_turnoff_ms = duty_cycle * DT_SEC * 1000.f;
  next_turnoff_ms += millis();
}

// Function to send a heartbeat to host computer so that profile can be plotted or logged
// Data format: 
// "[t_sec], [temp_inst_F], [temp_filt_F], [dtemp_Fps], [temp_setpoint_F], [dtemp_setpoint_Fps], [heat_dutycycle], [cool_dutycycle];"
void heartbeat(){
  Serial.print(t_sec);Serial.print(",");
  Serial.print(temp_inst_F);Serial.print(",");
  Serial.print(temp_filt_F);Serial.print(",");
  Serial.print(dtemp_Fps);Serial.print(",");
  Serial.print(temp_setpoint_F);Serial.print(",");
  Serial.print(dtemp_setpoint_Fps);Serial.print(",");
  Serial.print(heat_dutycycle);Serial.print(",");
  Serial.print(cool_dutycycle);Serial.print(";");
}
  
void setup() {
  // Set heater/cool output directions and turn both off
  pinMode(PIN_HEAT, OUTPUT);
  set_heater(0);
  pinMode(PIN_COOL, OUTPUT);
  set_cooler(0);
  
  // Start serial
  Serial.begin(9600);
  
  // Wait for a profile to be selected
  while(true){
    if(Serial.available()){
      char ch = Serial.read();
      if( ch =='0' ){
        profile_time = profile0_time;
        profile_temp = profile0_temp;
        profile_n = profile0_n;
        break;
      }else if( ch=='1' ){
        profile_time = profile1_time;
        profile_temp = profile1_temp;
        profile_n = profile1_n;
        break;
      }
    }
    delay(10);
  }

  // Initialize filtered temperature to current reading
  temp_filt_F = ktc.readFahrenheit();
  last_temp_filt_F = temp_filt_F;
}

void loop() {
  // Check if it's time to wakeup
  if( millis() > next_wakeup_ms ){
    next_wakeup_ms = millis() + DT_MSEC;
    t_sec += DT_SEC;
    read_temp();
    update_profile_setpoint();
    //do_control();
    //do_sysID();
    temp_hold();
    heartbeat();
  }

  // Check if it's time to turn the heating/cooling controls off
  if( millis() > next_turnoff_ms ){
    set_heater(0);
    set_cooler(0);
  }
}

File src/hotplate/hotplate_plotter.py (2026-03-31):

import matplotlib.pyplot as plt
import serial
import threading
import time

# Setup serial port and data
ser = serial.Serial('/dev/ttyUSB0')
data = {'t_sec':[], 'temp_inst_F':[], 'temp_filt_F':[], 'dtemp_Fps':[], 'temp_setpoint_F':[], 'dtemp_setpoint_Fps':[], 'heat_dutycycle':[], 'cool_dutycycle':[]}
ax_temp = plt.subplot(3,1,1)
temp_inst, = ax_temp.plot([],[],color='orange',label='Inst. Temp (F)')
temp_filt, = ax_temp.plot([],[],'r-',label='Filt. Temp (F)')
temp_sp, = ax_temp.plot([],[],'k--',label='Temp Setpoint (F)')
ax_temp.set_xlabel('Time (sec)')
ax_temp.set_ylabel('Temperature (F)')
ax_temp.grid()
ax_temp.legend()

ax_dtemp = plt.subplot(3,1,2, sharex=ax_temp)
dtemp, = ax_dtemp.plot([],[],'r-',label='dTemp/dt (F/sec)')
dtemp_sp, = ax_dtemp.plot([],[],'k--',label='dTemp/dt Setpoint (F/sec)')
ax_dtemp.set_xlabel('Time (sec)')
ax_dtemp.set_ylabel('Temperature Rate (F/sec)')
ax_dtemp.grid()
ax_dtemp.legend()

ax_dc = plt.subplot(3,1,3, sharex=ax_temp)
heat, = ax_dc.plot([],[],'r-',label='Heating Dutycycle')
cool, = ax_dc.plot([],[],'b--',label='Cooling Dutycycle')
ax_dc.set_xlabel('Time (sec)')
ax_dc.set_ylabel('Duty Cycle (%)')
ax_dc.grid()
ax_dc.legend()

cnt=0
def draw_plots():
    global cnt
    temp_inst.set_xdata(data['t_sec'])
    temp_inst.set_ydata(data['temp_inst_F'])
    temp_filt.set_xdata(data['t_sec'])
    temp_filt.set_ydata(data['temp_filt_F'])
    temp_sp.set_xdata(data['t_sec'])
    temp_sp.set_ydata(data['temp_setpoint_F'])
    ax_temp.set_xlim(0, max(60,max(data['t_sec'])+10))
    #ax_temp.set_ylim(min(data['temp_setpoint_F'])-20, max(data['temp_setpoint_F'])+20)
    ax_temp.set_ylim(250, 550)
    
    dtemp.set_xdata(data['t_sec'])
    dtemp.set_ydata(data['dtemp_Fps'])
    dtemp_sp.set_xdata(data['t_sec'])
    dtemp_sp.set_ydata(data['dtemp_setpoint_Fps'])
    ax_dtemp.set_xlim(0, max(60,max(data['t_sec'])+10))
    ax_dtemp.set_ylim(-1, 1)

    heat.set_xdata(data['t_sec'])
    heat.set_ydata(data['heat_dutycycle'])
    cool.set_xdata(data['t_sec'])
    cool.set_ydata(data['cool_dutycycle'])
    ax_dc.set_xlim(0, max(60,max(data['t_sec'])+10))
    ax_dc.set_ylim(-5, 105)

    plt.draw()

    cnt+=1
    if cnt%10 == 0:
        plt.savefig('profile.png')

def ser_listen():
    inbuf = ''
    while True:
        ch = ser.read().decode('utf-8')
        if ch == ';':
            sp = inbuf.split(',')
            if len(sp) == 8:
                data['t_sec'].append(float(sp[0]))
                data['temp_inst_F'].append(float(sp[1]))
                data['temp_filt_F'].append(float(sp[2]))
                data['dtemp_Fps'].append(float(sp[3]))
                data['temp_setpoint_F'].append(float(sp[4]))
                data['dtemp_setpoint_Fps'].append(float(sp[5]))
                data['heat_dutycycle'].append(float(sp[6])*100.0)
                data['cool_dutycycle'].append(float(sp[7])*100.0)
                draw_plots()
            inbuf = ''
        else:
            inbuf += ch

th = threading.Thread(target=ser_listen)
th.daemon = True
th.start()

time.sleep(3)
ser.write('1'.encode())

plt.show()

while True:
    time.sleep(1)

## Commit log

2020-04-04 Part imports (#1)
    * Schematic capture of 1-bit register based on DFF and SRFF. Initial creation of 16-bit register hierarchical schematic.
    * Finished initial PCB layout and routing for 16-bit register.
    * Added clock generator, tested on breadboard. Added motherboard, routing unfinished. Various component updates.
    * Motherboard fully routed, PCB layout done. README updated.
    [CPU_logic.sch, Mux_16bit.sch, clock_generator.kicad_pcb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]
2020-04-05 Program counter (#2)
    * Schematic and layout for Program Counter complete.
    * Small routing mods
    * Fix README
    [PC_input.sch, program_counter.kicad_pcb, program_counter.sch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]
2020-04-07 Rom (#3)
    * Updated motherboard with ROM OE,WE, and additional address pins
    * ROM schematic, layout, routing complete.
    [motherboard.kicad_pcb, motherboard.sch, register_1bit.sch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]
2020-04-07 Flipped clk A and clk B based on timing plan. (#4)
    [clock_generator.kicad_pcb, clock_generator.sch]
2020-04-21 Ram (#5)
    * Flipped clk A and B based on timing diagram. Added output buffers for clock signals.
    * Added clock output enable signal to motherboard debugger. Updated component library.
    * Schematic and layout for RAM board complete.
    * ALU schematic complete, ready for layout and routing.
    * ALU layout, routing complete. Associated motherboard mod.
    * Added Load LED to register and program counter boards.
    [Add16.sch, Add4.sch, And16.sch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]
2020-04-22 Readme updates (#6)
    * Readme intro section
    * Board revisions for manufacturing, add digikey PNs to all, added logo.
    [Add4.sch, CPU_logic.sch, Dlatch_16bit.sch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]
2020-04-23 Created gerbers for first board run.
    [clock_generator-B_Cu.gbr, clock_generator-B_Mask.gbr, clock_generator-B_Paste.gbr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]
2020-06-06 Readme (#7)
    * update
    * Added debugger, schematic and pcb complete.
    * lots of updates
    * All boards as fabbed at v1.0
    [Add16.sch, Add4.sch, And16.sch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]
2020-06-06 Motherboard: Added power switch, moved reset switch, modified silkscreens for readability, fixed A-register connector pinout, grounded NC input pins, changed paste layer clearance to -0.05mm (#8)
    [Mux_16bit.sch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]
2020-06-08 Ram updates (#9)
    * RAM board rework complete. Added COTS latch chips and Teensy 4.1 peripheral + magjack for ethernet.
    * Schematic cleanup
    [Dlatch_16bit.sch, TeensyPeripheral.sch, bom_ram.csv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]
2020-06-08 Debugger updates (#10)
    * Debugger updated to Teensy 4.1 with magjack for ethernet. Updated motherboard<>debugger pinout to include 3.3v source
    * Added 2 mils extra clearance for paste layer
    * cleanup
    [debugger-B_Cu.gbr, debugger-B_Mask.gbr, debugger-B_Paste.gbr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]
